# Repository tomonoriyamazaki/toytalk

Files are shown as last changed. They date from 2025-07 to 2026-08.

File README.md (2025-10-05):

# toytalk
SS Bootcamp 3rd #2025

## プロジェクト
- 声をかけると返答してくれるAIおもちゃの作成
- 目的は親の時間確保
- 子供がおもちゃに夢中になると同時に、言葉のキャッチボール力の向上もできたらうれしい
- OpenAIのAPIを利用するため、会話のたびに料金が発生する
- APIキーを発行してセットすれば、課金分のみの利用が可能
- APIキーの設定が面倒であれば、月額課金でも利用できる
- 無料で使用することも可能。会話はできないが、ただおうむ返しをしたり、事前にセットした昔話を話してくれる、という機能もあると親としては助かる（実際はサーバー維持費用かかるので検討中）
- おもちゃイメージ　「まねっこぴょこぴょこアンパンマン」
  - https://www.amazon.co.jp/gp/product/B0B4RQ85ZQ/ref=sw_img_1?smid=AN1VRQENFRJN5&th=1

## 音声会話のしくみ
  1. STT（音声→テキスト）
  2. LLM
  3. TTS（テキスト→音声）

前提として
  - OpenAIのAPIキーが必要。API利用のたびに課金が発生する
  - 音声処理はスマホ側で行うため、スマホアプリが必要。課金状況の確認などもアプリで行う

## PJの流れ
- デモサイト構築：マイク→音声→テキスト→LLM→音声返答してくれるサイトを作る　→6月完了
- ラズパイに落とし込む　→7月完了
- スマホアプリを作って、スマホと連動させる
- おもちゃとしてデザインを決めて形にする
- →一旦ここまで出来たらうれしい

サービス化するなら
- 何よりも応答速度が課題：デモサイト上では1往復で5秒前後かかる。すべての処理が直列なのと、サーバーレス構成のためと思われる　→　一旦解決。初回応答まで安定して2秒程度に短縮できた。しかもサーバーレス
  - STT：ここが足を引っ張っているように感じる。websocket通信で高速化できないか検討中　※ここをブラウザのテキスト化機能にしたら（つまりSSTをなくしたら）、往復で1-4秒と速度アップした
  - LLM：4.1-miniを利用。かなり早いはず
  - TTS：回答内容をまとめてmp3にしている？ためか長文だと時間かかるように感じる。子供向けということで、LLMの回答内容をシンプルにすることで短縮できないか
  - ※最悪難しかったら、待ってる間に「相槌を打つ」機能の追加を検討。「そうだね～」、「なるほどね」、「ふむふむ」とかいろいろなパターンを使って時間を稼げないか検討
  - →OpenAIのRealTime APIを使えば、SST→LLM→TTSをリアルタイム&並列化できるため爆速になる。ただ、これには2つのデメリットがある
    - 利用料が高い
    - ボイスをカスタマイズ（キャラクター化）できない
  - この対策として、以下が考えられる
    - STT、LLM、TTSそれぞれ、Stream対応のAPIを利用して、自前でWebRTC環境を整備する
    - TTS（ボイス化）についてはさらにカスタマイズできるものを選ぶ　※Microsoft EdgeTTSが有力
    - 一方で開発が長引く可能性が高いので、どこまで対応するか線引きが必要になりそう
    - 一旦、動作が安定してる現状のサーバーレス構成で進めて、RealTime API利用など検証しつつ落としどころを探る
  - 20250901：速度問題は一旦解決。サーバーレス構成（Lambda）でも、LLM/TTSをストリーム処理することで、話初めの速度を改善できた。STTは現在スマホ側で処理しているので、スマホによって性能の差がある可能性あり
  - 20251005：STTも解決。Soniox STTで一時キーを発行することで、クライアント⇔Soniox間で直接やり取りする。認証は別途必要だが速度には大きく影響しない想定。これで、STT→LLM→TTSの並列化ができ、応答も2秒程度となった
- 音声の精度を高める（くしゃみとか物音も拾ってしまう）　→　スマホでなら問題なし。くしゃみとかキーボードなら拾わない
- アプリ上で課金管理をできるようにする
- 過去の会話を踏まえて会話する機能。3-5つくらいまで保持しして、あとは要約するとか工夫できないか（会話積み重ねると重くなる）　→　実装済み
- APIキー管理の仕組みを設計・実装
- 会話保持、振り返り機能の実装
- 無料で利用する場合のおうむ返し機能、昔話をしてくれる機能の設計・実装
- ボイスとテンションを子供向けにする　→　いろいろなTTSを試しているが、なかなかない。リアルタイム性 + キャラっぽいのがあまりない。ニジボイスは申請中

## デモサイト　※対応済み
- https://toytalk.zakicorp.com/demo/index.html

### レビューいただいてからの修正点まとめ
- 音声を検知するまで何もしない処理にする
- キャラクター入れる
- アニメーション入れる
- キャラクター選択できる
  - 画像をそれぞれ用意する
- 処理時間を表示させる
- 会話ボタンを押したらずっと会話する　※キャンセルボタンないが、一旦再読み込みでキャンセルとなる
- 今までの会話を保持しながら話す
- iPhoneでも音声出力できるようにする
- デモサイトの構成図


### メモ：セキュリティ観点で本番は以下の設定が必要
| 設定項目 | 開発中 | 本番 |
| --- | --- | --- |
| `Access-Control-Allow-Credentials` | （なし） | `true`（必要なら） |
| CloudFront キャッシュキー | （特になし） | `Origin` を含めて設定 |
| APIキーの保護 | Lambda環境変数 | Secrets Manager利用（チーム開発でなければ必須ではない） |

## マイコン化について
- ラズパイだとおもちゃの価格が跳ね上がる。価格を抑えるためにはマイコン化が必要
- マイコン化すると、ラズパイと比べスペックがかなり落ちて機能も制限される
- そのため、おもちゃはマイク/スピーカーの中継にして、BlueTooth/wifiでスマホと連携して、スマホ側で音声処理をする構成にする
- そうすると、スマホアプリ起動が前提になるので、親としては子供がおもちゃと会話している間はスマホを操作できなくなってしまう可能性がある
- アプリをバックグラウンド起動させて対応できないか検討中　※最悪、親がスマホを触る際は、会話モード以外（オウム返しや一方的な話）で楽しんでもらう
- [ToyTalkマイコン実装はこちら](docs/mcu.md)

## ラズパイ対応 ver1　※対応済み
- デモサイトでやってること（ブラウザ部分）をラズパイに置き換えるだけ


- マイク/スピーカーはUSBタイプのものをそれぞれ用意してラズパイに装着
- VADは簡単なものを実装。咳や物音といった短い音を無視（0.4秒以内の音声は検知しない）
- 音声を流している間は、割り込みのマイク入力はoff　※ありだとスピーカーの音をマイクが拾う、の無限ループになるため。マイコン化を考えると制御の難易度が高そう
- 今後の課題も同じく、返答速度・声がメイン
  - 速度：①base64処理とmp3/wavの処理最適化、②システムプロンプトを会話特化に、③相槌機能追加（Lambdaの2重化）で、改善&カバーを検討
  - 声：今のOpenAI APIでチューニングしつつ、別のTTS用APIを検討

## ラズパイ対応 ver2　※対応済み
- スマホアプリ（一旦iOS）を作り、アプリ側で音声処理を行う。ラズパイはマイク/スピーカーの中継だけ（マイコン化に向けた対応）


- このあたりで速度改善、VAD、声のチューニングの本格対応を始める？マイコン化を優先？
- 一旦速度改善できた。Lambdaのストリーミング処理でLLM/TTSをそれぞれ並列化。STT（VADも）は一旦スマホ側で処理。今後SSTもサーバー側へ移行する
- iOSアプリのインストール（TestFlifhtというアプリも必要）：https://testflight.apple.com/join/Aq5D8b62
- [ToyTalkアプリ実装はこちら](app/README.md)
- 調査進めたところ、アプリ経由でなくても、おもちゃ（ESP32 s3という安価なマイコン）⇔中継サーバーで直接やりとりできそう。ver2の構成はとりやめて、ver3の構成にする

## ラズパイ対応 ver3　※対応済み
- SST（音声のテキスト化）をサーバー側に移行する　→　実装済み
- アプリによるラズパイへのwifi設定は実装していないが、マイコン化が実現できそうなのでそちらを優先で対応する


## マイコン対応　※対応中
- スマホアプリを経由せず、マイコン⇔API基盤（STT + LLM + STT）で音声会話できるか検証
- wifi設定もアプリからできるようにする


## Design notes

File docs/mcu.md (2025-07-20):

# マイコン
このページは、ToyTalkのマイコン版（ESP32などを用いた構成）のパーツリストや接続、実装メモをまとめたものです。

## パーツ一覧
### マイコン部品
- メイン基盤：ESP32‑S3 DevKitC USB‑C 開発ボード：USB‑C給電、BLE・WIFI・I²S完備。
Espressif純正で信頼性高く、260MHzデュアルCPU、8 MB Flash & 2 MB RAM 
- マイク：INMP441 I²S MEMSマイクモジュール：高性能24bit/48 kHz I²S出力対応マイク。：ノイズに強い
- アンプ：MAX98357A I²S アンプモジュール：I²S信号→アナログ変換＋D級アンプ内蔵。
小型でも3 W駆動可能でスピーカ接続に最適。
- スピーカー：40 mm 8 Ω スピーカー　：ほどよい音量と品質。
- ブレッドボード（400～830穴）	：部品仮組用
- ジャンパーワイヤ（オス‑メス／40本）：各部品を安定接続。色分けで配線ミスも防げる。
- バッテリー：薄型LiPo（654060）	3.7V / 2000mAh / 厚さ6.5mm
- バッテリー補助①：TP4056（USB-C・保護付き）
- バッテリー補助②：MT3608：電圧を3.7V→5Vにして、ESP32に電力供給できるようにする
- ミニスライドスイッチ：3 pin 2mm
- JSTケーブル：バッテリー用。JST PH 2.0mmピッチ 2ピン 10CM
- レジスター：LED用。一式のセット
- LED：RGB 5mm。1つのランプで複数色を実現　※ちょい複雑になりそう
- プッシュボタン：色々セットで試す
- スピーカー用ワイヤ：22AWG silicone wire red black
- 絶縁チューブ：色々セットで試す

### 工具
- はんだごて
- テスター
- ノギス
- ニッパー
- 3M：絶縁テープ、両面テープ、マスキングテープ

### 今後必要なもの（本番向け）
- ユニバーサル基板：72x47mmくらい？
- ぬいぐるみ化に必要な素材
- 裁縫セット・マジックテープ
- 声の出口用 メッシュ布 or プラスチックメッシュ
- ユニバーサル基板（両面タイプ）
- ピンヘッダ／ピンソケット：モジュールの取り外しや交換できるように
- タクトスイッチの台座 or 小基板：押しやすく＆がたつき防止
- スペーサー・ネジセット（M2/M2.5）：スピーカーや基板の仮固定に便利
- DCジャック変換プラグ：USB-Cでの電源供給からモバイルバッテリーにも流用可
- ホットボンド or 小型グルーガン：固定用や絶縁補強に使える。低温型が安心

## 設計
これから

## 構成図
これから

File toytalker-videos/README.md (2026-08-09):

# toytalker-videos

ToyTalker TIB FAB 展示用の説明動画シリーズ(Remotion / React + TypeScript)。
制作指示書は `reference/README_toytalker_videos.md`、応答速度本編のタイミングの正は `reference/render.py`(PILプロトタイプ)。

トーンは親子向けの明るいクリーム背景(2026-08-03改訂)。全体構成:

| # | セクション | 尺 | 担当 |
|---|---|----|---|
| 1 | 会話 | 30 | 実写撮影 |
| 2 | コンセプト | 22 | 本プロジェクト(ペンダント装着→子供の会話→親の振り返り、B/C/締めホールドあり) |
| 3 | 応答速度 | 44.5 | 本プロジェクト(3ステップ説明13.5秒 + パイプライン本編3.6倍スロー) |
| 4 | 声変え | 26 | 本プロジェクト(アプリでキャラ作成→おもちゃに反映、クローンボイス、まとめ以外2倍スロー) |
| 5 | 製作 | 30 | スライド+3Dプリンタ動画 |
| 6 | 操作 | 25 | 操作画面撮影 |

## 使い方

```bash
npm install

# プレビュー(ブラウザでStudioが開く)
npm run studio

# mp4出力(1920x1080 / 30fps / H.264 crf18 / faststart)
npm run render:concept          # → out/toytalker_concept.mp4
npm run render:response-speed   # → out/toytalker_response_speed.mp4
npm run render:voice-change     # → out/toytalker_voice_change.mp4
npm run render:all              # 3本まとめて
```

## 構成

| パス | 内容 |
|---|---|
| `src/theme.ts` | カラー・サイズ・字幕スタイルのトークン。ブランドカラー確定時はここだけ差し替える |
| `src/fonts.ts` | Noto Sans JP(Google Fonts)のロード |
| `src/components/Subtitle.tsx` | 共通字幕。切り替え時0.3秒クロスフェード。サイズは `CAPTION.fontSize`(48、最大56まで想定) |
| `src/components/StageCard.tsx` | パイプライン段カード(STT/LLM/TTS/デバイス) |
| `src/components/Pill.tsx` | チャンクピル(テキスト/音声/再生中の3状態、再生中は波形バー内蔵) |
| `src/components/Waveform.tsx` | 波形バーアニメ(サイズ可変) |
| `src/components/Pendant.tsx` | ペンダント型デバイス(4cm)のイラスト表現 |
| `src/components/PhoneFrame.tsx` | アプリ画面のスマホフレーム |
| `src/videos/Concept.tsx` | 動画2「コンセプト」(22秒、装着→会話→振り返り→締め) |
| `src/videos/ResponseSpeed.tsx` | 動画3「応答速度」(44.5秒、3ステップ説明+パイプライン本編3.6倍スロー) |
| `src/videos/VoiceChange.tsx` | 動画4「声変え」(26秒、アプリ設定→反映、キャラ音声→クローン) |
| `src/Root.tsx` | 合成定義。尺・fps・解像度はここで一元管理 |

## デバイス実機写真のはめ込み

1. 写真を `public/` に置く(例: `public/toytalker_mini.png`)
2. `src/theme.ts` の `DEVICE_PHOTO` にファイル名を設定:
   ```ts
   export const DEVICE_PHOTO: string | null = 'toytalker_mini.png';
   ```
3. 応答速度のデバイスカード右側と、コンセプトの中央ビジュアル(🧸プレースホルダーと差し替え)に自動反映される

## 今後

- 実機写真の支給待ち(`DEVICE_PHOTO` 設定のみで反映)
- 実写パート(1, 5, 6)は DaVinci Resolve 編集。字幕スタイルは `theme.ts` のトークンを参照して合わせる

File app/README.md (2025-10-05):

# ToyTalk App

- ToyTalk アプリの React Native / Expo プロジェクトです。
- iOS / Android アプリのソースコードをこのディレクトリで管理しています。
- 現在はiOSのみ稼働

---
## ツール
- React Native	：JavaScript。node.jsを使う
- Expo          ：RNのツール群。アカウント登録が必要
- EAS			      ：Expoのクラウドサービス。ビルドを手軽にしてくれる
- .ipa			    ：ビルド後にできるiOSアプリのバイナリコード
- xcode			    ：ビルド&検証ツール。今回はEASに任せるので使わない

## 環境
- 開発端末       ：Windows PC 1台でok。これで開発～検証までできる。VSCodeにgit bashを入れておく
- 入れるもの     ：nodejsをサイトからとってきて入れる　→　npm(nodejsのインストーラ)コマンドでexpo,eas群のツールを入れる

### iOSアプリの検証方法
- 流れ          ：コード書く　→　簡易検証　→　実機検証　→　TestFlight（iOSアプリに登録する前の段階のもの）にアップ
- 簡易検証       ：アプリのUIとか操作感とかをさくっと確認できる。npx expo start -cコマンドしたら、QRでるので、アプリ側にexpo go入れた状態でカメラ読み取りでok。ただマイクとか機器自体の機能があるとNGになるので、途中からは使えなくなる
- 実機検証初期設定：iPhoneのデバイス登録をしたり必要なツールを導入する
  - npm i -g eas-cli             ：EASを入れる
  - npm i -D expo-dev-client     ：Expoの検証用ツールを入れる
  - eas device:create            ：証明書設定してデバイスを登録する。前提としてapple developper（1.5万円/年かかる）に登録。スマホを新しくしたら、コマンドではデバイス追加がうまくいかなかったので、developerサイト上で手動でデバイス追加→プロファイル上でデバイス登録→eas credentialsでプロフィル削除→buildで認識された
  - eas.jsonの修正               ：ビルドのprofileを設定する。development = 実機検証1、preview = 実機検証2、testflight = TestFlight用で今回は設定。3つ作ったが、正直、preview = testflight用でよかった
- 実機検証1      ：これがメイン。マイクなどのiPhoneの機能を使うために必要。PC側でのサービス起動が必要だが、毎回buildしないで済むので素早く検証できる
  - eas build --platform ios --profile development    ：ビルド。10分以上かかる。ネイティブ系やapp.jsonの変更がある場合は都度buildする。jsコードなどの場合は不要。QRコードが発行されるのでそこからダウンロードする。
  - npx expo start --dev-client --host tunnel  ：このコマンドでサービスが立ち上がる。起動中の間だけアプリを利用できる。QRを読み込んでアプリを利用する
- 実機検証2       ：実質不要。PC側でサービス起動（expo start）しなくてもアプリ検証できる。でもjsコードを修正したら毎回buildしないといけないのでほぼ使わない。ここで検証せずにtestflightへ登録でok
  - eas build --platform ios --profile preview    ：ビルド。10分以上かかる。QRコードが発行されるので、ダウンロードすれば利用可能
- TestFlight    ：iOSアプリとして登録する前段階の検証サイト。ここにアップしたら、URLが発行できるようになる。これも初回手続きが面倒
  - eas.jsonの修正               ：ビルドのprofileを設定する。今回はtestflightを追加。distorbutionにstoreを指定する
  - eas build --platform ios --profile testflight   ：ビルド。ここに10分以上かかる
  - eas submit --platform ios --latest  ：TestFlightに提出するコマンド
  - apple connectサイトでのTestFlightテスター設定      ：テスターには内部と外部がいるが、内部だとApple ID登録するとか面倒。外部だと審査下りればみんな使える→外部を設定する→URLが発行される。審査は1-2日?で基本通る
  - →URLが発行されたら、それを共有する→testflightアプリ経由で、対象アプリのインストールができるようになる

### Android

（未設定）

---

## ✅ 完了
* スプラッシュなし
* アイコン追加
* TestFlight のアップロードと外部公開
* 権限まわり（マイク、通知）の実装
* 会話機能実装　※STTはスマホ依存

## 機能追加
* おもちゃのwifiを設定できるようにする
* ログ機能追加

## 改善
* 話している内容を保持する　→　OK
* 時間計測できるようにした（DEGUB_TIMEでon/off）　→　OK
* マイク開始中は音声会話ずっとできるように　→　OK
* マイク開始中、スマホから出る音声が入力されてしまう防ぐ or 出力中は入力止める　→　OK。出力中は止める
* 文字入力画面になると入力中の文字が見えなくなる
* 下に自動スクロールさせたい
* 文字区切りがおかしい
* ボイスのテンションが安定しない。↑が原因なのもある。4o-ttsに雰囲気の指定ができるので試す　→　いろいろなTTSをお試し中。ニジボイス申請中

```

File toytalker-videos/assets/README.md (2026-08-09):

# assets

実機写真・ロゴ等の元素材置き場。

動画に使う画像は Remotion の仕様上 `public/` に置く必要がある。
ここには元データ(高解像度写真など)を保管し、加工済みを `public/` にコピーして使う。

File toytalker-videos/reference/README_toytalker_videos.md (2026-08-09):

# ToyTalker TIB FAB 展示動画シリーズ — 制作指示書

## このドキュメントについて

claude.ai 上で作成した「応答速度」説明動画のプロトタイプ(`toytalker_response_speed.mp4` + `render.py`)を出発点に、TIB FAB 展示用の動画6本シリーズを制作するためのプロジェクト指示書。Claude Code に渡して、Remotion ベースの共通テンプレートプロジェクトとして立ち上げることを想定している。

## 背景と展示条件

- ToyTalker(AI会話デバイス)の TIB FAB 展示ブースで流す説明動画シリーズ
- **音声なし(サイレント再生)+ 字幕前提**。字幕の視認性が最重要
- 各動画は**単体ループ再生**を想定。終端→先頭が自然につながるようフェードで処理する
- 通しで流す場合の全体構成は以下(数字は秒数):

| # | セクション | 尺 | 形式 | 状態 |
|---|---|----|---|---|
| 1 | 会話 | 30 | 実写動画 | 別途撮影 |
| 2 | コンセプト | 15 | アニメ | 本プロジェクトで制作 |
| 3 | 応答速度 | 15 | アニメ | **プロトタイプ済み(本書のベース)** |
| 4 | 声変え | 15 | アニメ | 本プロジェクトで制作 |
| 5 | 製作 | 30 | 実写動画 or アニメ | 検討中 |
| 6 | 操作 | 25 | 実写動画 or アニメ | 検討中 |

※ 実写パートは DaVinci Resolve で編集。本プロジェクトの担当はアニメパート(2, 3, 4 を優先)。実写パートにも字幕・テロップの共通スタイルを流用したいので、字幕デザインはトークンとして独立させておくこと。

## 技術構成の指定

- **Remotion**(React + TypeScript)で制作し、mp4 を出力する
- プロトタイプは Python PIL + ffmpeg 製(`render.py` 同梱)。これは仕様書として参照し、Remotion に移植する
- 共通仕様:
  - 解像度 **1920×1080**、**30fps**
  - 各動画の尺は上表に従う(フレーム数 = 秒 × 30)
  - 末尾 0.8 秒でフェードアウトし、ループ時に先頭へ自然に戻す
  - コーデック: H.264、`-crf 18` 相当の高品質、`faststart`
- プロジェクト構造の提案:

```
toytalker-videos/
├── src/
│   ├── theme.ts              # カラー・フォント・字幕スタイルのトークン
│   ├── components/
│   │   ├── Subtitle.tsx      # 共通字幕(番号付きキャプション)
│   │   ├── StageCard.tsx     # パイプライン段カード(STT/LLM/TTS/デバイス)
│   │   ├── Pill.tsx          # チャンクピル(テキスト/音声/再生中の3状態)
│   │   └── Waveform.tsx      # 再生中の波形バーアニメ
│   ├── videos/
│   │   ├── ResponseSpeed.tsx # 3. 応答速度(最初に移植)
│   │   ├── Concept.tsx       # 2. コンセプト
│   │   └── VoiceChange.tsx   # 4. 声変え
│   └── Root.tsx
├── assets/                   # 実機写真・ロゴ等
└── reference/
    ├── render.py             # PILプロトタイプ(タイミングの正)
    └── toytalker_response_speed.mp4
```

## デザインシステム(プロトタイプ準拠)

`theme.ts` に以下をトークン化する。

### カラー

| 用途 | Hex |
|---|-----|
| 背景 | `#0F1220` |
| カード(非アクティブ) | `#1A1E30` |
| カード(アクティブ) | `#232048` |
| ボーダー(通常) | `#2A2F48` |
| アクセント紫(アクティブ枠・カーソル) | `#7F77DD` |
| テキスト(主) | `#ECEDF5` |
| テキスト(副) | `#9AA0B8` |
| ピル・テキストチャンク(塗り/文字/枠) | `#3C3489` / `#CECBF6` / `#534AB7` |
| ピル・音声チャンク(塗り/文字/枠) | `#085041` / `#9FE1CB` / `#1D9E75` |
| ピル・再生中(塗り/文字) | `#1D9E75` / `#E1F5EE` |
| 強調ティール(まとめ画面の大見出し) | `#9FE1CB` |

※ 将来 ToyTalker ブランドカラーが確定したら theme.ts の差し替えだけで全動画に反映できるようにする。

### タイポグラフィ

- フォント: **Noto Sans CJK JP**(Regular / Bold)
- サイズ(1080p 基準):
  - タイトル 46px Bold / ステージ名 40px Bold / 本文 38px / ピル 34px / レーンラベル 30px / 補足 28px
  - **字幕キャプション 48px Bold**(下部中央、角丸背景 `#1A1E30` 90% 不透明、左右パディング 40px)
  - まとめ画面: 大見出し 72px Bold、前後行 40px
- 展示では 2〜3m 離れて見る想定。字幕は 48px を下限とし、必要なら 56px まで上げられるよう変数化する

### モーション

- 要素の出現: opacity 0→1 + 上方向 18px スライド、cubic ease-out 0.35 秒。Remotion では `spring()` に置き換えて自然にしてよい
- タイピング(文字送り): 等速で 1 文字ずつ
- ストリーミングカーソル: `▍` を 1Hz 点滅
- 再生中波形: 4 本バー、`sin(t*7 + i*1.1)` の高さ揺れ(Waveform.tsx として共通化)

## 動画3「応答速度」タイムライン(15.0 秒 / 450 フレーム)

プロトタイプ mp4 と完全一致させること。`render.py` が正。

### 画面レイアウト

- 上部: タイトル「応答速度のしくみ — すべてを並行に、待たない設計」
- その下: 4 ステージカード横並び(STT 音声認識 / LLM 返答生成 / TTS 音声合成 / デバイス 再生)、間を「→」で接続。カードは 400×150px、ステータス行つき
- 中段: 4 レーン(ユーザー発話 / LLM ストリーム / TTS キュー / デバイス再生)、ラベル左、区切り線あり
- 下部: 字幕キャプション

### イベント表(秒)

| 時刻 | イベント |
|---|---|
| 0.2 | ユーザー発話ピル「●「こんにちは」」出現、STT アクティブ化(ステータス「認識中…」)、字幕①「発話をSTTがリアルタイムに文字起こし」 |
| 0.8–1.7 | 「文字起こし: こんにちは」を 1 文字ずつ表示 |
| 1.75 | STT ステータス「確定 → 即LLMへ」 |
| 1.8 | LLM アクティブ化(「ストリーミング生成中…」)、字幕②「確定した瞬間、即LLMへ。返答はストリーミング生成」 |
| 1.9–5.6 | LLM レーンに「こんにちは!今日はいい天気だね。何をお話ししようか?」を等速タイピング、カーソル点滅 |
| 2.9 | TTS キューにピル「こんにちは!」出現、TTS アクティブ化(「文の区切りごとに合成」)、字幕③「文の区切りごとに、生成完了を待たずTTSへ」 |
| 3.6 | デバイス再生に「♪ こんにちは!」出現・**即再生中状態**(緑・波形バー)、デバイスアクティブ化(「再生中」)、「バッファ: 0」表示、字幕④「最初の音声が届き次第、すぐ再生開始」 |
| 4.35 | TTS キューにピル「今日はいい天気だね。」 |
| 5.05 | デバイス再生に「♪ 今日はいい天気だね。」(待機=濃緑)、「バッファ: 1」、字幕⑤「再生の裏で、後続の音声をため込む」 |
| 5.7 | LLM タイピング完了、ステータス「生成完了」、カーソル消灯 |
| 5.75 | TTS キューにピル「何をお話ししようか?」 |
| 6.45 | デバイス再生に「♪ 何をお話ししようか?」、「バッファ: 2」 |
| 7.0 | 再生が 2 個目に移る(1 個目は待機色へ、2 個目が再生中色+波形)、「バッファ: 1」、字幕⑥「生成を待たずに連続再生」 |
| 8.8 | 再生が 3 個目に移る、「バッファ: 0」 |
| 10.6 | 再生完了(デバイスステータス「再生完了」) |
| 11.0 | 画面を 85% 暗転オーバーレイ → まとめ画面フェードイン:「発話の終わりから、返事が聞こえるまで」(40px 副色)/「体感レイテンシ 1秒以下」(72px ティール)/「認識・生成・合成・再生 — すべてが同時に走っている」(40px 主色) |
| 14.2–15.0 | 全体フェードアウト(ループ用) |

## Remotion 移植時の改善要望

1. 出現アニメを `spring()` ベースにしてヌルヌルさせる(タイミングの開始時刻は表の通り厳守)
2. デバイスカード内に **ToyTalker Mini の実機写真**をはめ込めるようにする(assets/ に写真を置いたら差し替わる作り。写真は後日支給)
3. 波形バーをピル内に統合し、再生中ピルの見た目をリッチに
4. 字幕コンポーネントは切り替え時にクロスフェード(0.3 秒)
5. 尺・fps・字幕サイズは Root.tsx の合成定義で一元管理

## 動画2「コンセプト」/ 動画4「声変え」の方向性メモ(詳細は別途相談)

- **コンセプト(15秒)**: 「ぬいぐるみが、話し相手になる。」を軸に、デバイス写真+短いコピーが順に出るシンプルなモーションタイポグラフィ。パイプライン図は出さない
- **声変え(15秒)**: 同じセリフの吹き出しが、VOICEVOX キャラ声 → クローン音声(家族の声)と切り替わる様子を波形の色変化で表現。「声もえらべる。つくれる。」で締め
- いずれも共通コンポーネント(Subtitle / Pill / Waveform)を流用する

## 進め方

1. `reference/render.py` と mp4 を確認し、Remotion プロジェクトを scaffold
2. ResponseSpeed.tsx をタイムライン表どおりに移植 → mp4 出力してプロトタイプと見比べ
3. 改善要望 1〜5 を適用
4. Concept / VoiceChange の絵コンテを提案 → 合意後に実装

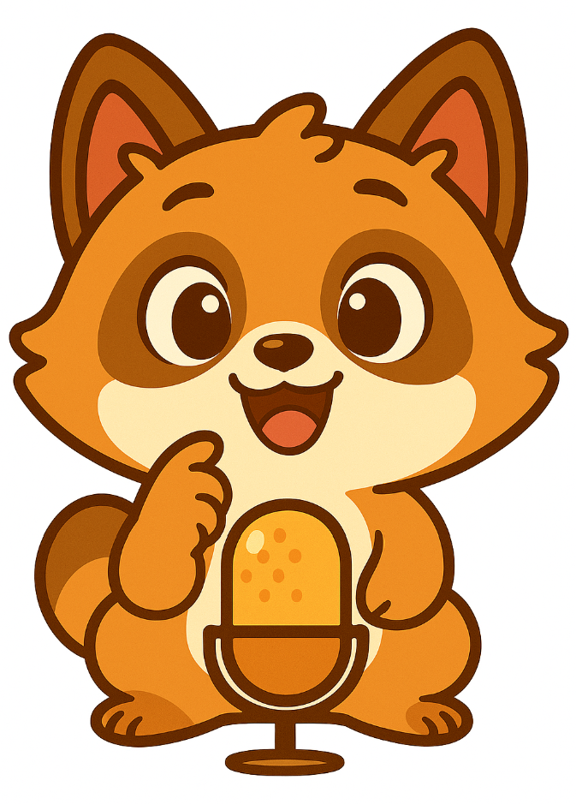
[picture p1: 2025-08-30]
app/assets/images/mascot.png

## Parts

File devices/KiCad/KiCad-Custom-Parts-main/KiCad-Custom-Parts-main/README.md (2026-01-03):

# KiCad-Custom-Parts

Repository to hold custom symbols, footprints, etc created for use in KiCad.

## Parts added (Symbols)

- TP4056 USB Module  
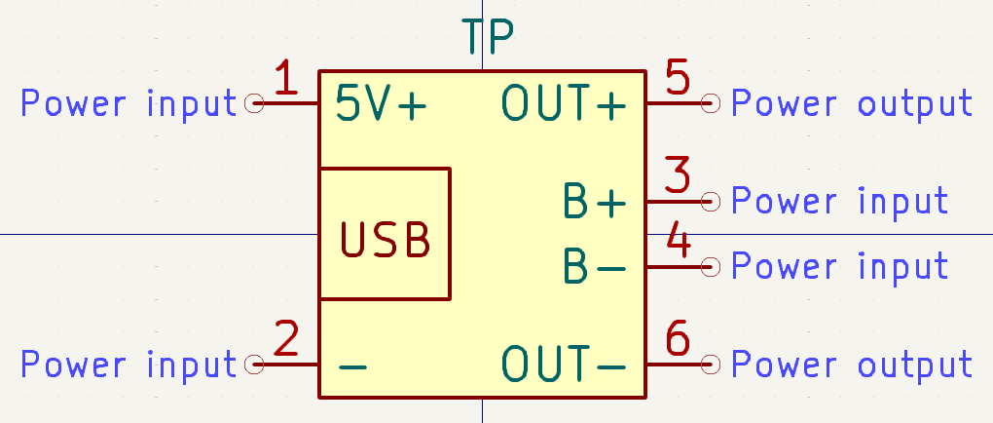
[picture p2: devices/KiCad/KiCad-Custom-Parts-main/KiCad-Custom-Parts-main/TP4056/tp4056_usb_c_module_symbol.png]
TP4056
  

- MPU6050 Gyroscope Module  
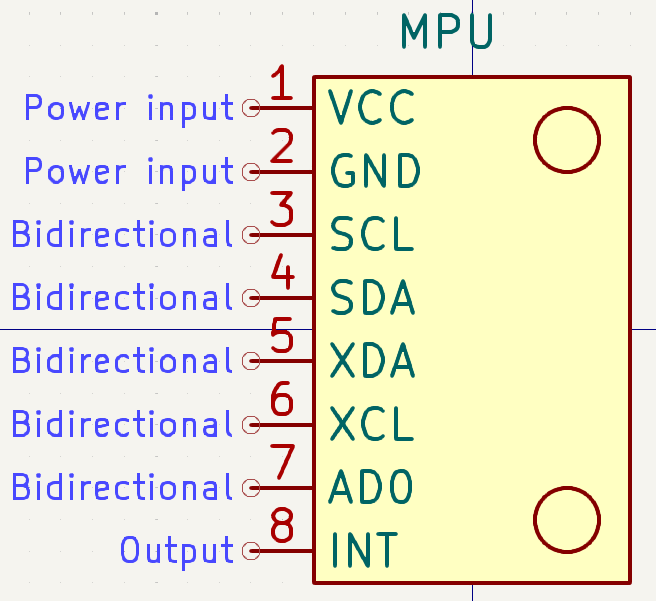
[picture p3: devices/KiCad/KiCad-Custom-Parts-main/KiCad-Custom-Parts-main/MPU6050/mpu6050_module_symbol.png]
MPU6050 Gyroscope Module
  

- Waveshare ESP32-S3 Mini/Zero Development Board  
  https://www.waveshare.com/product/esp32-s3-zero.htm  
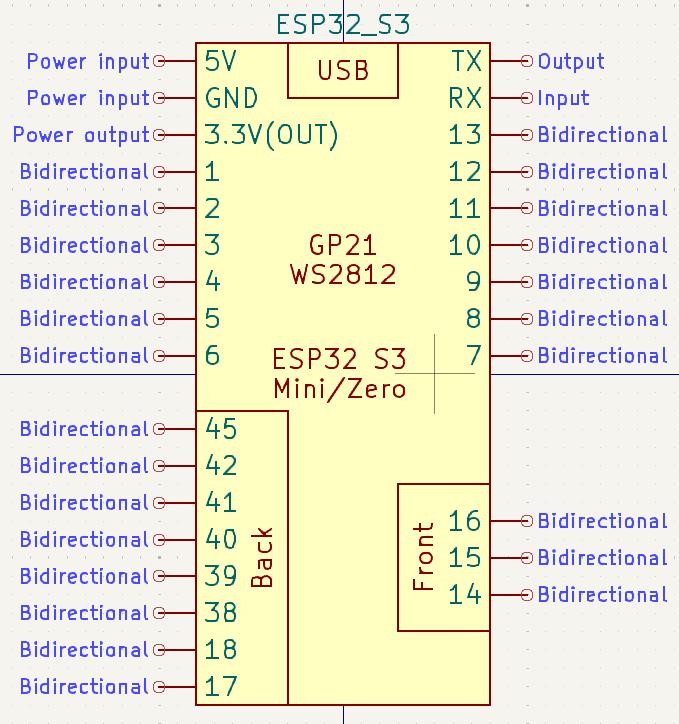
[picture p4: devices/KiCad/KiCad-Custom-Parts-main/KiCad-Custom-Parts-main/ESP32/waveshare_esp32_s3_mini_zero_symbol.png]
Waveshare ESP32-S3 Mini/Zero Development Board
  

- ESP32-DEVKIT-V1-30Pin  
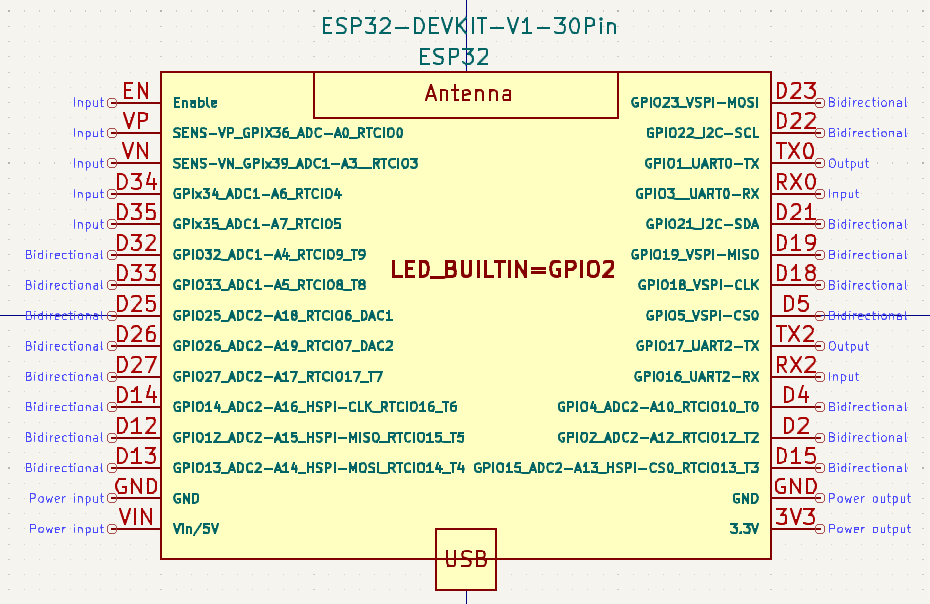
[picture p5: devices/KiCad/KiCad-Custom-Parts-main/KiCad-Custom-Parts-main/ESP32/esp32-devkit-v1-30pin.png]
ESP32-DEVKIT-V1-30Pin
  

- DS3231 RTC For RaspberryPi  
  https://vishaworld.com/products/ds3231-high-precision-rtc-clock-module-for-raspberry-pi-with-battery  
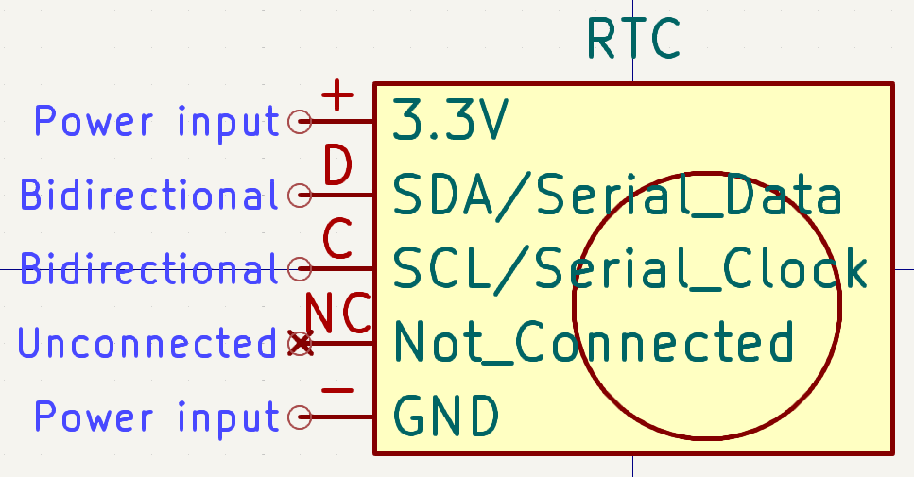
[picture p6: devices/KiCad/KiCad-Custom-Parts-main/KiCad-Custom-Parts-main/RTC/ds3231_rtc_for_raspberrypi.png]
DS3231 RTC For RaspberryPi
  

- INMP441 Microphone I2S  
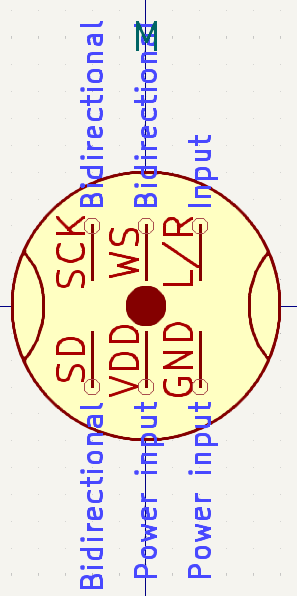
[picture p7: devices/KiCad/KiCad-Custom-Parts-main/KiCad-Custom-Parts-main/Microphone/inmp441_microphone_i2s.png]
INMP441 Microphone I2S
  

- WS2812B LED Strip  
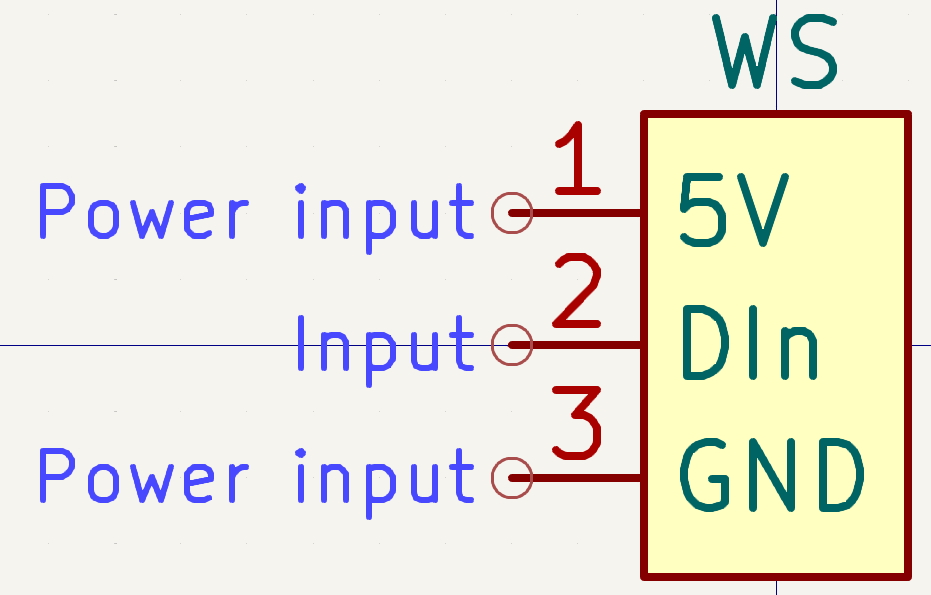
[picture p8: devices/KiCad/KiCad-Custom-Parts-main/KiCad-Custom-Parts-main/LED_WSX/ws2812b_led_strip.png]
WS2812B LED Strip
  

- WS2812B Concentric Ring  
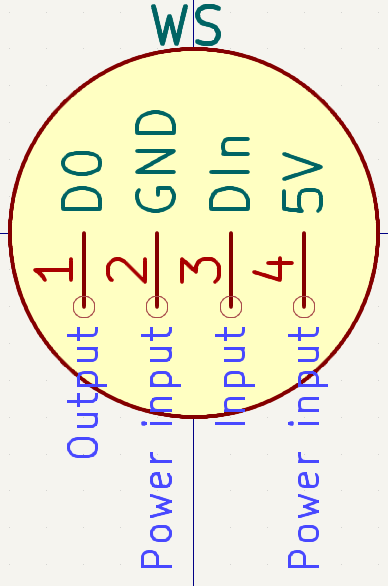
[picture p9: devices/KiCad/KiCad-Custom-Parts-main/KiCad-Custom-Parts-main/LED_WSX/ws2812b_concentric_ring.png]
WS2812B Concentric Ring


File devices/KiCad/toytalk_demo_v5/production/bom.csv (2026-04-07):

Designator | Footprint | Quantity | Value | LCSC Part #
C1, C12, C8 | 0603 | 3 | 10uF
C10 | 0603 | 1 | 1uF
C11, C4, C5 | 0603 | 3 | 0.1uF
C2, C3, C6, C7, C9 | 0603 | 5 | 22uF
D1 | LED_KT-0805W | 1 | KT-0805W
J1 | HRO_TYPE-C-31-M-12 | 1 | TYPE-C-31-M-12
L1 | IND-SMD_L7.2-W6.6_GPSR0730 | 1 | CYA0630-1.0UH | C5189744
MK1 | MIC_SPH0645LM4H-B | 1 | SPH0645LM4H-1-8
R1, R2 | 0603 | 2 | 5.1k
R10 | 0603 | 1 | 1.1k
R3 | 0603 | 1 | 47
R4 | 0603 | 1 | 732k
R5 | 0603 | 1 | 100k
R6, R8, R9 | 0603 | 3 | 10k
R7 | 0603 | 1 | 2.4k
S1 | SW_SSAJ110100 | 1 | SSAJ110100
S2, S3 | SW_SKRPABE010 | 2 | SKRPABE010
U1 | XCVR_ESP32S3WROOM1N8R8 | 1 | ESP32-S3-WROOM-1-N8R8
U2 | BGA9N40P3X3_134X143X69N | 1 | MAX98357AEWL_T
U3 | QFN50P300X300X100-17N | 1 | BQ24074RGTR
U4 | SOT95P285X140-5N | 1 | AP2112K-3.3TRG1
U5 | CONV_TPS61022RWUR | 1 | TPS61022RWUR

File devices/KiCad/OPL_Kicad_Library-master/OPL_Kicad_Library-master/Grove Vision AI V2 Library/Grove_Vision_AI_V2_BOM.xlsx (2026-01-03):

Layer Jump | Number | Name | Specification | Operating Temperature | MPN Code | Quantity | Base | Plug Position | Process
N | 301010000 | SMD RES 0R-5%-1/16W;0402 |  | -55°C to 155°C | RC0402JR-070RL | 3 | 1 | R29,R30,R39 | SMT1
N | 301010004 | SMD RES 10K-5%-1/16W;0402 |  | -55°C to 155°C | RC0402JR-0710KL | 7 | 1 | R5,R7,R8,R23,R24,R31,R38 | SMT1
N | 301010008 | SMD RES 510K-5%-1/16W;0402 |  | -55°C to 155°C | RC0402JR-07510KL | 1 | 1 | R35 | SMT1
N | 301010456 | SMD RES 100K-1%-1/16W;0402 |  | -55°C to 155°C | RC0402FR-07100KL | 7 | 1 | R6,R10,R11,R16,R32,R33,R37 | SMT1
N | 301010495 | SMD RES;5.1K-1%-1/16W;0402 |  | -55°C to 155°C | RC0402FR-075K1L | 3 | 1 | R2,R3,R36 | SMT1
N | 301010746 | SMD RES 2.2K-1%-1/16W;0402 |  | -55°C to 155°C | RC0402FR-072K2L | 10 | 1 | R1,R4,R13,R14,R15,R19,R20,R21,R22,R40 | SMT1
N | 301011331 | SMD RES 22.1K-1%-1/16W;0402 |  | -55°C to 155°C | RC0402FR-0722K1L | 2 | 1 | R26,R34 | SMT1
N | 302010004 | SMD CAP Ceramic 100nF-16V-10%-X7R;0402 |  | -55°C to 125°C | CC0402KRX7R7BB104 | 18 | 1 | C5,C8,C13,C20,C21,C22,C23,C24,C25,C26,C27,C29,C30,C31,C32,C35,C36,C39 | SMT1
N | 302010006 | SMD CAP Ceramic 10nF-50V-10%-X7R;0402 |  | -55°C to 125°C | CC0402KRX7R9BB103 | 1 | 1 | C3 | SMT1
N | 302010049 | SMD CAP Ceramic 12pF-50V-5%-NPO;0402 |  | -55°C to 125°C | CC0402JRNPO9BN120 | 2 | 1 | C14,C15 | SMT1
N | 302010051 | SMD CAP Ceramic 220nF-16V-10%-X7R;0402 |  | -55°C to 125°C | CC0402KRX7R7BB224 | 1 | 1 | C16 | SMT1
N | 302010407 | SMD CAP Ceramic 4.7uF-10V-10%-X5R;0402 |  | -55°C to 85°C | CC0402KRX5R6BB475 | 7 | 1 | C4,C6,C7,C9,C10,C28,C34 | SMT1
N | 302010519 | SMD CAP Ceramic 10uF-10V-20%-X5R;0402 |  | -55°C to 85°C | CC0402MRX5R6BB106 | 2 | 1 | C11,C37 | SMT1
N | 302013249 | SMD CAP Ceramic 1uF-10V-10%-X5R;0402 |  | -55°C to 85°C | CL05A105KP5NNNC | 5 | 1 | C1,C2,C17,C18,C19 | SMT1
N | 303010544 | SMD Inductor 4.7uH-20%-1.1A;0806 |  | -40°C to 105°C | VLS201610HBX-4R7M-1 | 1 | 1 | L1 | SMT1
N | 303011858 | SMD Inductor 470nH-20%-2.6A;0603 |  | -40°C to 125°C | TFM160808ALC-R47MTAA | 2 | 1 | L2,L3 | SMT1
N | 304011053 | SMD Diode Schottky 40V-1A;SOD-323 |  |  | B5819WS SL | 4 | 1 | D1,D2,D3,D4 | SMT1
N | 304090121 | SMD LED Clear-Green;0402 | As posted |  | BL-HGE37A-AV-TRB | 1 | 1 | LED2 | SMT1
N | 304090746 | SMD LED Clear-Yellow;0402 | As posted |  | 16-213/Y2C-AN2Q1B/3T | 1 | 1 | LED1 | SMT1
N | 305030071 | SMD MOSFET N-CH 20V-500mA;SOT-523 |  |  | CJ1012 | 5 | 1 | Q1,Q2,Q3,Q4,Q5 | SMT1
N | 306011444 | SMD Crystal;24MHz-12pF-10ppm-4P-2.0*1.6*0.5mm |  | -40°C to 85°C | Y2400FE001 | 1 | 1 | X1 | SMT1
N | 310011697 | SMD IC MCU;Dual Cortex-M55 Core(Max 400MHz)-With a 400MHz NPU;WLCSP-65 | L5.58*W2.27mm | -40°C to 85°C | HX6538-A01TWA | 1 | 1 | U1 | SMT1
N | 310032794 | SMD IC PMIC;DCDC Buck-ADJ-2.2MHz-4A;DFN1.5×1.5-6 |  | -40°C to 85°C | SY80004DQD | 2 | 1 | U4,U6 | SMT1
N | 310032813 | SMD IC PMIC;LDO-1.8V-300mA;XTDFN-1*1-4L |  | -40°C to 125°C | SGM2036S-1.8XXDH4G/TR | 1 | 1 | U3 | SMT1
N | 310071431 | SMD IC Interface USB to High Speed TTL;QFN16 | USB to High-Speed Serial Port | -40°C to 85°C | CH343P | 1 | 1 | U2 | SMT1
N | 310091468 | SMD IC Memory;128Mbit-1.8V;SOIC-8 |  | -40°C to 85°C | W25Q128JWSIQ | 1 | 1 | U5 | SMT1
N | 311020009 | SMD Top Button 4N;4P-L4.6*W3.2*H2.5mm |  | -20°C to 70°C | SKRPADE010 | 1 | 1 | RST1 | SMT1
N | 311020518 | SMD Top Button 1.57N;4P-L4.6*W3.2*H2.5mm |  | -30°C to 85°C | SKRPABE010 | 1 | 1 | BOOT1 | SMT1
N | 312030502 | SMD DIGITAL MIC OMNI -26dBFS;OCLGA-4:3.5*2.65*0.94mm |  | -40˚C to 100˚C | MSM261D3526H1CPM | 1 | 1 | MIC1 | SMT1
N | 319015667 | PCB;Grove - Vision AI Module V2 -蓝油白字-4层 | 20*40*1.6mm-ENIG-FR4;Steel mesh code；404012305 |  |  | 1 | 1 |  | SMT1
N | 320011358 | SMD USB TYPE C-W/P;12+4P-8.94*7.35*3.26mm |  | -30°C to 85°C | USB-31C-F-16P-L7.35 | 1 | 1 | J1 | SMT1
N | 320031231 | DIP Black Female Header VERT;1*7P-2.54-5.0mm |  | -40℃ to 105℃ |  | 2 | 1 | P8,P9 | Unit
N | 320060904 | SMD FPC CONN Bottom Contact;15P-1.0mm;L19.9*W6.76*H2.0mm |  | -30°C to 85°C | ST-FPC-W102015-D | 1 | 1 | J2 | SMT1
N | 320090535 | SMD uSD Card Holder;9+4P-L11.25*W6.96*H1.42mm |  | -25°C to 70°C | ST-TF-MR267 | 1 | 1 | J5 | SMT1
N | 320110032 | SMD Grove Female Header-Beige;4P-2.0-90D | 2.0-4PHorizontal Mount with Locking Socket |  | PHS-4A horizontal mount | 1 | 1 | J3 | SMT1

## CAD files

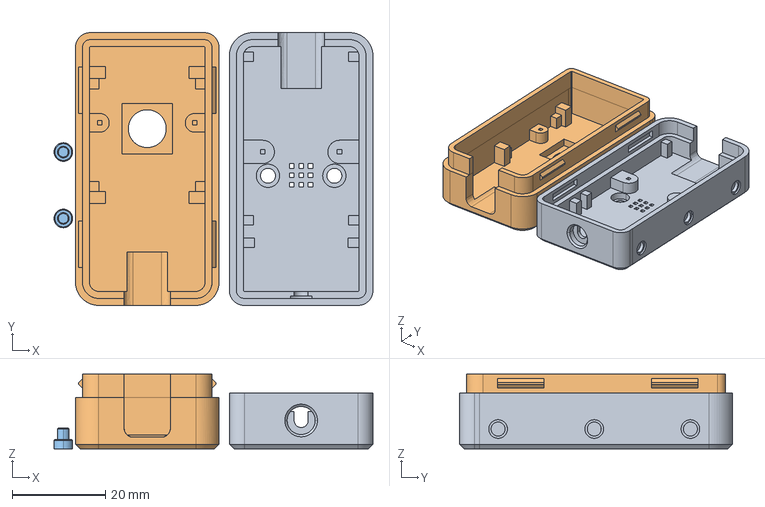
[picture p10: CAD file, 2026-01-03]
devices/KiCad/OPL_Kicad_Library-master/OPL_Kicad_Library-master/Grove Vision AI V2 Library/himax.stp
68.4 x 58.5 x 16.1 mm

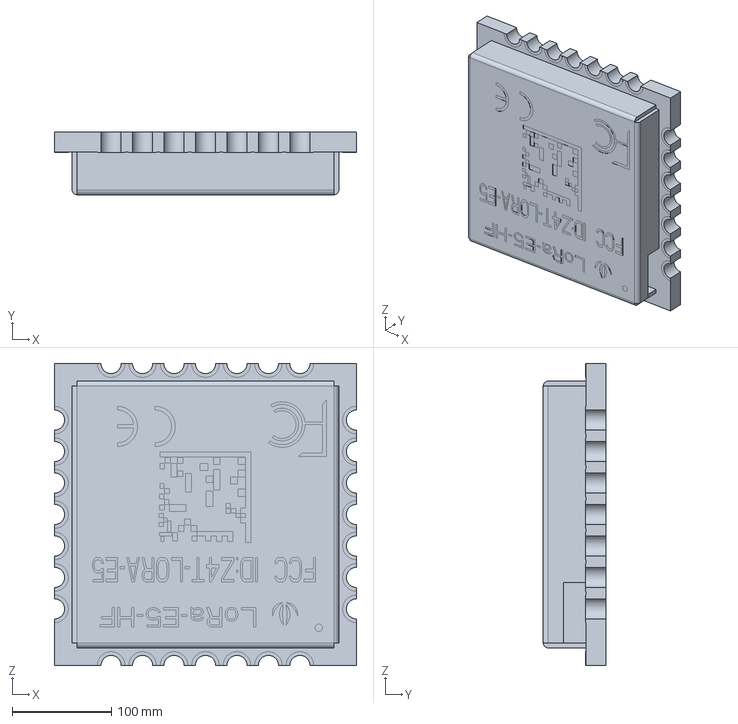
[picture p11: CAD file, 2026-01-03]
devices/KiCad/OPL_Kicad_Library-master/OPL_Kicad_Library-master/Seeed Studio Wio Series/Wio-E5-LE/LoRa-E5-LE-HF_3D_File.stp
304.8 x 63.8 x 304.8 mm

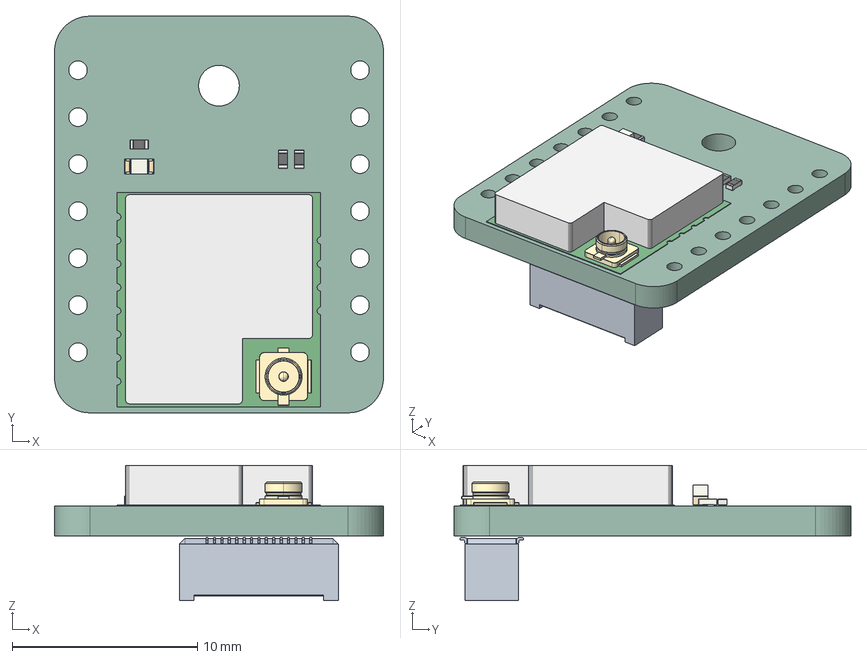
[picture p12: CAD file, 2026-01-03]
devices/KiCad/OPL_Kicad_Library-master/OPL_Kicad_Library-master/Seeed Studio Wio Series/Wio-SX1262/Wio-SX1262_for_XIAO_3D_file.step
17.8 x 21.4 x 7.30 mm
R_0402_1005Metric x 3
LED_0603_1608Metric
PCB
BF04-30pin-35H
Wio-SX1262 for XIAO V1.0_PCB

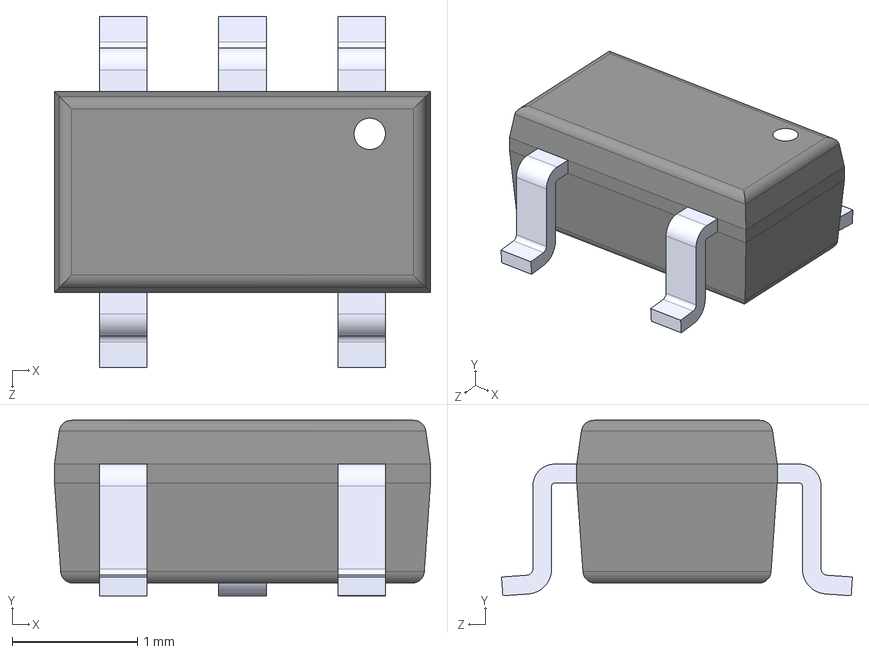
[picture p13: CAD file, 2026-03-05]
devices/KiCad/toytalk_demo_v5/resources/AP2112K-3.3TRG1/AP2112K-3.3TRG1.step
3.00 x 1.40 x 2.80 mm

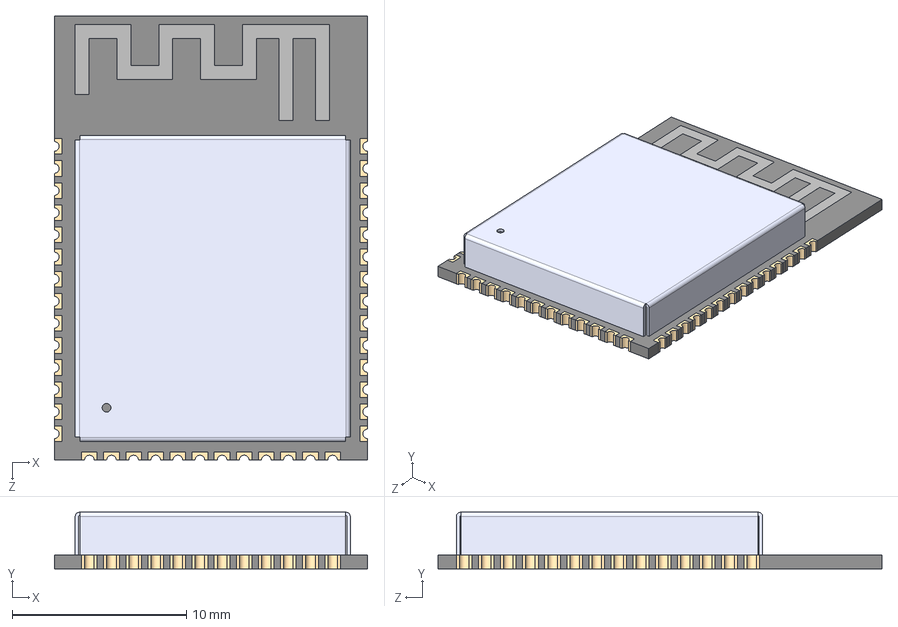
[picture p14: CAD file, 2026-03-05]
devices/KiCad/toytalk_demo_v5/resources/ESP32-S3-WROOM-1-N8R8/ESP32-S3-WROOM-1-N8R8.step
18.0 x 3.25 x 25.5 mm

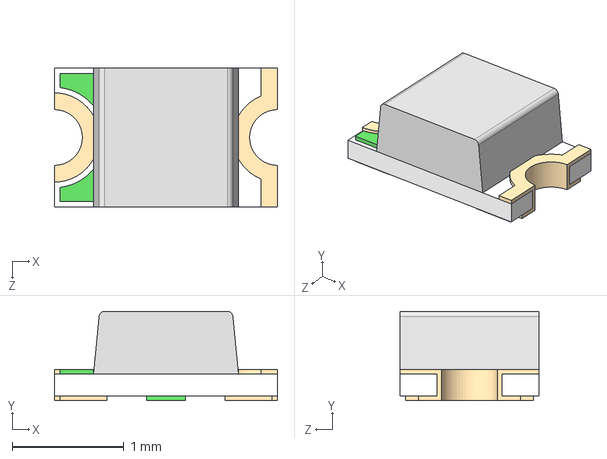
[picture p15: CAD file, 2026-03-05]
devices/KiCad/toytalk_demo_v5/resources/KT-0805W/KT-0805W.step
2.00 x 0.8 x 1.25 mm

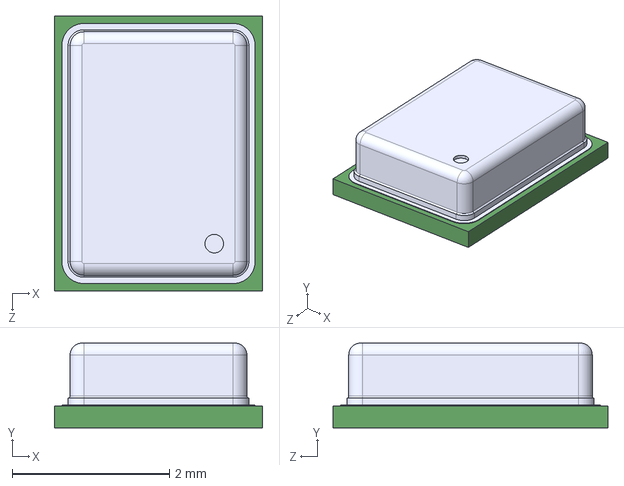
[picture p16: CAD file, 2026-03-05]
devices/KiCad/toytalk_demo_v5/resources/SPH0645LM4H-B/SPH0645LM4H-B.step
2.65 x 1.08 x 3.50 mm

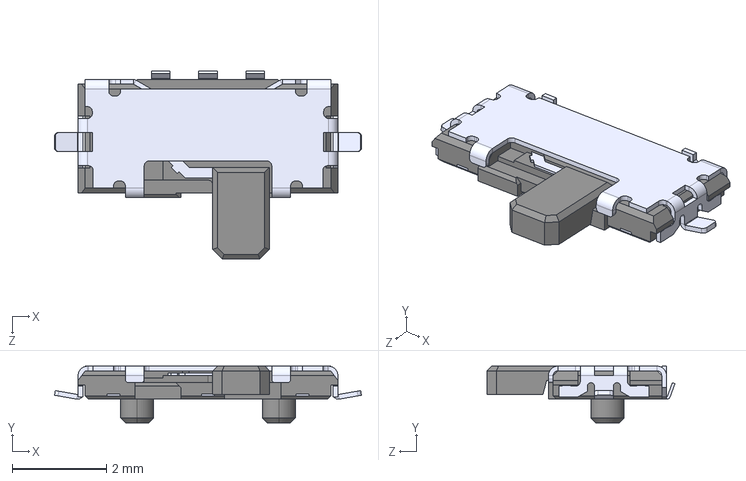
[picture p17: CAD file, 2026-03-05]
devices/KiCad/toytalk_demo_v5/resources/SSAJ110100/SSAJ110100.step
6.50 x 1.20 x 3.98 mm

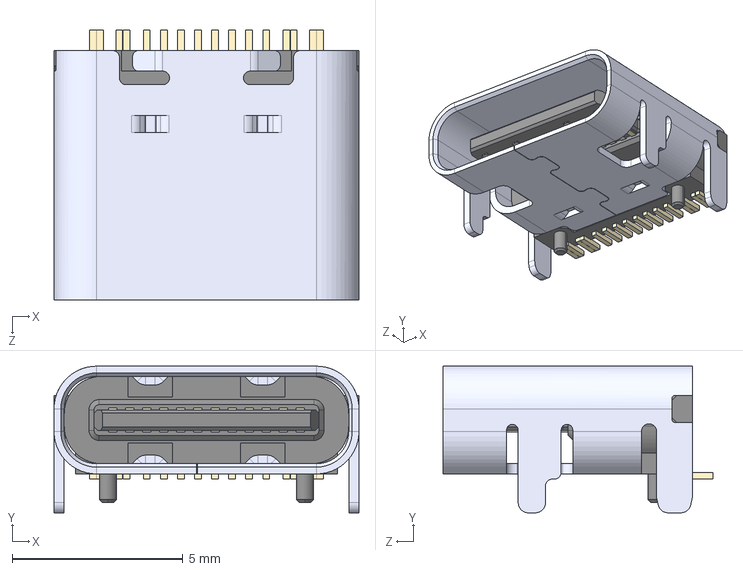
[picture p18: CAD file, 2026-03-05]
devices/KiCad/toytalk_demo_v5/resources/TYPE-C-31-M-12/TYPE-C-31-M-12.step
8.94 x 4.30 x 7.90 mm

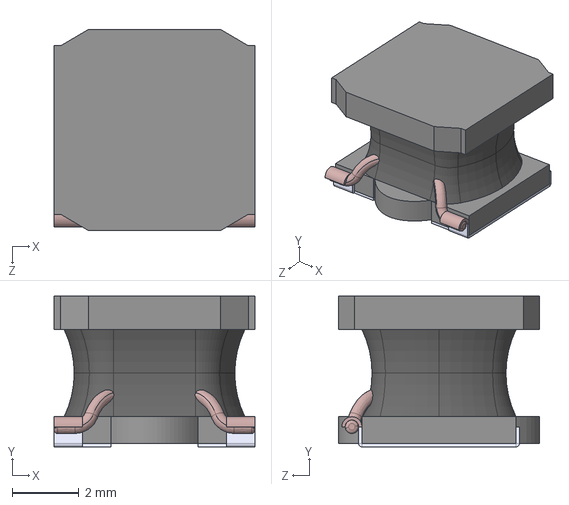
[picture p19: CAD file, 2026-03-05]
devices/KiCad/toytalk_demo_v5/resources/VLS6045EX-1R0N/VLS6045EX-1R0N.step
6.00 x 4.50 x 6.00 mm

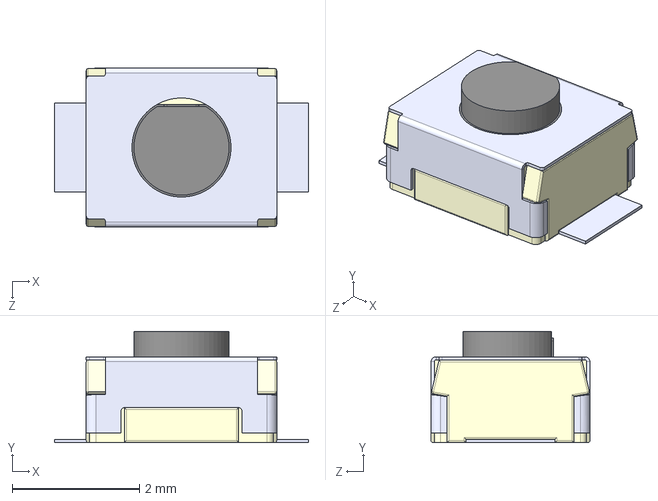
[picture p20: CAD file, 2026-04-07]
devices/KiCad/toytalker_mini_v0.2/resources/B3U-1000P/B3U-1000P.step
4.00 x 1.75 x 2.50 mm

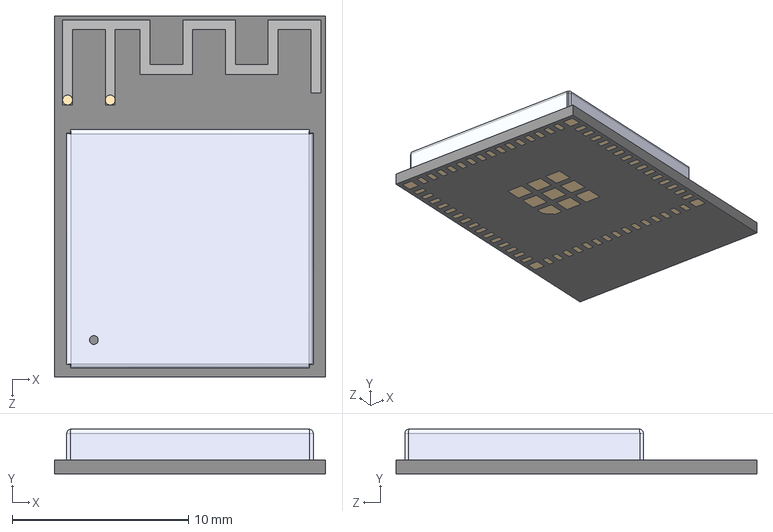
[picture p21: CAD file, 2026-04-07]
devices/KiCad/toytalker_mini_v0.2/resources/ESP32-S3-MINI-1-N4R2/ESP32-S3-MINI-1-N4R2.step
15.4 x 2.55 x 20.5 mm

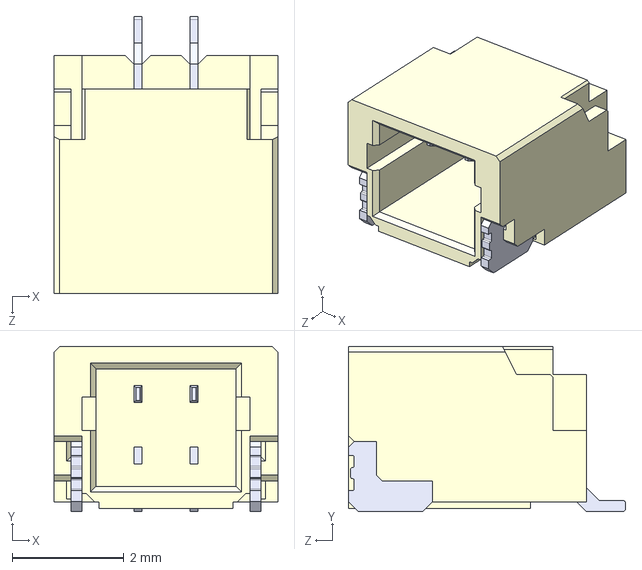
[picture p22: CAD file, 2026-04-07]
devices/KiCad/toytalker_mini_v0.2/resources/SM02B-SRSS-TB_LF__SN_/SM02B-SRSS-TB_LF__SN_.step
4.00 x 2.95 x 4.95 mm

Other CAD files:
devices/KiCad/OPL_Kicad_Library-master/OPL_Kicad_Library-master/Grove Vision AI V2 Library/himax.3mf
devices/KiCad/toytalk_demo_v5/resources/BQ24074RGTR/BQ24074RGTR.step
devices/KiCad/toytalk_demo_v5/resources/MAX98357AEWL_T/MAX98357AEWL_T.step
devices/KiCad/toytalk_demo_v5/resources/TPS61022RWUR/TPS61022RWUR.step
devices/KiCad/toytalker_mini_v0.1/resources/BQ24074RGTR/BQ24074RGTR.step
devices/KiCad/toytalker_mini_v0.1/resources/BQ25185DLHR/BQ25185DLHR.step
devices/KiCad/toytalker_mini_v0.1/resources/MAX98357AEWL_T/MAX98357AEWL_T.step
devices/KiCad/toytalker_mini_v0.1/resources/TPS61022RWUR/TPS61022RWUR.step
devices/KiCad/toytalker_mini_v0.2/resources/BQ24074RGTR/BQ24074RGTR.step
devices/KiCad/toytalker_mini_v0.2/resources/BQ25185DLHR/BQ25185DLHR.step
devices/KiCad/toytalker_mini_v0.2/resources/MAX98357AEWL_T/MAX98357AEWL_T.step
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

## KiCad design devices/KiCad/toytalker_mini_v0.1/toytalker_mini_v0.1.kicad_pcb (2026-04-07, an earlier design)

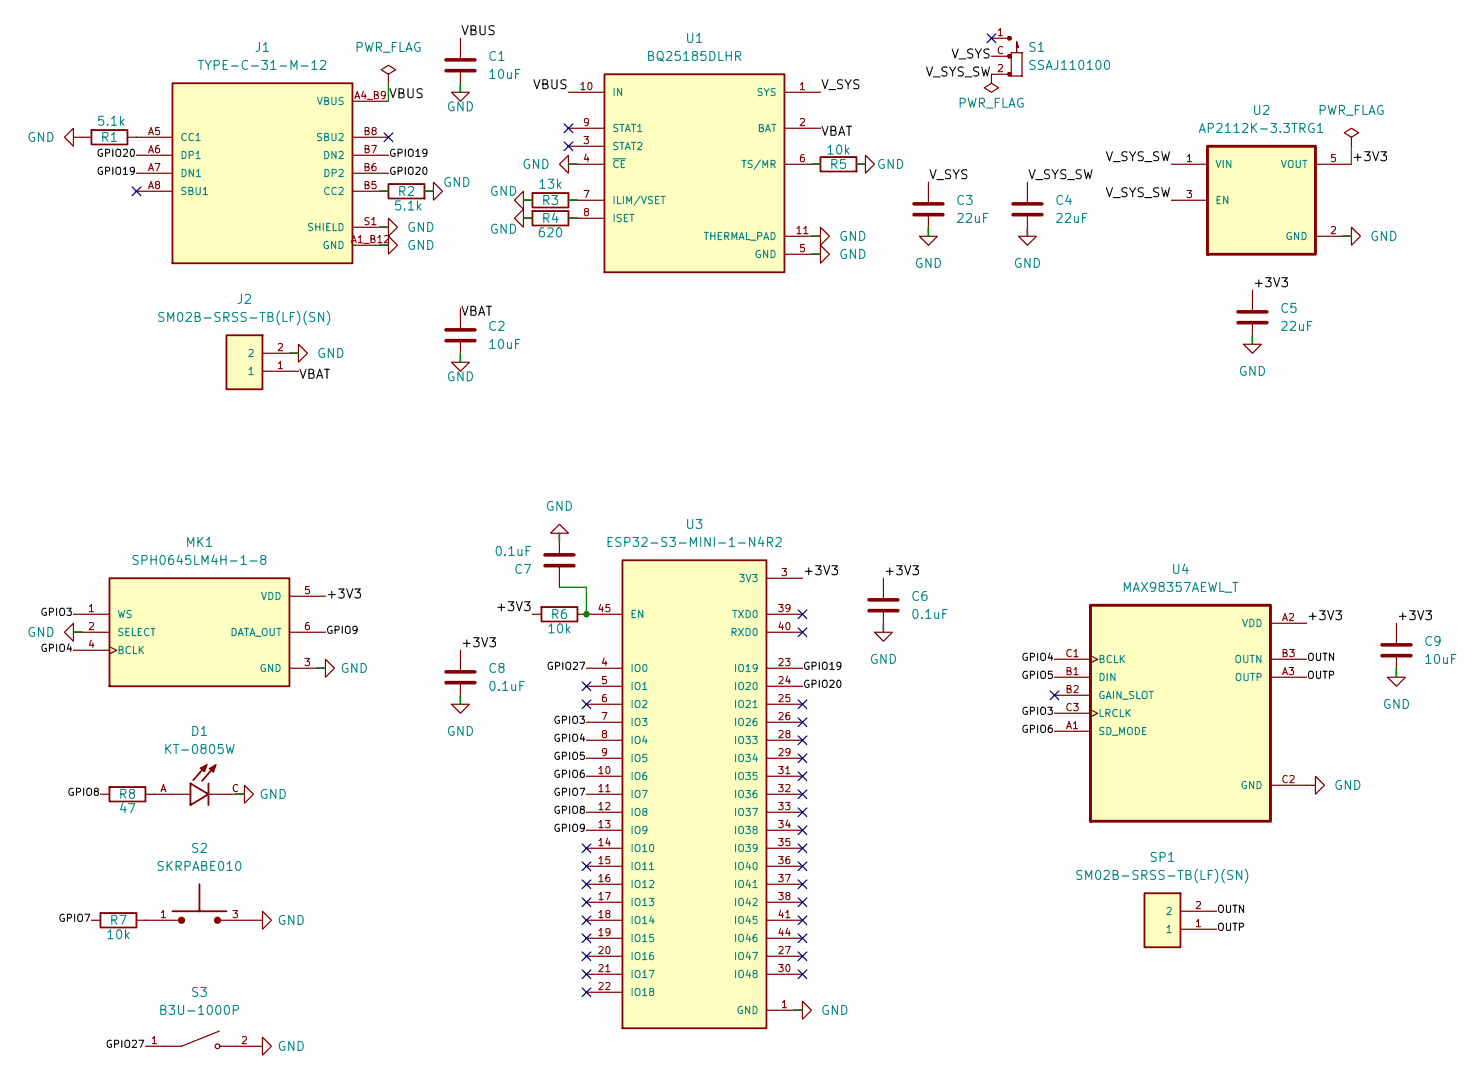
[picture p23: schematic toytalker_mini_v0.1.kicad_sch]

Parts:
C1, C2, C9: 10uF; C_0603_1608Metric
C3, C4, C5: 22uF; C_0603_1608Metric
C6, C7, C8: 0.1uF; C_0402_1005Metric
D1: KT-0805W; LED_KT-0805W; PARTREV 2017.05.16
J1: TYPE-C-31-M-12; HRO_TYPE-C-31-M-12; PARTREV 2020.12.08
J2: SM02B-SRSS-TB(LF)(SN); SM02B-SRSS-TB_LF__SN_
MK1: SPH0645LM4H-1-8; MIC_SPH0645LM4H-B
R1, R2: 5.1k; R_0402_1005Metric
R3: 13k; R_0402_1005Metric
R4: 620; R_0402_1005Metric
R5, R6, R7: 10k; R_0402_1005Metric
R8: 47; R_0402_1005Metric
S1: SSAJ110100; SW_SSAJ110100; PARTREV N/A
S2: SKRPABE010; SW_SKRPABE010
S3: B3U-1000P; SW_SPST_B3U-1000P
SP1: SM02B-SRSS-TB(LF)(SN); SM02B-SRSS-TB_LF__SN_
U1: BQ25185DLHR; IC_BQ25185DLHR; PARTREV OCTOBER 2023
U2: AP2112K-3.3TRG1; SOT95P285X140-5N; PARTREV 2-2
U3: ESP32-S3-MINI-1-N4R2; XCVR_ESP32-S3-MINI-1-N4R2; PARTREV v0.6
U4: MAX98357AEWL_T; BGA9N40P3X3_134X143X69N

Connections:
/+3V3: C5.1, C6.1, C8.1, C9.1, MK1.5 (VDD), R6.2, U2.5 (VOUT), U3.3 (3V3), U4.A2 (VDD)
/GPIO3: MK1.1 (WS), U3.7 (IO3), U4.C3 (LRCLK)
/GPIO4: MK1.4 (BCLK), U3.8 (IO4), U4.C1 (BCLK)
/GPIO5: U3.9 (IO5), U4.B1 (DIN)
/GPIO6: U3.10 (IO6), U4.A1 (SD_MODE)
/GPIO7: R7.2, U3.11 (IO7)
/GPIO8: R8.2, U3.12 (IO8)
/GPIO9: MK1.6 (DATA_OUT), U3.13 (IO9)
/GPIO19: J1.A7 (DN1), J1.B7 (DN2), U3.23 (IO19)
/GPIO20: J1.A6 (DP1), J1.B6 (DP2), U3.24 (IO20)
/GPIO27: S3.1, U3.4 (IO0)
/OUTN: SP1.2, U4.B3 (OUTN)
/OUTP: SP1.1, U4.A3 (OUTP)
/VBAT: C2.1, J2.1, U1.2 (BAT)
/V_SYS: C3.1, S1.C, U1.1 (SYS)
/V_SYS_SW: C4.1, S1.2, U2.1 (VIN), U2.3 (EN)
GND: C1.2, C2.2, C3.2, C4.2, C5.2, C6.2, C7.2, C8.2, C9.2, D1.C, J1.A1_B12 (GND), J1.B1_A12 (GND), J1.S1 (SHIELD), J1.S2 (SHIELD), J1.S3 (SHIELD), J1.S4 (SHIELD), J2.2, MK1.2 (SELECT), MK1.3 (GND), R1.2, R2.2, R3.2, R4.2, R5.2, S2.3, S2.4, S3.2, U1.4 (~CE), U1.5 (GND), U1.11 (THERMAL_PAD), U2.2 (GND), U3.1 (GND), U3.2 (GND), U3.42 (GND), U3.43 (GND), U3.46 (GND), U3.47 (GND), U3.48 (GND), U3.49 (GND), U3.50 (GND), U3.51 (GND), U3.52 (GND), U3.53 (GND), U3.54 (GND), U3.55 (GND), U3.56 (GND), U3.57 (GND), U3.58 (GND), U3.59 (GND), U3.60 (GND), U3.61 (GND), U3.61_1 (GND), U3.61_2 (GND), U3.61_3 (GND), U3.61_4 (GND), U3.61_5 (GND), U3.61_6 (GND), U3.61_7 (GND), U3.61_8 (GND), U3.62 (GND), U3.63 (GND), U3.64 (GND), U3.65 (GND), U4.C2 (GND)
unnamed: D1.A, R8.1
unnamed: J1.A5 (CC1), R1.1
unnamed: J1.B5 (CC2), R2.1
unnamed: R7.1, S2.1, S2.2
unnamed: R3.1, U1.7 (ILIM/VSET)
unnamed: R4.1, U1.8 (ISET)
unnamed: R5.1, U1.6 (TS/MR)
unnamed: C7.1, R6.1, U3.45 (EN)
VBUS: C1.1, J1.A4_B9 (VBUS), J1.B4_A9 (VBUS), U1.10 (IN)

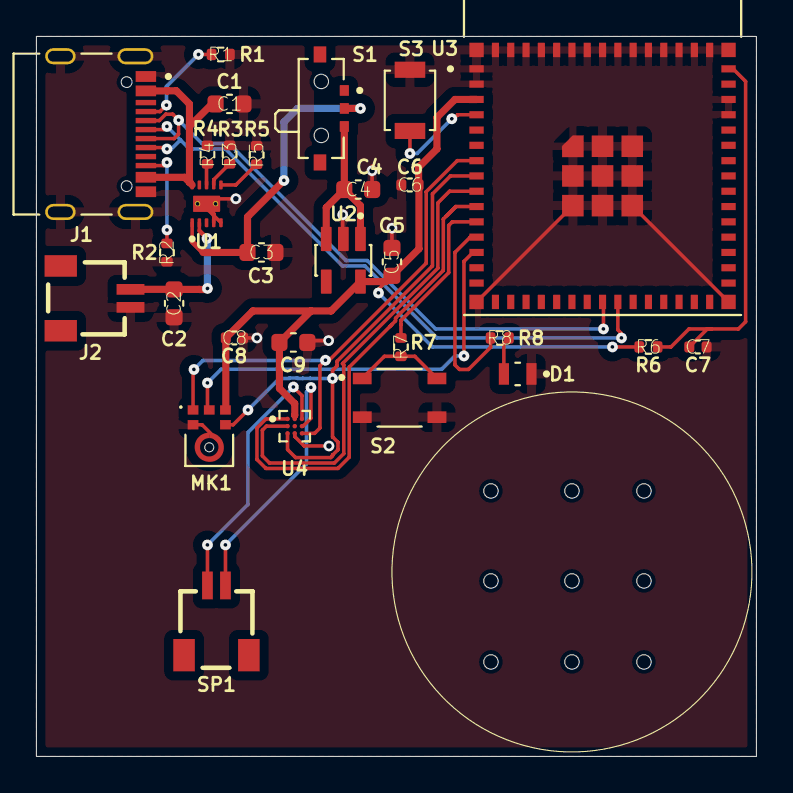
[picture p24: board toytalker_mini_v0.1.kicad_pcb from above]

Board: 2 copper layers, 40.0 x 40.0 mm, 29 parts (0 on the bottom side), 26 nets.

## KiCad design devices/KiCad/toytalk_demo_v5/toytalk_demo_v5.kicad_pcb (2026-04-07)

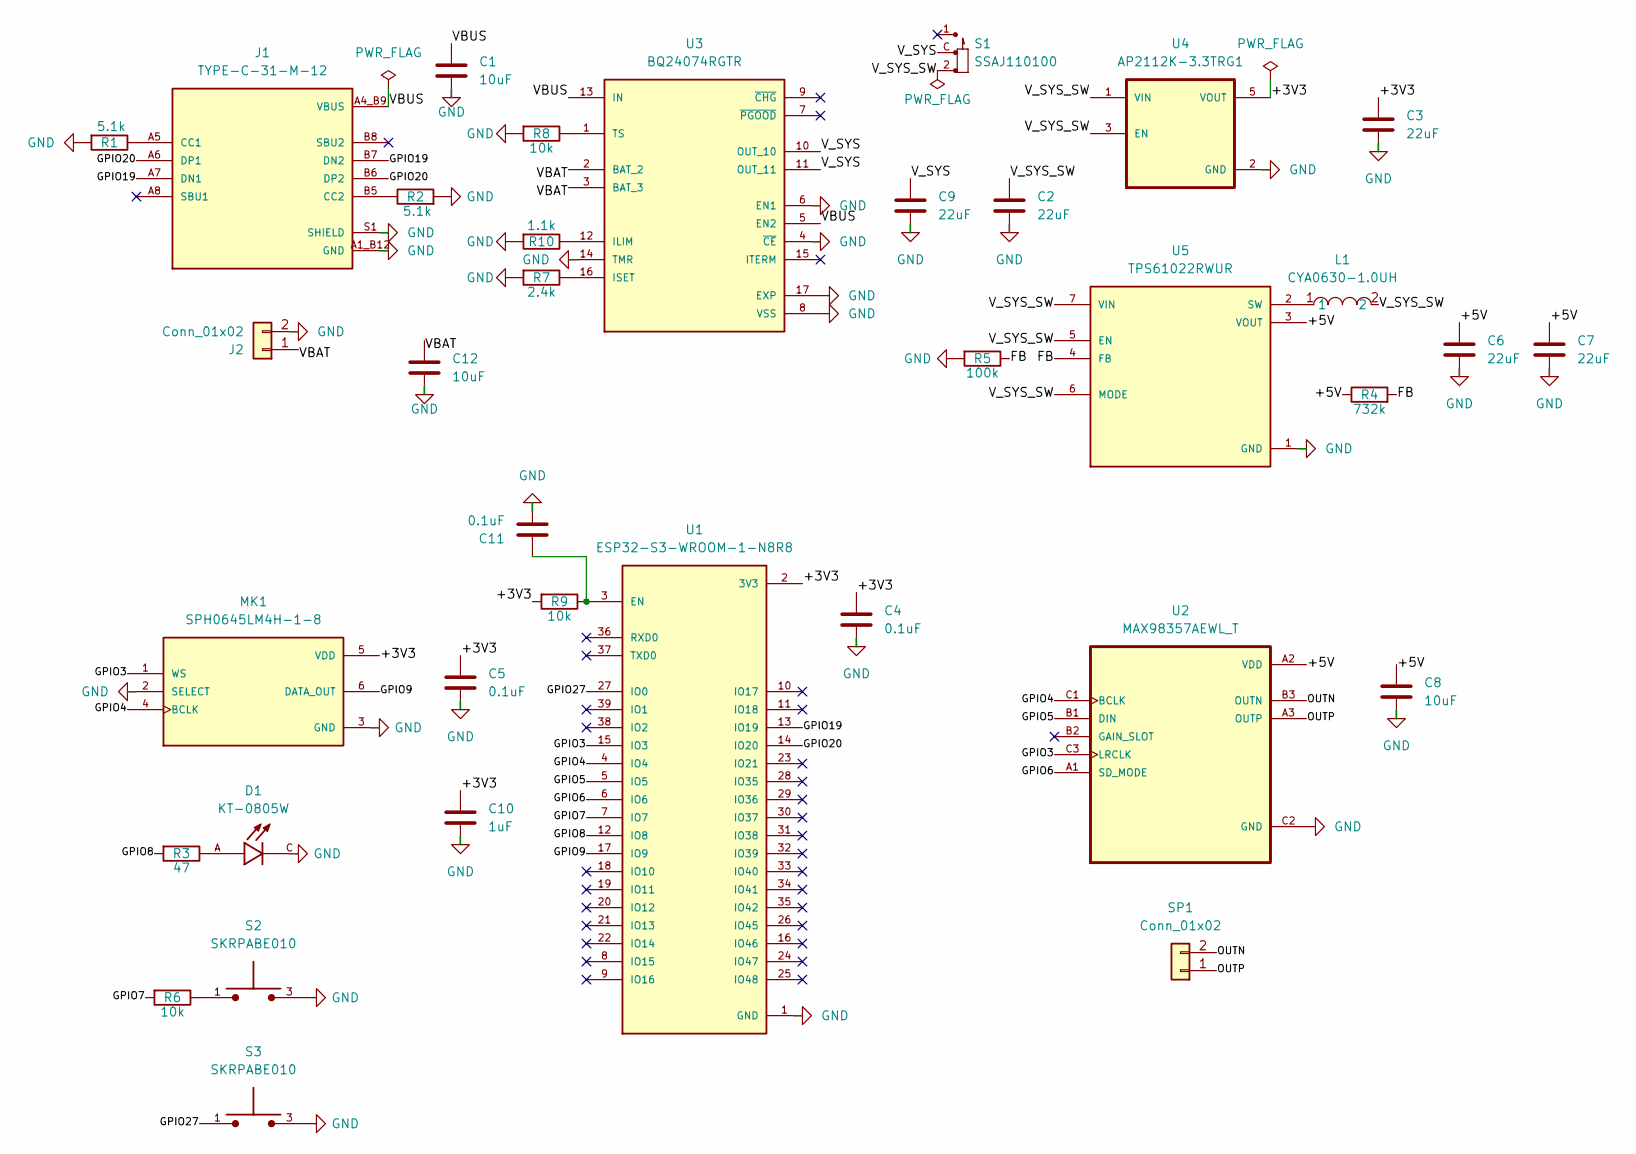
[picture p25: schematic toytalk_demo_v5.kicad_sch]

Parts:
C1, C8, C12: 10uF; C_0603_1608Metric
C2, C3, C6, C7, C9: 22uF; C_0603_1608Metric
C4, C5, C11: 0.1uF; C_0603_1608Metric
C10: 1uF; C_0603_1608Metric
D1: KT-0805W; LED_KT-0805W; PARTREV 2017.05.16
J1: TYPE-C-31-M-12; HRO_TYPE-C-31-M-12; PARTREV 2020.12.08
J2: Conn_01x02; PinHeader_1x02_P2.54mm_Vertical
L1: CYA0630-1.0UH; IND-SMD_L7.2-W6.6_GPSR0730; LCSC Part C5189744
MK1: SPH0645LM4H-1-8; MIC_SPH0645LM4H-B
R1, R2: 5.1k; R_0603_1608Metric
R3: 47; R_0603_1608Metric
R4: 732k; R_0603_1608Metric
R5: 100k; R_0603_1608Metric
R6, R8, R9: 10k; R_0603_1608Metric
R7: 2.4k; R_0603_1608Metric
R10: 1.1k; R_0603_1608Metric
S1: SSAJ110100; SW_SSAJ110100; PARTREV N/A
S2, S3: SKRPABE010; SW_SKRPABE010
SP1: Conn_01x02; PinHeader_1x02_P2.54mm_Vertical
U1: ESP32-S3-WROOM-1-N8R8; XCVR_ESP32S3WROOM1N8R8
U2: MAX98357AEWL_T; BGA9N40P3X3_134X143X69N
U3: BQ24074RGTR; QFN50P300X300X100-17N; PARTREV M
U4: AP2112K-3.3TRG1; SOT95P285X140-5N; PARTREV 2-2
U5: TPS61022RWUR; CONV_TPS61022RWUR; PARTREV 4223724/C 02/2018

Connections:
/+3V3: C3.1, C4.1, C5.1, C10.1, MK1.5 (VDD), R9.2, U1.2 (3V3), U4.5 (VOUT)
/+5V: C6.1, C7.1, C8.1, R4.1, U2.A2 (VDD), U5.3 (VOUT)
/FB: R4.2, R5.1, U5.4 (FB)
/GPIO3: MK1.1 (WS), U1.15 (IO3), U2.C3 (LRCLK)
/GPIO4: MK1.4 (BCLK), U1.4 (IO4), U2.C1 (BCLK)
/GPIO5: U1.5 (IO5), U2.B1 (DIN)
/GPIO6: U1.6 (IO6), U2.A1 (SD_MODE)
/GPIO7: R6.2, U1.7 (IO7)
/GPIO8: R3.2, U1.12 (IO8)
/GPIO9: MK1.6 (DATA_OUT), U1.17 (IO9)
/GPIO19: J1.A7 (DN1), J1.B7 (DN2), U1.13 (IO19)
/GPIO20: J1.A6 (DP1), J1.B6 (DP2), U1.14 (IO20)
/GPIO27: S3.1, S3.2, U1.27 (IO0)
/OUTN: SP1.2, U2.B3 (OUTN)
/OUTP: SP1.1, U2.A3 (OUTP)
/VBAT: C12.1, J2.1, U3.2 (BAT_2), U3.3 (BAT_3)
/V_SYS: C9.1, S1.C, U3.10 (OUT_10), U3.11 (OUT_11)
/V_SYS_SW: C2.1, L1.2, S1.2, U4.1 (VIN), U4.3 (EN), U5.5 (EN), U5.6 (MODE), U5.7 (VIN)
GND: C1.2, C2.2, C3.2, C4.2, C5.2, C6.2, C7.2, C8.2, C9.2, C10.2, C11.2, C12.2, D1.C, J1.A1_B12 (GND), J1.B1_A12 (GND), J1.S1 (SHIELD), J1.S2 (SHIELD), J1.S3 (SHIELD), J1.S4 (SHIELD), J2.2, MK1.2 (SELECT), MK1.3 (GND), R1.2, R2.2, R5.2, R7.2, R8.2, R10.2, S2.3, S2.4, S3.3, S3.4, U1.1 (GND), U1.40 (GND), U1.41_1 (GND), U1.41_2 (GND), U1.41_3 (GND), U1.41_4 (GND), U1.41_5 (GND), U1.41_6 (GND), U1.41_7 (GND), U1.41_8 (GND), U1.41_9 (GND), U2.C2 (GND), U3.4 (~CE), U3.6 (EN1), U3.8 (VSS), U3.14 (TMR), U3.17 (EXP), U4.2 (GND), U5.1 (GND)
unnamed: D1.A, R3.1
unnamed: J1.A5 (CC1), R1.1
unnamed: J1.B5 (CC2), R2.1
unnamed: R6.1, S2.1, S2.2
unnamed: C11.1, R9.1, U1.3 (EN)
unnamed: R10.1, U3.12 (ILIM)
unnamed: R7.1, U3.16 (ISET)
unnamed: R8.1, U3.1 (TS)
unnamed: L1.1, U5.2 (SW)
VBUS: C1.1, J1.A4_B9 (VBUS), J1.B4_A9 (VBUS), U3.5 (EN2), U3.13 (IN)

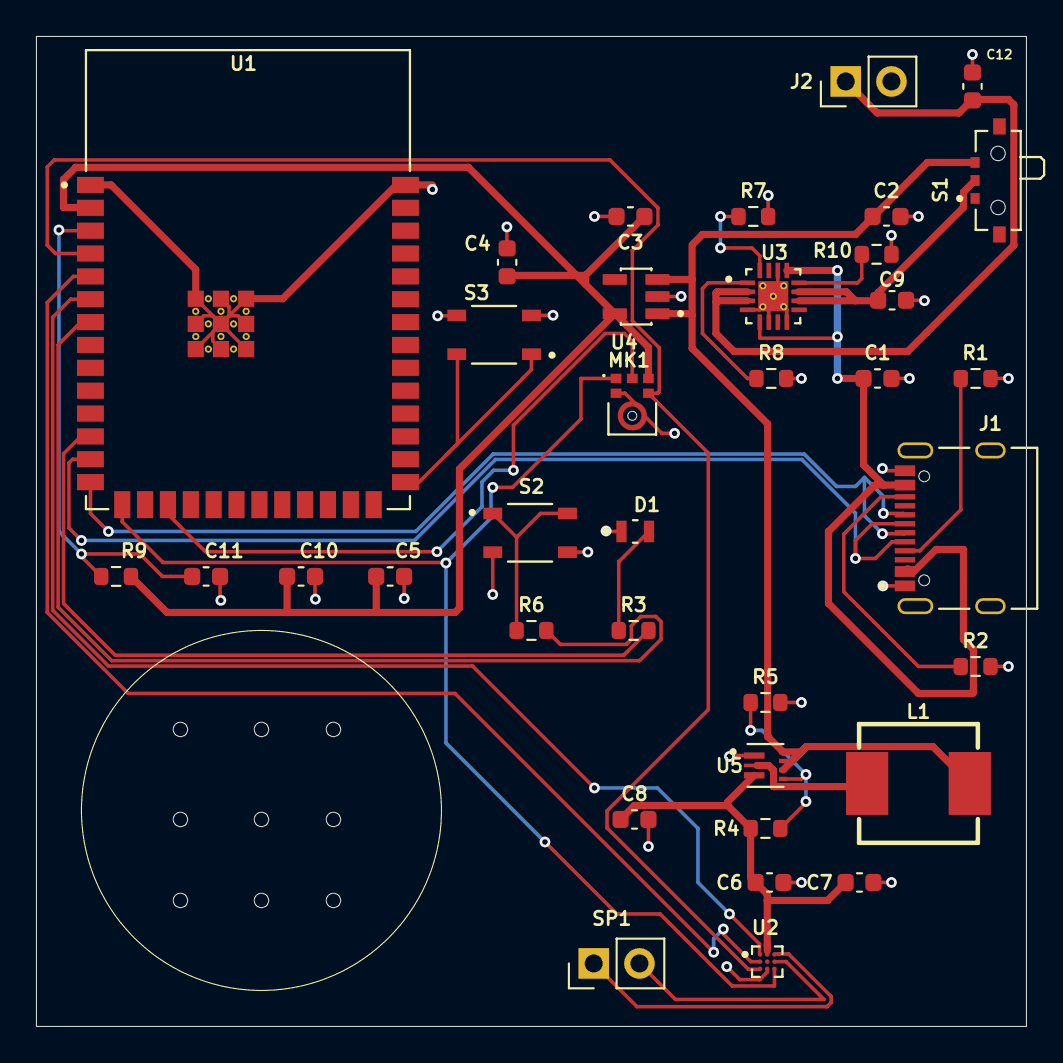
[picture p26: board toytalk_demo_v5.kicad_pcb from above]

Board: 2 copper layers, 55.0 x 55.0 mm, 36 parts (0 on the bottom side), 29 nets.

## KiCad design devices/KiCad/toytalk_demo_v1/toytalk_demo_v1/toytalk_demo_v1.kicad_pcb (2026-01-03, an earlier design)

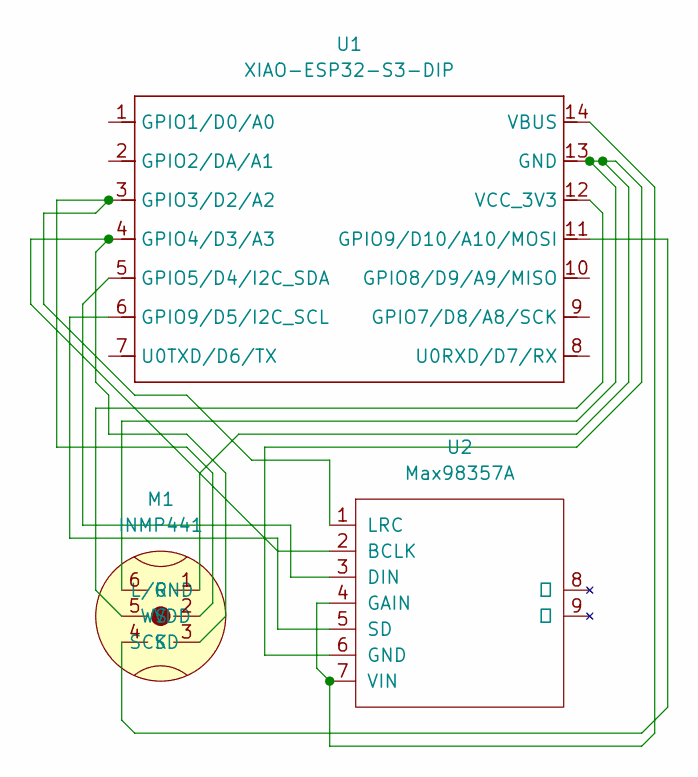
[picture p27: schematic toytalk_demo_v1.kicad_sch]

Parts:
M1: INMP441; INMP441_OMNIDIRECTIONAL_MICROPHONE_MODULE
U1: XIAO-ESP32-S3-DIP; XIAO-ESP32S3-DIP
U2: Max98357A; MAX98357-MODULE SMD FOOTPRINT

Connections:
unnamed: M1.1 (L/R), M1.6 (GND), U1.13 (GND), U2.6 (GND)
unnamed: M1.3 (SCK), U1.4 (GPIO4/D3/A3), U2.2 (BCLK)
unnamed: M1.4 (SD), U1.11 (GPIO9/D10/A10/MOSI)
unnamed: M1.5 (VDD), U1.12 (VCC_3V3)
unnamed: M1.2 (WS), U1.3 (GPIO3/D2/A2), U2.1 (LRC)
unnamed: U1.5 (GPIO5/D4/I2C_SDA), U2.3 (DIN)
unnamed: U1.6 (GPIO9/D5/I2C_SCL), U2.5 (SD)
unnamed: U1.14 (VBUS), U2.4 (GAIN), U2.7 (VIN)

Board: 2 copper layers, 3 parts (0 on the bottom side), 8 nets, no tracks yet.

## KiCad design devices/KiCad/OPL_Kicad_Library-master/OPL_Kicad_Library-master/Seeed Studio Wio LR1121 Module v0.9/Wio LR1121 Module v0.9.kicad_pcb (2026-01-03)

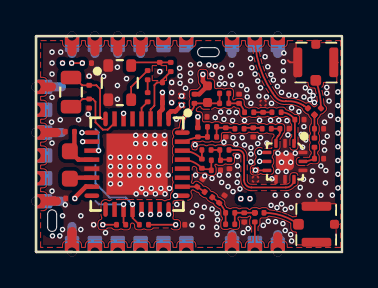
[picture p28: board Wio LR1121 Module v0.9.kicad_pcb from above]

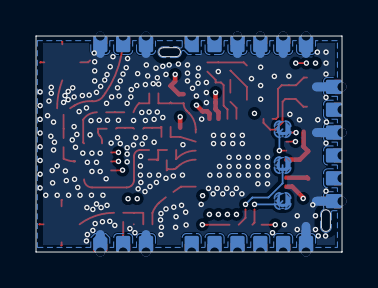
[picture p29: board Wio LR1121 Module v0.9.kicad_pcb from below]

Board: 4 copper layers, 17.0 x 12.0 mm, 69 parts (3 on the bottom side), 47 nets.

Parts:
C1, C2, C3, C4, C5, C6, C7, C8, C9, C11, C12, C13, C14, C15, C18, C19, C20, C22, C24, C25, C26, C27, C28, C29, C30, C31, C32, C33, C34, C35, C36, C37, C38, C39, C40, C41, C42, C43: C0201
FB1: L0201
J1, J2: U-FL4P-SMD-1_7X1_7X1_0MM
L1: L0402
L2, L3, L5, L6, L7, L8, L9, L10, L11, L13: L0201
L12: L0603
OSC1: X4_SMD_2_5X2_0MM
R1, R2, R3, R4, R5, R7, R8, R9: R0201
TP23, TP24, TP25: TP35S_SMD
U1: QFN12_0D5_2X2X0_55MM
U2: QFN32_0D5_5X5MM_EP3P3MM
U3: MODULE24_1D27_17X12MM
X1: X2_SMD_2X1_2MM

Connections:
2.4G_RF: C43.2, U3.2
GND_POWER: C3.2, C4.2, C5.2, C6.2, C7.2, C8.2, C11.2, C12.2, C13.2, C14.2, C15.2, C18.2, C19.2, C22.2, C25.2, C26.2, C28.2, C29.2, C30.2, C31.2, C32.2, C33.2, C35.2, C36.2, C37.2, C38.2, C40.2, C42.2, J1.2, J1.3, J1.4, J2.2, J2.3, J2.4, OSC1.1, OSC1.2, U1.2, U1.7, U1.8, U1.10, U1.12, U1.13, U2.13, U2.33, U3.1, U3.3, U3.9, U3.10, U3.13, U3.15, U3.16, U3.17, U3.18, U3.19, U3.22, U3.24
HP_LF: C1.1, L1.2, L2.1, R1.2, U2.32
LP_LF: C9.1, L6.1, L13.2, U2.31
LR1121_BUSY: U2.25, U3.8
LR1121_DIO8: U2.10, U3.11
LR1121_DIO9_INT: U2.9, U3.12
LR1121_RSTN: C42.1, R7.2, U2.6, U3.14
LR1121_SPI_MISO: U2.21, U3.7
LR1121_SPI_MOSI: U2.22, U3.6
LR1121_SPI_NSS: U2.24, U3.4
LR1121_SPI_SCK: U2.23, U3.5
MCU_DIO5: R3.1, TP23.1, U2.20
MCU_DIO6: R2.1, TP24.1, U2.19
MCU_DIO7: R5.1, TP25.1, U2.11
N18704063: C25.1, U2.7, X1.1
N18704080: C26.1, U2.8, X1.2
N18704168: L12.2, U2.14
N18704177: C31.1, L12.1, U2.12
N18704981: C9.2, C37.1, L6.2, L7.1
N18704990: C1.2, C3.1, L2.2, L3.1
N18705097: C2.1, C4.1, L3.2
N18705182: C38.1, C39.1, L7.2
N18705449: C18.1, C39.2, U1.3
N18705460: C2.2, C5.1, U1.1
N18706098: C20.2, C40.1, C41.1, L9.2
N18706198: C41.2, U1.9
N18706539: C24.1, C29.1, L10.2, L11.1
N18706650: C24.2, C27.1, C30.1, C43.1, L11.2
N18706671: C27.2, J2.1
N18712116: C14.1, L5.1, U1.11
N18712319: C36.1, FB1.2, OSC1.4
N18712325: C34.1, OSC1.3
N18712327: C34.2, R4.1
N18713044: C15.1, L5.2, R8.1, R9.1
N18751757: J1.1, R8.2
RFIO_HF: C28.1, L10.1, U2.26
RFI_N: C22.1, L8.2, L9.1, U2.29
RFI_P: C20.1, L8.1, U2.30
RFSW0_V1: C33.1, R3.2, U1.4
RFSW1_V2: C32.1, R2.2, U1.5
RFSW_VDD: C19.1, R5.2, U1.6
SUBG_RF: R9.2, U3.23
VDD_RF: C11.1, C12.1, C13.1, R7.1, U2.2, U2.15, U3.20, U3.21
VR_PA: C6.1, C7.1, C8.1, L1.1, L13.1, R1.1, U2.1
VTCXO: C35.1, FB1.1, U2.3
XTA: R4.2, U2.4

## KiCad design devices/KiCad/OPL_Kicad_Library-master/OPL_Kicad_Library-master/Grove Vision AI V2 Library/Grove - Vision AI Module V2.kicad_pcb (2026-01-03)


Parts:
BOOT1: SW_Push; SW_Push_1P1T_NO_Vertical_Wuerth_434133025816
C1, C2, C17, C18, C19: 1uF; C0402
C3: 10nF; C0402
C4, C6, C7, C9, C10, C28, C34: 4.7uF; C0402
C5, C8, C13, C20, C21, C22, C23, C24, C25, C26, C27, C29, C30, C31, C32, C35, C36, C39: 100nF; C0402
C11, C37: 10uF; C0402
C14, C15: 12pF; C0402
C16: 220nF; C0402
D1, D2, D3, D4: B5819WS; D0805_SOD323
D5, D6, D7, D8: DNP; R0402; MPN DF2S6.8FS
J1: USB_C_Receptacle_USB2.0; USB2.0-TYPE-C
J2: Conn_01x15_MountingPin; FPC_DNC_15P_1.0mm
J3: Conn_01x04_MountingPin; 4P-SMD-2.0mm-RIGHT
J5: ST-TF-MR267; SD-TF-MR267; MPN SD-TF-MR267
L1: VLS201610HBX-4R7M-1; L0806
L2, L3: 470nH; L0603
LED1: Yellow; LED0402
LED2: Green; LED0402
M1: XIAO Connector/DNP; XIAO_Socket
MIC1: MSM261D3526H1CPM; MIC6P-3.5X2.65X0.94MM
Q1, Q2, Q3, Q4, Q5: CJ1012; SOT523
R1, R4, R13, R14, R15, R19, R20, R21, R22, R40: 2.2k; R0402
R2, R3, R36: 5.1k; R0402
R5, R7, R23, R24: 10k; R0402
R6, R16, R32, R33: 100K; R0402; Power Rating 1%; MPN RC0402JR-074K7L
R8, R31, R38: 10K; R0402; Power Rating 5%; MPN RC0402JR-074K7L
R9, R12, R17, R18, R25, R27, R28: DNP; R0402
R10, R11, R37: 100k; R0402
R26, R34: 22K; R0402; Power Rating 1%; MPN RC0402JR-074K7L
R29, R30, R39: 0R; R0402
R35: 510k; R0402
RST1: SW_Push; SW_Push_1P1T_NO_Vertical_Wuerth_434133025816
TP1, TP2, TP3: Test Point; TP-D35MIL; Part Type Test Point
U1: HX6538; WLCSP65_5.6x2.3x0.56mm
U2: CH343P; QFN-16-EP_3x3mm_P0.5mm_EP1x1mm
U3: WR0331-18FF4R; X2SON-4
U4, U6: SY80004DQD; DFN6-0.5-1.5X1.5X0.65MM; MPN SY80004DQD
U5: W25Q128JWSIQ; SOIC-8_5.23x5.23mm_P1.27mm
X1: 24MHz; 4P2016

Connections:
1V8: C13.1, C19.2, C20.1, C21.1, C28.1, C29.2, Q1.1 (G), Q2.1 (G), R5.1, R21.2, R22.2, R25.1, TP2.1 (T), U1.F3 (VDDIO_SIF1), U1.G3 (VDDA_RX), U1.H5 (VDDA_TX), U1.L2 (VDDIO_SIF2), U3.1 (OUT), U5.8 (VCC)
/0V9: C4.1, C7.1, L1.2, U1.L4 (DCDC_OUT)
BOOTOPT0: D3.1 (K), R11.1, U1.F4 (BOOT_OPT)
GND: C1.2, C2.2, C3.2, C4.2, C5.2, C6.2, C7.2, C8.1, C9.2, C10.2, C11.1, C13.2, C14.2, C15.1, C17.2, C18.2, C19.1, C20.2, C21.2, C22.2, C23.2, C24.1, C25.1, C26.2, C27.1, C28.2, C29.1, C30.1, C31.2, C34.2, C35.1, C37.1, C39.1, D5.1, D6.1, D7.1, D8.1, J1.A1_B1_A12_B12 (GND), J1.S1 (SHIELD), J2.1, J2.4, J2.7, J2.10, J2.MP (MountPin), J3.4, J3.MP (MountPin), J5.S1 (SHD1), J5.S2 (SHD2), J5.S3 (SHD3), J5.S4 (SHD4), J5.T6 (VSS), LED2.1 (K), M1.13 (GND), MIC1.4 (GND), MIC1.5 (L/R), MIC1.6 (GND), Q3.2 (S), R2.2, R3.2, R10.2, R11.2, R23.2, R26.1, R34.1, R37.2, RST1.2, TP3.1 (T), U1.C5 (GND1), U1.G4 (GND2), U1.H3 (GND3), U1.L3 (GND4), U1.M2 (GND5), U1.M4 (GND6), U2.2 (GND), U2.17 (EPAD), U3.2 (GND), U3.T (GND), U4.4 (GND), U5.4 (GND), U6.4 (GND), X1.2 (1), X1.4 (3)
GROVE_5V_IN: C18.1, C34.1, C35.2, J3.3, R14.1, R15.1, R31.2, R32.2, U6.6 (IN)
I2CS0_SCL/5V: J3.1, Q4.3 (D), R14.2
I2CS0_SDA/5V: J3.2, Q5.3 (D), R15.2
M_3V3_SCL: J2.13, Q1.3 (D), R19.2
M_3V3_SDA: J2.14, Q2.3 (D), R20.2
unnamed: BOOT1.2, R4.2
unnamed: D1.2 (A), R36.2
unnamed: C9.1, C10.1, C27.2, D2.1 (K), D4.1 (K), R6.2, R8.2, U4.6 (IN)
unnamed: BOOT1.1, D3.2 (A), R36.1
unnamed: J1.A5 (CC1), R2.1
unnamed: J1.B5 (CC2), R3.1
unnamed: LED1.2 (A), R38.1
unnamed: LED1.1 (K), Q3.3 (D)
unnamed: LED2.2 (A), R24.2
unnamed: M1.12 (3V3), R39.2
unnamed: MIC1.2 (CLK), R29.1
unnamed: MIC1.3 (DATA), R30.1
unnamed: Q3.1 (G), R37.1, R40.2
unnamed: R10.1, U1.E4 (TEST_MODE)
unnamed: L1.1, U1.L5 (VX1)
unnamed: C14.1, R35.1, U1.G2 (XTAL_24M_I), X1.3 (4)
unnamed: C15.2, R35.2, U1.F1 (XTAL_24M_O), X1.1 (2)
unnamed: C16.2, U2.13 (RTS)
unnamed: R8.1, U4.1 (EN)
unnamed: C32.1, R16.1, R26.2, U4.3 (FB)
unnamed: L2.1, U4.5 (LX)
unnamed: R6.1, U4.2 (PG)
unnamed: R31.1, U6.1 (EN)
unnamed: C36.1, R33.1, R34.2, U6.3 (FB)
unnamed: L3.1, U6.5 (LX)
unnamed: R32.1, U6.2 (PG)
PA0/3V3: M1.1 (D0/A0), U1.D4 (PA0)
PA1/VMUTE/3V3: J2.11, U1.C4 (PA1)
PA2/I2CS0_SCL/3V3: M1.6 (D5/SCL), Q4.2 (S), R1.1, R17.2, U1.A4 (PA2)
PA3/I2CS0_SDA/3V3: M1.5 (D4/SDA), Q5.2 (S), R13.1, R18.2, U1.B4 (PA3)
PB0/RX0/3V3: U1.A5 (PB0), U2.4 (TXD)
PB1/TX0/3V3: U1.B5 (PB1), U2.5 (RXD)
PB2/SSPIM_DO/3V3: D7.2, J5.T3 (CMD), M1.11 (D10/MOSI), R12.2, U1.N5 (PB2)
PB3/SSPIM_DI/3V3: D5.2, J5.T7 (DAT0), M1.10 (D9/MISO), R9.2, U1.M3 (PB3)
PB4/SSPIM_SCLK/3V3: D6.2, J5.T5 (CLOCK), M1.9 (D8/SCK), R27.2, U1.N4 (PB4)
PB5/SSPIM_~CS/3V3: D8.2, J5.T2 (CD/DAT3), R28.2, U1.N3 (PB5)
PB6/UART1_RX/3V3: M1.7 (D6/TX), U1.N1 (PB6)
PB7/UART1_TX/3V3: M1.8 (D7/RX/SS), U1.M1 (PB7)
PB8/3V3: M1.3 (D2/A2), U1.L1 (PB8)
PB9/PDM_CLK/3V3: R29.2, U1.F5 (PB9)
PB10/PDM_DATA0/3V3: R30.2, U1.G5 (PB10)
PB11/3V3: M1.2 (D1/A1), U1.J3 (PB11)
QSPI_CLK: U1.C2 (QSPI_CLK), U5.6 (CLK)
QSPI_CS: R5.2, U1.B2 (QSPI_CS), U5.1 (~CS)
QSPI_D0: U1.B1 (QSPI_DIO0), U5.5 (DI(IO0))
QSPI_D1: U1.D3 (QSPI_DIO1), U5.2 (DO(IO1))
QSPI_D2: U1.A1 (QSPI_DIO2), U5.3 (IO2)
QSPI_D3: U1.E3 (QSPI_DIO3), U5.7 (IO3)
RST: C3.1, C16.1, M1.4 (D3/A3), R7.1, RST1.1, U1.E5 (RESETN)
RX_CK_N: J2.8, U1.E2 (RX_CKN)
RX_CK_P: J2.9, U1.F2 (RX_CKP)
RX_D0_N: J2.2, U1.D2 (RX_DN0)
RX_D0_P: J2.3, U1.C1 (RX_DP0)
RX_D1_N: J2.5, U1.D1 (RX_DN1)
RX_D1_P: J2.6, U1.E1 (RX_DP1)
SEN_D1/SD~INSERT: J5.G1 (SWITCH), R25.2, U1.G1 (SEN_D1)
SEN_I2CM_SCL: Q1.2 (S), R21.1, U1.A3 (SEN_I2CM_SCL)
SEN_I2CM_SDA: Q2.2 (S), R22.1, U1.B3 (SEN_I2CM_SDA)
UD+: J1.A6 (D+), J1.B6 (D+), U2.7 (D+)
UD-: J1.A7 (D-), J1.B7 (D-), U2.8 (D-)
USER_LED/1V8: R40.1, U1.K2 (SEN_D2)
USR_BTN/1V8: D1.1 (K), R23.1, U1.H1 (SEN_D0)
V33IO: C2.1, C31.1, U2.1 (VIO), U2.6 (V3)
VBUS: C1.1, C30.2, D4.2 (A), J1.A4_B4_A9_B9 (VBUS), U2.3 (VDD5), U2.9 (VBUS)
VCC_3V3: C5.1, C6.1, C8.2, C11.2, C17.1, C22.1, C23.1, C24.2, C25.2, C26.1, C32.2, C36.2, C37.2, C39.2, J2.15, J5.T4 (VDD), L2.2, L3.2, MIC1.1 (VDD), Q4.1 (G), Q5.1 (G), R1.2, R4.1, R7.2, R9.1, R12.1, R13.2, R16.2, R17.1, R18.1, R19.1, R20.1, R24.1, R27.1, R28.1, R33.2, R38.2, R39.1, TP1.1 (T), U1.D5 (VDDIO_AON), U1.M5 (VDDA_DCDC), U1.N2 (VDDIO_PIF), U3.3 (EN), U3.4 (IN)
VMAIN: D2.2 (A), M1.14 (VUSB)

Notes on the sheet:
MIPI CSI
AON 3V3
MIPI DSI
PIF 3V3
SIF only 1V8
Imax=600mA
23/11/14
Grove - Vision AI Module V2
JN.FUONG



Board: 4 copper layers, 40.0 x 20.0 mm, 112 parts (31 on the bottom side), 75 nets.

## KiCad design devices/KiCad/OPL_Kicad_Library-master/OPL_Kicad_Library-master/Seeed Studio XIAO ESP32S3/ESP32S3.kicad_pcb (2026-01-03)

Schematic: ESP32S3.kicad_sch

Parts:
ANT1: U.FL-R-SMT-1; U-FL3P-SMD-2.6X2.6X1.0MM
BAT0: VBAT; TP-80X40MIL
C1, C2, C17, C20: DNP; C0201
C3, C9, C13, C16: 2.2uF; C0201
C4, C5, C6: 4.7uF; C0201
C7, C8, C28: 10pF; C0201
C10, C21, C25, C26: 1uF; C0201
C11, C14, C15, C19, C22, C23, C29, C30: 100nF; C0201
C12: 10nF; C0201
C18: 1pF; C0201
CHG0: RED; LED-0402
D2: LMBR4010BST5G; DFN1006-2L
D3: Yellow; LED-0402
GND0: GND; TP-80X40MIL
J1, J2: DNP; H7-HALF-HOLE-2.54
J3: DF40C-30DP-0.4V(51); BTB30-0.4-7.52X2.97X1.14
K1, K2: SKTAAAE010/311021459; SW4-SMD-2.8-2.6X1.6X0.53MM
L1: 2nH; L0201
L2: 3.3nH; L0201
L3: DNP; L0201
L4: 470nH; L0603
Q1: LP0404N3T5G; PMOS_1.0_0.6_0.35MM
R1, R2: 5.1K; R0201
R3, R4: 22R; R0201
R5: 0R; R0201
R6: 499R; R0201
R7, R8, R11: 10K; R0201
R9: 100K; C0201
R10: 220K; R0201
R13: 249K; R0201
R15: 1.5K; R0201
TP1, TP2, TP3, TP4, TP5, TP6, TP7, TP8: TEST-POINT'4545'; TP-D45MIL
U1: ESP32-S3R8; QFN56G-0.4-7X7MM
U3: SGM6029CYG/TR; BGA6-0.35-0.745X10.95X0.4MM
U4: SGM40567-4.2XG/TR; WLCSP-0.4-0.92X1.16X0.4MM
U5: GD25Q64ENIGR; USON8-0.8-4X3MM
USB0: UBF31-0171; USB2.0-TYPE-C
X1: 40MHz/306011364; X4-SMD-1.6X1.2X0.35MM

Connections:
D0/A0: J2.1, J2.13 (1), U1.6 (GPIO1)
D1/A1: J2.2, J2.14 (2), U1.7 (GPIO2)
D2/A2: J2.3, J2.15 (3), J3.2, U1.8 (GPIO3)
D3/A3: J2.4, J2.16 (4), U1.9 (GPIO4)
D4/I2C_SDA: J2.5, J2.17 (5), U1.10 (GPIO5)
D5/I2C_SCL: J2.6, J2.18 (6), U1.11 (GPIO6)
D6/TX: J2.7, J2.19 (7), R6.2
D7/RX: J1.1, J1.13 (1), U1.50 (U0RXD)
D8/A8/SCK: J1.2, J1.14 (2), J3.3, U1.12 (GPIO7)
D9/A9/MISO: J1.3, J1.15 (3), J3.4, U1.13 (GPIO8)
D10/A10/MOSI: J1.4, J1.16 (4), J3.5, U1.14 (GPIO9)
EN: C21.2, K1.1 (A0), K1.3 (A1), R8.1, TP6.T, U1.4 (CHIP_PU)
ESP_USB_D+: C1.2, R4.2, TP8.T, U1.26 (GPIO20)
ESP_USB_D-: C2.2, R3.2, TP7.T, U1.25 (GPIO19)
GND: ANT1.GND1, ANT1.GND2, C1.1, C2.1, C3.2, C4.2, C5.1, C6.1, C7.2, C8.1, C9.1, C10.2, C11.1, C12.1, C13.1, C14.1, C15.1, C16.1, C17.1, C18.1, C19.1, C20.1, C21.1, C22.1, C23.2, C25.2, C26.2, C28.1, C29.1, C30.1, GND0.1, J1.6, J1.18 (6), J3.1, J3.17, J3.28, J3.29, J3.31, J3.33, J3.34, K1.2 (B0), K1.4 (B1), K2.2 (B0), K2.4 (B1), R1.1, R2.2, R9.1, R10.1, R13.1, TP1.T, U1.57 (GND), U3.A1 (GND), U4.B1 (F), U4.C2 (GND), U5.4 (GND), USB0.A1_B12 (A1/B12/GND), USB0.B1_A12 (B1/A12/GND), USB0.S1, USB0.S2, USB0.S3, USB0.S4, USB0.S5 (S1), USB0.S6 (S2), X1.2 (GND), X1.4 (GND@1)
GND5: L4.1, U3.B2 (SW)
GND6: R13.2, U3.C1 (MODE)
GPIO0: C28.2, K2.1 (A0), K2.3 (A1), R7.1, U1.5 (GPIO0)
IO10/XMCLK: J3.6, U1.15 (GPIO10)
IO11/DVP_Y8: J3.7, U1.16 (GPIO11)
IO12/DVP_Y7: J3.8, U1.17 (GPIO12)
IO13/DVP_PCLK: J3.9, U1.18 (GPIO13)
IO14/DVP_Y6: J3.10, U1.19 (GPIO14)
IO15/DVP_Y2: J3.11, U1.21 (XTAL_32K_P)
IO16/DVP_Y5: J3.12, U1.22 (XTAL_32K_N)
IO17/DVP_Y3: J3.13, U1.23 (GPIO17)
IO18/DVP_Y4: J3.14, U1.24 (GPIO18)
IO21/USER_LED: D3.-, J3.16, U1.27 (GPIO21)
IO38/DVP_VSYNC: J3.23, U1.43 (GPIO38)
IO47/DVP_HREF: J3.22, U1.37 (SPICLK_P)
IO48/DVP_Y9: J3.21, U1.36 (SPICLK_N)
MTCK/IO39/CAM_SCL: J3.24, TP5.T, U1.44 (MTCK)
MTDI/IO41/PDM_DATA: J3.26, TP3.T, U1.47 (MTDI)
MTDO/IO40/CAM_SDA: J3.25, TP4.T, U1.45 (MTDO)
MTMS/IO42/PDM_CLK: J3.27, TP2.T, U1.48 (MTMS)
unnamed: R5.1, U1.54 (XTAL_P)
unnamed: C7.1, R5.2, X1.3 (X2)
unnamed: C8.2, U1.53 (XTAL_N), X1.1 (X1)
unnamed: ANT1.D, C17.2, L2.1, L3.2
unnamed: R2.1, USB0.B5 (B5/CC2)
unnamed: C15.2, L1.2, U1.2 (VDD3P3@1), U1.3 (VDD3P3@2)
unnamed: R1.2, USB0.A5 (A5/CC1)
unnamed: C18.2, L2.2, U1.1 (LNA_IN)
unnamed: CHG0.-, U4.B2 (NCHG)
unnamed: R6.1, U1.49 (U0TXD)
unnamed: R10.2, U4.C1 (IREF)
unnamed: CHG0.+, R11.2
unnamed: D3.+, R15.1
unnamed: C20.2, L3.1
SPICLK: U1.33 (SPICLK), U5.6 (CLK)
SPICS0: U1.32 (SPICS0), U5.1 (/CS)
SPID: U1.35 (SPID), U5.5 (DIO)
SPIHD: U1.30 (SPIHD), U5.7 (/HOLD)
SPIQ: U1.34 (SPIQ), U5.2 (DO)
SPIWP: U1.31 (SPIWP), U5.3 (/WP)
USB_D+: R4.1, USB0.A6 (A6/DP1), USB0.B6 (B6/DP2)
USB_D-: R3.1, USB0.A7 (A7/DN1), USB0.B7 (B7/DN2)
VBAT: BAT0.1, C26.1, Q1.1 (D), U4.A1 (BAT)
VBUS: C10.1, C25.1, D2.+, J1.7, J1.19 (7), Q1.2 (G), R9.2, R11.1, U4.A2 (VIN), USB0.A4_B9 (A4/B9/VBUS), USB0.B4_A9 (B4/A9/VBUS)
VCC_3V3: C5.2, C6.2, C9.2, C11.2, C12.2, C13.2, C14.2, C16.2, C19.2, C23.1, C29.2, J1.5, J1.17 (5), J3.18, J3.19, L1.1, L4.2, R7.2, R8.2, R15.2, U1.20 (VDD3P3_RTC), U1.46 (VDD3P3_CPU), U1.55 (VDDA@1), U1.56 (VDDA@2), U3.A2 (VOS)
VDD_SPI: C22.2, U1.29 (VDD_SPI), U5.8 (VCC)
VIN: C3.1, C4.1, C30.2, D2.-, J3.15, J3.30, Q1.3 (S), U3.B1 (VIN), U3.C2 (EN)

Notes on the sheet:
IO40
IO39
Π Type Impedance Matching
2.Adjust C30 and C16 inward
D0/A0/Qt1
DVP_Y7
Li Battery
IO5
External Flash
Optimize the distance from the positioning hole of the shield to the pads on both sides
DVP_Y3
D10/A10/Qt9/MOSI
0.3A/Pin
2023/1/4
LC Filter
IO1
D1/A1/Qt2
CAM
IO12
ESP32-S3
USB D+
Layout note： Bottom
D9/A9/Qt8/MISO
IO42
S3 IO20/D+
PDM_CLK
LCD
XIAO Header
v1.1
IO47
IO48
IO4
Camera
DVP_Y6
Internal PSRAM
IO21
IO11
BOOT
CAM_SCL
IO10



Board: 2 copper layers, 17.8 x 21.1 mm, 72 parts (11 on the bottom side), 62 nets.

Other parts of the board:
U$7: LOGO-SEEED-NEW-0.94X8.4MM

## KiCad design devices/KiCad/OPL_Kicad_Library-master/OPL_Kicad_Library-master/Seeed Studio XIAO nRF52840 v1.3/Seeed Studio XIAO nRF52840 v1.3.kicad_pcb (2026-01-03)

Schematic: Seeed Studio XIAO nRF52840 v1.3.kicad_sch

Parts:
ANT1: ANTENNA-AN3216; ANT-SMD3P-3.2X1.6X1.04MM
BAT0: TEST-POINT'4080'; TP-80X40MIL
C1, C5, C8, C24, C34: 100nF; C0201
C2, C7: 10pF; C0201
C3, C4, C6, C9, C22, C25, C29, C30, C39, C41, C42: 2.2uF; C0201
C10: 1nF; C0402
C11: 1pF; C0201
C31: 820pF; C0201
C32, C33: 15pF; C0201
C35: 100pF; C0201
C36: 0.8pF; C0201
C37: 0.5pF; C0201
C38: 4.7nH; L0201
C40: DNP; C0201
CHG0: RED; LED-0402
D1: DIODE'0603'; SOD-523
GND0: GND; TP-80X40MIL
J1, J2: DNP; H7-HALF-HOLE-2.54
K1: BUTTON-4P; SW4-SMD-2.8-2.6X1.6X0.53MM
L3: 10uH; L0603
MIC1: MSM261D3526H1CPM; MIC6P-3.5X2.65X0.94MM
NFC1, NFC2: TEST-POINT'4080'; TP-80X40MIL
Q1: PMOS_1.00.60.35MM; PMOS_1.0_0.6_0.35MM
R1, R2: 5.1k; R0201
R3, R5, R7: 2.2k; R0201
R4, R13, R14, R15, R20: 10k; R0201
R9: 100k; R0201
R10, R11: 33R; R0201
R12, R18: 2.7k; R0201
R16: 1M_1%; R0201
R17: 510k_1%; R0201
RGB6: RGB; 4P1010
TP1, TP2, TP3, TP5: TEST-POINT'4545'; TP-D45MIL
U1: NRF52840_QF; AQFN50P700X700X85_HS-74N
U2: BQ25100; BQ25101_DSBGA_6_BQ25101
U3: LSM6DS3TR-C; LGA14-0.5-2.5X3X0.86MM
U6: 3.3V; X2SON-4
U7: DNP; USON2X3_8
USB1: USB2.0-TYPE-C
X1: 32.768KHz; X2-SMD-L1.6X1.0X0.5MM
X2: 32MHz; 4P1612

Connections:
3V3: C3.2, C6.2, C29.2, C39.1, C41.2, J1.5, J1.17 (5), R5.1, R13.1, RGB6.+, U1.A22 (VDD@A22), U1.AD14 (VDD@AD14), U1.AD23 (VDD@AD23), U1.B1 (VDD@B1), U1.W1 (VDD@W1), U1.Y2 (VDDH@Y2), U6.1 (OUT), U7.8 (VCC)
6D_INT1: U1.T2 (P0.11@T2), U3.4 (INT1)
6D_PWR: C1.2, R14.1, R15.1, U1.P2 (P1.08@P2), U3.5 (VDDIO), U3.8 (VDD), U3.12 (CS)
/CE: R20.1, U2.B1 (TS)
DEC4-6: C34.1, C42.1, L3.2, U1.B5 (DEC4@B5), U1.E24 (DEC6@E24)
GND: ANT1.2 (GND), C1.1, C2.1, C3.1, C4.2, C5.2, C6.1, C7.1, C8.1, C9.1, C10.2, C11.1, C22.1, C24.1, C25.1, C29.1, C30.2, C31.2, C32.2, C33.2, C34.2, C35.2, C36.1, C37.1, C39.2, C40.2, C41.1, C42.2, GND0.1, J1.6, J1.18 (6), K1.2 (B0), K1.4 (B1), MIC1.4 (GND@1), MIC1.5 (L/R), MIC1.6 (GND@2), R1.2, R2.1, R9.1, R18.2, R20.2, TP1.T, U1.B7 (VSS@B7), U1.F23 (VSS_PA@F23), U1.G74 (VSS_PAD), U2.C2 (VSS), U3.1 (SDO/DA0), U3.2 (SDX), U3.3 (SCX), U3.6 (GND@1), U3.7 (GND@2), U6.2 (GND), U6.T (GND), U7.4 (GND), U7.PAD (T), USB1.A1_B12 (A1/B12/GND), USB1.B1_A12 (B1/A12/GND), USB1.S1, USB1.S2, USB1.S3, USB1.S4, USB1.S5 (S1), USB1.S6 (S2), X2.2 (1), X2.4 (3)
INTERNAL_I2C_SCL: R14.2, U1.H2 (P0.27@H2), U3.13 (SCL)
INTERNAL_I2C_SDA: R15.2, U1.M2 (P0.07@M2), U3.14 (SDA)
unnamed: R1.1, USB1.A5 (A5/CC1)
unnamed: R2.2, USB1.B5 (B5/CC2)
unnamed: C2.2, U1.D2 (P0.00/XL1@D2), X1.2
unnamed: C7.2, U1.F2 (P0.01/XL2@F2), X1.1
unnamed: R7.1, RGB6.R-
unnamed: R4.1, RGB6.G-
unnamed: R10.2, U1.AD4 (D-@AD4)
unnamed: R11.2, U1.AD6 (D+@AD6)
unnamed: R3.1, RGB6.B-
unnamed: CHG0.+, R5.2
unnamed: ANT1.3, C10.1
unnamed: R12.1, R18.1, U2.B2 (ISET)
unnamed: C22.2, U1.AC5 (DECUSB@AC5)
unnamed: C24.2, U1.C1 (DEC1@C1)
unnamed: C31.1, U1.N24 (DEC5@N24)
unnamed: C33.1, U1.B24 (XC1@B24), X2.1 (2)
unnamed: C32.1, U1.A23 (XC2@A23), X2.3 (4)
unnamed: C35.1, U1.D23 (DEC3@D23)
unnamed: C36.2, C38.1, U1.H23 (ANT@H23)
unnamed: ANT1.1 (S), C37.2, C38.2
unnamed: C40.1, U1.A18 (DEC2@A18)
unnamed: L3.1, U1.B3 (DCC@B3)
P0.02_AIN0_LOW_A0_D0: J2.1, J2.13 (1), U1.A12 (P0.02/AIN0@A12)
P0.03_AIN1_LOW_A1_D1: J2.2, J2.14 (2), U1.B13 (P0.03/AIN1@B13)
P0.04_AIN2_A4_D4: J2.5, J2.17 (5), U1.J1 (P0.04/AIN2@J1)
P0.05_AIN3_A5_D5: J2.6, J2.18 (6), U1.K2 (P0.05/AIN3@K2)
P0.06_USER_BLUE: R3.2, U1.L1 (P0.06@L1)
P0.09/NFC1: NFC1.1, U1.L24 (P0.09/NFC1@L24)
P0.10/NFC2: NFC2.1, U1.J24 (P0.10/NFC2@J24)
P0.13_HICHG: R12.2, U1.AD8 (P0.13@AD8)
P0.14_~READ_BAT: R17.2, U1.AC9 (P0.14@AC9)
P0.16_PDM_DATA: MIC1.3 (DATA), U1.AC11 (P0.16@AC11)
P0.17_~CHG: CHG0.-, U1.AD12 (P0.17@AD12), U2.C1 (PRETERM)
P0.20_QSPI_SIO_0: U1.AD16 (P0.20@AD16), U7.5 (DI)
P0.21_QSPI_SCK: C11.2, U1.AC17 (P0.21@AC17), U7.6 (CLK)
P0.22_QSPI_SIO_2: U1.AD18 (P0.22@AD18), U7.3 (~WP)
P0.23_QSPI_SIO_3: U1.AC19 (P0.23@AC19), U7.7 (~HOLD)
P0.24_QSPI_SIO_1: U1.AD20 (P0.24@AD20), U7.2 (DO)
P0.25_QSPI_CSN: U1.AC21 (P0.25@AC21), U7.1 (~CS)
P0.26_USER_RED: R7.2, U1.G1 (P0.26@G1)
P0.28_AIN4_LOW_A2_D2: J2.3, J2.15 (3), U1.B11 (P0.28/AIN4@B11)
P0.29_AIN5_LOW_A3_D3: J2.4, J2.16 (4), U1.A10 (P0.29/AIN5@A10)
P0.30_USER_GREEN: R4.2, U1.B9 (P0.30/AIN6@B9)
P0.31_AIN7_BAT: R16.2, R17.1, U1.A8 (P0.31/AIN7@A8)
P1.00_PDM_CLK: MIC1.2 (CLK), U1.AD22 (P1.00@AD22)
P1.10_MIC_PWR: C8.2, MIC1.1 (VDD), U1.A20 (P1.10@A20)
P1.11_TX_D6: J2.7, J2.19 (7), U1.B19 (P1.11@B19)
P1.12_RX_D7: J1.1, J1.13 (1), U1.B17 (P1.12@B17)
P1.13_SCK_D8: J1.2, J1.14 (2), U1.A16 (P1.13@A16)
P1.14_MISO_D9: J1.3, J1.15 (3), U1.B15 (P1.14@B15)
P1.15_MOSI_D10: J1.4, J1.16 (4), U1.A14 (P1.15@A14)
PWR_LED: U1.R24 (P1.06@R24)
RESET: C5.1, K1.1 (A0), K1.3 (A1), R13.2, TP2.T, U1.AC13 (P0.18/RESET@AC13)
SWDCLK: TP3.T, U1.AA24 (SWDCLK@AA24)
SWDIO: TP5.T, U1.AC24 (SWDIO@AC24)
USB_D+: R11.1, USB1.A6 (A6/DP1), USB1.B6 (B6/DP2)
USB_D-: R10.1, USB1.A7 (A7/DN1), USB1.B7 (B7/DN2)
VBAT: BAT0.1, C30.1, Q1.1 (D), R16.1, U2.A1 (OUT)
VBUS: C9.2, C25.2, D1.+, J1.7, J1.19 (7), Q1.2 (G), R9.2, U1.AD2 (VBUS@AD2), U2.A2 (IN), USB1.A4_B9 (A4/B9/VBUS), USB1.B4_A9 (B4/A9/VBUS)
VIN: C4.1, D1.-, Q1.3 (S), U6.3 (EN), U6.4 (IN)

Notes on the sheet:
Linus.Liao
2.Change C32,C33 to 15pF
zhihuai.Zhou
Initail Version
the TS and VSS.
NTC:
2021.2.2
Set P0.14 to output Sink only to enable BAT voltage read;
v1.0
2.Add C11 to to resolve the issue of data corruption during Flash read operations.
1.Change 32M Crystal
Disable Temp sense function,
2025.6.20
1.Remove R8
use fixed 10k resistor between
2024.3.19



Board: 2 copper layers, 21.0 x 17.8 mm, 80 parts (9 on the bottom side), 67 nets.

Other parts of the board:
U$14: LOGO-SEEED-NEW-1_3X13MM
UNK_HOLE_0: dummyfp0
UNK_HOLE_1: dummyfp1
UNK_HOLE_2: dummyfp2
UNK_HOLE_3: dummyfp3
UNK_HOLE_4: dummyfp4
UNK_HOLE_5: dummyfp5
UNK_HOLE_6: dummyfp6
UNK_HOLE_7: dummyfp7

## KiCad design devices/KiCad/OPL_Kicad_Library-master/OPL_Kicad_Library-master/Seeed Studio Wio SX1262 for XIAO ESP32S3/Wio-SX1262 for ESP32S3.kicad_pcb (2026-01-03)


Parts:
C1: 100nF; C0402; Voltage Rating 16V,X7R; MPN CC0402KRX7R7BB104
D1: Green; LED-0603; MPN 19-217/G7C-AN1P2/3T
J1, J2: Header 1x7 2.54mm; H7-2.54; Part Type Header
J3: 30pin; BTB2X15-FEMALE-8.6X2.94X3.9MM; Rating DC0.3A; MPN BTB SCOKET P0.40
K1: TS-1185E; BUTTON2P_3_9X3X2MM; MPN TS-1185E
R1, R3: 10K; R0402; Power Rating 5%; MPN RC0402JR-0710KL
R2: 330R; R0402; Power Rating 1%; MPN RC0402FR-07330RL
R4, R5, R6, R7: 47R; R0402; Power Rating 1%; MPN RC0201FR-0745RL
TP1: Test Point; TP-D3_5c2_2mm; Part Type Test Point
U1: Wio-SX1262; MODULE12P-1.27-11X11.6MM; MPN Wio-SX1262

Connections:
+3V3: C1.1, J2.3, J3.23, J3.25, R1.2, R3.2, U1.8 (VCC)
GND: C1.2, J2.2, J3.2, J3.3, J3.5, J3.27, K1.1, R2.1, U1.7 (GND1), U1.10 (GND2)
GPIO14: J3.20
GPIO15: J3.22
GPIO16: J3.24
GPIO17: J3.26
GPIO18: J3.28
GPIO21: J3.29, K1.2, R3.1
GPIO47: J3.17
GPIO48: D1.1 (+), J3.19
LORA_BUSY: J1.2, J3.11, U1.11 (BUSY)
LORA_DIO1: J1.1, J3.13, U1.12 (DIO1)
LORA_RF_SW1: J1.5, J3.15, U1.1 (RF_SW1)
LORA_RST: J1.3, J3.7, R1.1, U1.5 (RST)
LORA_SPI_MISO: J2.5, J3.8, R4.1
LORA_SPI_MOSI: J2.4, J3.10, R5.1
LORA_SPI_NSS: J1.4, J3.9, R7.1
LORA_SPI_SCK: J2.6, J3.6, R6.1
unnamed: D1.2 (-), R2.2
unnamed: R4.2, U1.2 (MISO)
unnamed: R5.2, U1.3 (MOSI)
unnamed: R7.2, U1.6 (NSS)
unnamed: R6.2, U1.4 (SCK)
VIN: J2.1, J3.1, J3.30



Board: 2 copper layers, 17.8 x 21.4 mm, 15 parts (5 on the bottom side), 18 nets.

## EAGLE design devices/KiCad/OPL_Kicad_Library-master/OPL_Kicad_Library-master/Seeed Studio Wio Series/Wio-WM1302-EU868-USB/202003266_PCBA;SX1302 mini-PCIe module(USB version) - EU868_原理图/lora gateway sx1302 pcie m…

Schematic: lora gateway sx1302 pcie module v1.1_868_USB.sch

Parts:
ANT1: U.FL-R-SMT-1(10); U-FL3P-SMD-2.6X2.6X1.0MM
ANT2: DNP; U-FL3P-SMD-2.6X2.6X1.0MM
C1, C12, C15, C19, C23, C25, C26, C29, C32, C41, C43, C45, C65, C67, C80, C83, C86, C88: 100nF; C0402
C2, C75: 2.2pF; C0402
C3, C92: 10uF; C0603
C4, C8, C11, C16, C17, C18, C64: 56pF; C0402
C5, C6, C9, C10: 3.6pF; C0402
C7, C91: 5.6pF; C0402
C13, C20, C21, C24, C28, C35, C39, C40, C42, C44, C47, C48, C76, C87, C89: 1uF; C0402
C14, C38, C57, C66, C81, C84: 10pF; C0402
C22, C27, C33: 10uF; C0603@1
C30, C56, C74, C77, C78, C79: DNP; C0402
C31: DNP; C0603@1
C34, C46, C63: 470nF; C0402
C36: 47nF; C0402
C37: 47pF; C0402
C49: 4.7uF; C0603
C50, C62, C85: 10nF; C0402
C51: 1nF; C0402
C52, C55: 100pF; C0402
C53, C60, C61: 3.3pF; C0402
C54: 39pF; C0402
C58: 1.3pF; C0402
C59, C68, C73: 1.8pF; C0402
C69, C70, C71, C72: 10uF; C0805
C82: 2.7pF; C0402
C90: 2.2uF; C0603
D1, D4: Green; LED-0402
D2: Red; LED-0402
D3: Blue; LED-0402
D5: LXES15AAA1-153; ESD-0402
D6: DNP; ESD-0402
D7: BAT54XV2T1G; SOD-523
FB1: BLM15PD121SN1D; F0402
J1: DNP; PCIE52P-0.8-50.95X30MM
L1: LQP15MN1N2B02D; L0402
L2: LQW15AN6N8G00D; L0402
L4: 0R; F0603
L5: LQH44PN1R0NP0L; L4.4X3.0MM
L6, L14, L20: MLZ2012M150WT; L0805
L7, L15, L18, L21: DNP; L0402
L8: LQW15AN3N0B00; L0402
L9: LQW15AN47NJ00D; L0402
L10: LQW15AN2N5B00D; L0402
L11: LQW15AN4N7C00D; L0402
L12, L13: LQW15AN12NG00D; L0402
L16: LQW15AN7N5G00D; L0402
L17, L24: LQW15AN5N6C10D; L0402
L22: LQW15AN15NG00D; L0402
Q8: CJ2101; SOT-323
Q10: CJ2102; SOT-323
R1, R4, R33, R34, R38, R42, R57, R65, R71: 10k; R0402
R2, R7: 0R; R0603
R3, R8, R11, R12, R43, R44, R46, R49, R51, R55, R56, R59, R60, R61, R62, R63, R67, R70, R72, R73, R74, R75, R76, R81: DNP; R0402
R5, R10, R14, R15, R16, R39, R40, R41: 100R; R0402
R6, R9, R37: 220R; R0402
R13, R35, R52: DNP; R0603
R17, R18, R19, R20, R21, R22, R23, R24, R25, R26, R27, R28, R29, R36, R45, R48, R50, R53, R54, R69, R77: 0R; R0402
R30, R31, R32: 680R; R0402
R47, R79: 1k; R0402
R58, R68: 4.7k; R0402
R64, R66: 22R; R0402
R78, R82: 100k; R0402
R80: 10R; R0402
R83, R87: 200k_1%; R0402
S1, S2, S3, S4, S5, S6: 323030226; SHIELD_CLIP
TP1, TP2, TP3, TP4, TP5, TP6, TP7, TP8, TP9, TP10, TP14: TEST-POINT-35; TP_3535
TP15: TEST-POINT'4545'; TP-D45MIL
U1: SX1302IMLTRT; QFN68-0.35-7X7X0.75MM
U2, U8, U10: HDF866A3-S6; FILTER6P-1.1-3X3X1.3MM
U3, U4: DNP; SOT-23-5
U5, U7: SX1250IMLTRT; QFN24G-0.5-4X4MM
U6: MP2161GJ; TSOT23-8
U9: SKY66420-11; MODULE16P-0.5-3X3X0.75MM
U11: SX1262IMLTRT; QFN24G-0.5-4X4MM
U12: STM32L412K8U6; UFQFPN32-0.5-5X5MM
U13: STTS751; UDFN-6L
X1: DSB221SDN; X4-SMD-2.5X2.0X1.0MM
X3: 32.768kHz; X2-SMD-3.2X1.5X0.55MM

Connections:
32MHZ: R6.2, R9.2, R37.2, X1.3 (OUT)
1302_CS: R33.2, R43.1, U1.1 (HOST_CSN), U12.10 (PA4)
1302_RESET: C1.2, D7.-, R1.2, U1.7 (RESET), U12.8 (PA2)
1302_RESET_HOST: D7.+, R59.1
CONFIG_OK: R31.1, U1.66 (GPIO0)
DM: J1.36, R66.1
DP: J1.38, R64.1
FEM_CS: R14.2, R34.1, U1.10 (RADIO_CTRL0), U3.3 (CE)
FEM_PA_ON: R15.2, U1.16 (RADIO_CTRL4)
GND: ANT1.GND1, ANT1.GND2, ANT2.GND1, ANT2.GND2, C2.1, C3.1, C5.1, C7.1, C9.1, C12.1, C13.1, C15.1, C16.1, C17.1, C18.1, C19.1, C20.1, C21.1, C22.1, C23.1, C24.1, C25.1, C26.1, C27.1, C28.1, C29.1, C30.1, C31.1, C32.1, C33.1, C34.1, C35.1, C36.1, C37.1, C39.1, C40.1, C41.1, C42.1, C43.1, C44.1, C45.1, C46.1, C47.1, C48.1, C49.1, C50.1, C51.1, C52.1, C55.1, C56.1, C57.1, C58.1, C60.2, C61.2, C62.1, C63.2, C65.2, C67.2, C69.1, C70.1, C71.1, C72.1, C73.2, C74.2, C76.1, C77.2, C78.2, C80.1, C81.2, C82.2, C83.1, C84.2, C85.1, C86.1, C87.1, C88.1, C89.1, C90.1, C92.1, D1.-, D2.-, D3.-, D4.-, D5.1, D6.1, J1.4 (GND), J1.9 (GND), J1.15 (GND), J1.18 (GND), J1.21 (GND), J1.26 (GND), J1.27 (GND), J1.29 (GND), J1.34 (GND), J1.35 (GND), J1.37 (GND), J1.40 (GND), J1.43 (GND), J1.50 (GND), J1.S1 (GND), J1.S2 (GND), Q10.2 (S), R1.1, R4.1, R11.1, R12.1, R17.2, R53.1, R53.2, R54.1, R54.2, R55.1, R55.2, R57.2, R73.1, R74.1, R74.2, R87.1, S1.S1, S1.S2, S1.S3, S1.S4, S1.S5, S2.S1, S2.S2, S2.S3, S2.S4, S2.S5, S3.S1, S3.S2, S3.S3, S3.S4, S3.S5, S4.S1, S4.S2, S4.S3, S4.S4, S4.S5, S5.S1, S5.S2, S5.S3, S5.S4, S5.S5, S6.S1, S6.S2, S6.S3, S6.S4, S6.S5, TP3.T, U1.6 (GND), U1.9 (GND), U1.15 (GND), U1.24 (GND), U1.25 (GND), U1.39 (GND), U1.46 (GND), U1.55 (GND), U1.62 (GND), U1.69 (GND), U2.1 (GND), U2.3 (GND), U2.4 (GND), U2.6 (GND), U3.2 (VSS), U4.2 (VSS), U5.7 (GND), U5.20 (GND), U5.PAD, U6.4 (PGND), U6.6 (AGND), U7.7 (GND), U7.20 (GND), U7.PAD, U8.1 (GND), U8.3 (GND), U8.4 (GND), U8.6 (GND), U9.10 (GND), U9.12 (GND), U9.17 (EPAD), U10.1 (GND), U10.3 (GND), U10.4 (GND), U10.6 (GND), U11.2 (GND), U11.5 (GND), U11.8 (GND), U11.20 (GND), U11.PAD, U12.16 (VSS), U12.32 (VSS), U12.PAD, U13.4 (ADDR/!THERM), U13.5 (GND), X1.2 (GND)
HOST_CS0: J1.51, R43.2
HOST_CS1: J1.25, R51.2
HOST_IO1: J1.33, R61.2
HOST_IO2: J1.31, R63.2
HOST_IO3: J1.23
HOST_IO4: J1.8, R67.2
HOST_IO5: J1.10, R60.2
HOST_IO6: J1.12
HOST_MISO: R39.1, R44.2
HOST_MOSI: J1.49, R46.2
HOST_RST: J1.22, R59.2, R77.2
HOST_SCK: J1.45, R49.2
I2C_SCL: R68.2, R76.1, R81.1, U12.29 (PB6), U13.1 (SCL)
I2C_SDA: R58.2, R70.1, R75.1, U12.30 (PB7), U13.6 (SDA)
MCU_RESET: C85.2, R71.2, R77.1, TP5.T, U12.4 (NRST)
MISO: R44.1, R45.1, U1.2 (HOST_MISO), U11.16 (MISO)
MISO_A: U1.42 (RADIO_A_MISO), U5.16 (MISO)
MISO_B: U1.33 (RADIO_B_MISO), U7.16 (MISO)
MOSI: R5.2, R40.2, R46.1, R48.1
MOSI_A: U1.67 (RADIO_A_MOSI), U5.17 (MOSI)
MOSI_B: U1.19 (RADIO_B_MOSI), U7.17 (MOSI)
unnamed: C11.2, U9.2 (RX)
unnamed: TP15.T, U6.1 (PG)
unnamed: C8.1, R11.2, R52.2, U8.5 (OUT)
unnamed: C2.2, L11.2, R52.1, U8.2 (IN)
unnamed: C11.1, R13.2, U2.2 (IN)
unnamed: C4.2, U9.1 (TX)
unnamed: C68.1, C74.1, C75.2
unnamed: C65.1, L18.2, R36.2, U11.1 (VDD_IN)
unnamed: C66.2, R37.1
unnamed: L5.1, U6.3 (SW)
unnamed: R83.1, R87.2, U6.7 (FB)
unnamed: R3.1, R4.2, X1.1 (ENABLE)
unnamed: C14.1, U5.3 (XTA)
unnamed: C62.2, L4.1, R3.2, X1.4 (VDD)
unnamed: R5.1, U1.3 (HOST_MOSI)
unnamed: D4.+, R47.2
unnamed: R10.1, U1.4 (HOST_SCK)
unnamed: R82.2, U6.8 (EN)
unnamed: R8.1, U4.3 (CE)
unnamed: C14.2, R6.1
unnamed: L6.2, U5.8 (DCC_SW)
unnamed: C34.2, L6.1, L7.2, U5.6 (VREG)
unnamed: C64.1, C82.1, L24.2
unnamed: R19.1, U1.34 (RADIO_B_CLK_I)
unnamed: C16.2, R14.1, U9.4 (CSD)
unnamed: C38.1, U7.3 (XTA)
unnamed: C36.2, C37.2, L9.2, U5.1 (VR_PA)
unnamed: C38.2, R9.1
unnamed: L14.2, U7.8 (DCC_SW)
unnamed: C46.2, L14.1, L15.2, U7.6 (VREG)
unnamed: C54.2, L11.1
unnamed: C7.2, C53.2, C54.1, L10.2
unnamed: C4.1, C8.2, R12.2
unnamed: C17.2, R15.1, U9.5 (CPS)
unnamed: C18.2, R16.1, U9.6 (CTX)
unnamed: R17.1, U1.20 (SP_VALID)
unnamed: R18.1, U1.32 (RADIO_B_IQ3)
unnamed: R20.1, U1.35 (RADIO_B_IQ0)
unnamed: R24.1, U1.41 (RADIO_A_IQ3)
unnamed: R21.1, U1.36 (RADIO_B_IQ1)
unnamed: R22.1, U1.37 (RADIO_B_IQ4)
unnamed: R23.1, U1.38 (RADIO_B_IQ2)
unnamed: R25.1, U1.43 (RADIO_A_CLK_I)
unnamed: R26.1, U1.44 (RADIO_A_IQ0)
unnamed: R27.1, U1.45 (RADIO_A_IQ1)
unnamed: R28.1, U1.48 (RADIO_A_IQ4)
unnamed: R29.1, U1.49 (RADIO_A_IQ2)
unnamed: D3.+, R32.2
unnamed: D2.+, R31.2
unnamed: D1.+, R30.2
unnamed: Q8.1 (G), Q10.3 (D), R78.2
unnamed: C1.1, R80.1
unnamed: L1.1, U9.16 (VCC1)
unnamed: L2.1, L8.1, U9.13 (PA_OUT)
unnamed: C56.2, C57.2, L8.2, L16.1
unnamed: C58.2, L16.2, U9.11 (TX_IN)
unnamed: C59.2, C60.1, L17.1, U9.9 (ANT)
unnamed: C61.1, C91.1, L17.2, L24.1
unnamed: C66.1, U11.3 (XTA)
unnamed: ANT1.D, C64.2, D5.2
unnamed: R35.2, R62.1, R69.2, U10.2 (IN)
unnamed: C63.1, L18.1, L20.1, U11.7 (VREG)
unnamed: R35.1, U9.7 (LNA_IN), U10.5 (OUT)
unnamed: L20.2, U11.9 (DCC_SW)
unnamed: J1.47, R39.2
unnamed: R40.1, U11.17 (MOSI)
unnamed: R41.1, U11.18 (SCK)
unnamed: C6.1, C10.1, C75.1, R13.1, U2.5 (OUT)
unnamed: R69.1, U9.8 (RX_FLT)
unnamed: C78.1, C79.1, L21.2
unnamed: ANT2.D, C79.2, D6.2
unnamed: C59.1, C91.2
unnamed: C77.1, L21.1, R62.2
unnamed: R65.2, U13.2 (!EVENT)
unnamed: C52.2, FB1.1, L1.2, U9.15 (VCC0)
unnamed: R64.2, U12.22 (PA12)
unnamed: R66.2, U12.21 (PA11)
unnamed: C92.2, Q10.1 (G), R79.2
unnamed: R56.2, R57.1, U12.31 (BOOT0)
unnamed: R72.2, R73.2, U12.6 (PA0-CLK_IN)
unnamed: C81.1, U12.2 (PC14-OSC32_IN), X3.2
unnamed: C84.1, U12.3 (PC15-OSC32_OUT), X3.1
unnamed: J1.14, R76.2
unnamed: J1.16, R70.2
unnamed: J1.30, R81.2
unnamed: J1.32, R75.2
PPS: J1.19, TP2.T, U1.8 (PPS), U12.27 (PB4)
RADIO_A_CLK_32M: R25.2, R72.1, U5.14 (BUSY)
RADIO_A_CLK_O: R28.2, U5.11 (DIO5)
RADIO_A_CSN: U1.68 (RADIO_A_CSN), U5.19 (NSS)
RADIO_A_IQ_0: R26.2, U5.13 (DIO1)
RADIO_A_IQ_1: R27.2, U5.12 (DIO2)
RADIO_A_IQ_2: R29.2, U5.5 (DIO3)
RADIO_A_IQ_3: R24.2, U5.21 (DIO4)
RADIO_A_RESET: U1.13 (RADIO_CTRL3), U5.15 (NRESET)
RADIO_A_RFIN: C6.2, L12.2, U5.23 (RFI_N)
RADIO_A_RFIP: C5.2, L12.1, U5.22 (RFI_P)
RADIO_B_CLK_32M: R19.2, U7.14 (BUSY)
RADIO_B_CLK_O: R22.2, U7.11 (DIO5)
RADIO_B_CSN: U1.18 (RADIO_B_CSN), U7.19 (NSS)
RADIO_B_IQ0: R20.2, U7.13 (DIO1)
RADIO_B_IQ_1: R21.2, U7.12 (DIO2)
RADIO_B_IQ_2: R23.2, U7.5 (DIO3)
RADIO_B_IQ_3: R18.2, U7.21 (DIO4)
RADIO_B_RESET: U1.28 (RADIO_CTRL9), U7.15 (NRESET)
RADIO_B_RFIN: C10.2, L13.2, U7.23 (RFI_N)
RADIO_B_RFIP: C9.2, L13.1, U7.22 (RFI_P)
RFO: C53.1, L9.1, L10.1, U5.24 (RFO)
RX_ON: R32.1, U1.59 (GPIO4)
SCK: R10.2, R41.2, R49.1, R50.1
SCK_A: U1.65 (RADIO_A_SCK), U5.18 (SCK)
SCK_B: U1.21 (RADIO_B_SCK), U7.18 (SCK)
STM32_MISO: R45.2, U12.12 (PA6)
STM32_MOSI: R48.2, U12.13 (PA7)
STM32_SCK: R50.2, U12.11 (PA5)
SWCLK: TP7.T, U12.24 (PA14)
SWDIO: TP8.T, U12.23 (PA13)
SX1261_BUSY: R67.1, U11.14 (BUSY), U12.9 (PA3)
SX1261_CS: R42.1, R51.1, U11.19 (NSS), U12.14 (PB0)
SX1261_IO1: R61.1, U1.54 (GPIO7), U11.13 (DIO1), U12.15 (PB1)
SX1261_IO2: R63.1, U11.12 (DIO2)
SX1261_IO3: TP9.T, U11.6 (DIO3)
SX1261_RFIN: C68.2, L22.2, U11.22 (RFI_N)
SX1261_RFIP: C73.1, L22.1, U11.21 (RFI_P)
SX1261_RST: R38.1, R60.1, U11.15 (NRESET), U12.18 (PA8)
SX1302_GPIO8: U1.53 (GPIO8), U12.26 (PB3)
TX_ON: R30.1, U1.63 (GPIO2)
TX_RX_SW: R16.2, U1.12 (RADIO_CTRL2)
VCCIO: C3.2, C19.2, C20.2, C25.2, C28.2, C41.2, C42.2, C45.2, C47.2, C76.2, C80.2, C83.2, C86.2, C87.2, C88.2, C89.2, C90.2, Q8.3 (D), R33.1, R34.2, R56.1, R58.1, R65.1, R68.1, R71.1, R80.2, TP1.T, U1.14 (VCC_IO), U1.30 (VCC_IO), U1.47 (VCC_IO), U1.61 (VCC_IO), U12.1 (VDD), U12.5 (VDDA), U12.17 (VDD), U13.3 (VDD)
VCC_1V2: C12.2, C13.2, C23.2, C24.2, C29.2, C40.2, C43.2, C44.2, C71.2, C72.2, L5.2, R79.1, R83.2, TP14.T, U1.5 (VCC_CORE), U1.23 (VCC_CORE), U1.40 (VCC_CORE), U1.56 (VCC_CORE), U6.5 (OUT)
VCC_FEM: C26.2, C27.2, C49.2, C50.2, C51.2, C55.2, FB1.2, L2.2, R2.2, TP6.T, U3.5 (VOUT)
VCC_RADIO: C21.2, C32.2, C33.2, C35.2, C39.2, C48.2, C67.1, L4.2, L7.1, L15.1, R7.2, R36.1, R38.2, R42.2, TP10.T, U4.5 (VOUT), U5.2 (VDD_IN), U5.9 (VBAT_RF), U5.10 (VBAT_DIO), U7.2 (VDD_IN), U7.9 (VBAT_RF), U7.10 (VBAT_DIO), U11.10 (VBAT), U11.11 (VBAT_IO)
VIN: C15.2, C22.2, C30.2, C31.2, C69.2, C70.2, J1.2 (3V3), J1.24 (3V3), J1.39 (3V3), J1.41 (3V3), J1.52 (3V3), Q8.2 (S), R2.1, R7.1, R8.2, R47.1, R78.1, R82.1, TP4.T, U3.1 (VIN), U4.1 (VIN), U6.2 (VIN)

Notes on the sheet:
V1.0
Initial Release
2020/01/02
Vincent
50ohm Impedence
3.3V
300mA
1.2V
500mA
100mA
USB
868
915
SPI
For Power-up delay
V1.1
Add power up delay circuit at VCCIO
Add power up reset circuit for SX1302
Change pins refer to Semtech V3 Schematic
2021/02/18



Board: 4 copper layers, 30.0 x 51.0 mm, 244 parts (68 on the bottom side), 162 nets.

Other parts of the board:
U$45: SEEED-SILK-TNAME-280*268MIL

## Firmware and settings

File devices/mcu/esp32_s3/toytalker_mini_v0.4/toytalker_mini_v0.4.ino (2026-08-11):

// toytalker_mini_v0.4
// v0.3ベース、再生ジッタバッファ追加（不安定回線でのぷつぷつ音切れ対策）
// 受信(producer)とI2S再生(consumer)をFreeRTOSタスクで分離し、PSRAMリングバッファで吸収
// LED制御はすべてdigitalWrite

#include <WiFi.h>
#include <WiFiClientSecure.h>
#include <HTTPClient.h>
#include <WebSocketsClient.h>
#include <ArduinoJson.h>
#include <driver/i2s.h>
#include <esp_wifi.h>
#include <esp_mac.h>  // esp_read_mac (BLEアドバタイズ名用)
#include <BLEDevice.h>
#include <BLEServer.h>
#include <BLEUtils.h>
#include <BLE2902.h>
#include <Preferences.h>

// ==== デバッグ設定 ====
#define DEBUG_MEMORY 0

// ==== WiFi（NVSから読み込み） ====
String wifiSSID = "";
String wifiPassword = "";
String pendingSSID = "";
String pendingPassword = "";
Preferences preferences;

// ==== BLE UUIDs（アプリ側toy.tsxと一致） ====
#define SERVICE_UUID           "12345678-1234-1234-1234-123456789abc"
#define CHAR_SSID_UUID         "12345678-1234-1234-1234-123456789ab1"
#define CHAR_PASSWORD_UUID     "12345678-1234-1234-1234-123456789ab2"
#define CHAR_COMMAND_UUID      "12345678-1234-1234-1234-123456789ab3"
#define CHAR_STATUS_UUID       "12345678-1234-1234-1234-123456789ab4"
#define CHAR_MAC_UUID          "12345678-1234-1234-1234-123456789ab5"

// ==== デバイスモード ====
enum DeviceMode {
  MODE_NORMAL,
  MODE_BLE_PROV,
  MODE_CONNECTING
};
DeviceMode currentMode = MODE_CONNECTING;

// ==== BLE ====
BLEServer* pServer = NULL;
BLECharacteristic* pStatusChar = NULL;
bool bleDeviceConnected = false;
bool oldBleDeviceConnected = false;
String deviceMacAddress = "";

// ==== Lambda (TTS) - Binary Streaming ====
const char* LAMBDA_HOST = "koufofwm3w4tidbe52crbyhpyq0cshss.lambda-url.ap-northeast-1.on.aws";
const char* LAMBDA_PATH = "/";

// ==== Lambda (Backchannel) ====
const char* BACKCHANNEL_HOST = "birb7yjw4nkldidcza4xfiyn5e0taluh.lambda-url.ap-northeast-1.on.aws";
const char* BACKCHANNEL_PATH = "/";

// ==== Lambda (Soniox Key) ====
const char* SONIOX_LAMBDA_URL = "https://ug5fcnjsxa22vtnrzlwpfgshd40nngbo.lambda-url.ap-northeast-1.on.aws/";

// ==== Soniox ====
const char* SONIOX_WS_URL = "stt-rt.soniox.com";
const int SONIOX_WS_PORT = 443;
String sonioxKey;
String sonioxModel = "stt-rt-v4";

// ==== I2S PIN ====
#define PIN_WS     3
#define PIN_BCLK   4
#define PIN_DATA   9
#define PIN_DOUT   5
#define PIN_AMP_SD 6
#define SAMPLE_RATE_STT 16000
#define SAMPLE_RATE_TTS 24000

// ==== LED & Button ====
#define PIN_LED    8
#define PIN_BUTTON 7

// LED状態（PWMなし、digitalWriteのみ）
enum LEDMode {
  LED_OFF,
  LED_ON,          // 点灯 = 録音中（話してOK）
  LED_BLINKING,    // 600ms周期 = 再生中
  LED_BLINK_SLOW,  // 1.2s周期 = 準備中（起動〜録音準備完了）
  LED_BLINK_FAST   // 300ms周期 = BLE設定モード
};

volatile LEDMode currentLEDMode = LED_OFF;
volatile bool blinkState = false;
hw_timer_t* ledTimer = NULL;
bool ampOn = false;
volatile bool bargeInRequested = false;
volatile bool sonioxPreconnectPending = false;  // 再生中の先行WS接続が進行中か

void IRAM_ATTR onBargeInButton() {
  bargeInRequested = true;
}

// ボタン状態
int lastButtonReading = HIGH;
int buttonState = HIGH;
int lastButtonState = HIGH;
unsigned long lastDebounceTime = 0;
const unsigned long debounceDelay = 50;

unsigned long buttonPressStart = 0;
bool buttonLongPressTriggered = false;
const unsigned long LONG_PRESS_MS = 1500;

// ==== WiFi接続状態（イベントベース） ====
volatile bool wifiConnected = false;
volatile bool wifiGotIP = false;

// ==== Soniox STT 状態 ====
WebSocketsClient ws;
String partialText = "";
String sonioxFinalBuf = "";
String lastFinalText = "";
unsigned long lastPartialMs = 0;
const unsigned long END_SILENCE_MS = 800;
bool armed = false;
bool isRecording = false;
bool endpointDetected = false;
bool i2sRecordReady = false;
unsigned long sttRestartMs = 0;  // STT再開計測用

// ==== TTS 受信状態 ====
int curSegmentId = -1;
String responseText = "";
uint8_t* currentPcmBuffer = NULL;
size_t currentPcmSize = 0;

// ==== 相槌（Backchannel）状態 ====
bool backchannelEnabled = true;
const int BACKCHANNEL_TRIGGER_CHARS = 7;

int utf8Len(const String& s) {
  int count = 0;
  for (int i = 0; i < s.length(); ) {
    uint8_t c = (uint8_t)s.charAt(i);
    if (c < 0x80) i += 1;
    else if (c < 0xE0) i += 2;
    else if (c < 0xF0) i += 3;
    else i += 4;
    count++;
  }
  return count;
}
volatile bool backchannelFetching = false;
volatile bool backchannelReady = false;
volatile bool backchannelFired = false;
volatile bool backchannelAbort = false;
uint8_t* backchannelPcm = NULL;
size_t backchannelPcmSize = 0;
String backchannelText = "";
TaskHandle_t backchannelTaskHandle = NULL;

const int MAX_PAST_BACKCHANNELS = 10;
String pastBackchannels[MAX_PAST_BACKCHANNELS];
int pastBackchannelCount = 0;

void addPastBackchannel(const String& text) {
  if (pastBackchannelCount >= MAX_PAST_BACKCHANNELS) {
    for (int i = 0; i < pastBackchannelCount - 1; i++) {
      pastBackchannels[i] = pastBackchannels[i + 1];
    }
    pastBackchannelCount--;
  }
  pastBackchannels[pastBackchannelCount] = text;
  pastBackchannelCount++;
}

// ==== セッションID ====
String sessionId = "";

// ==== 会話履歴 ====
const int MAX_HISTORY = 5;
struct Message {
  String role;
  String content;
};
Message conversationHistory[MAX_HISTORY * 2];
int historyCount = 0;

// ==== 音量調整 ====
const float VOLUME = 1.5;  // デジタルゲイン（クリップ保護あり）。2.0はノイズ増の割に音量差わずかで、1.5がスイートスポット

// ==== TTS設定 ====
const char* TTS_PROVIDER = "ElevenLabs";
const char* TTS_CHARACTER = "default";

// ==== WiFiイベントハンドラ ====
void WiFiEvent(WiFiEvent_t event, WiFiEventInfo_t info) {
  switch (event) {
    case ARDUINO_EVENT_WIFI_STA_START:
      Serial.println("🔷 WiFi: STA started");
      break;
    case ARDUINO_EVENT_WIFI_STA_STOP:
      Serial.println("🔷 WiFi: STA stopped");
      wifiConnected = false;
      wifiGotIP = false;
      break;
    case ARDUINO_EVENT_WIFI_STA_CONNECTED:
      Serial.println("🔷 WiFi: Connected to AP!");
      wifiConnected = true;
      break;
    case ARDUINO_EVENT_WIFI_STA_DISCONNECTED:
      Serial.printf("🔷 WiFi: Disconnected, reason: %d\n", info.wifi_sta_disconnected.reason);
      wifiConnected = false;
      wifiGotIP = false;
      switch (info.wifi_sta_disconnected.reason) {
        case 2:  Serial.println("   -> AUTH_EXPIRE"); break;
        case 15: Serial.println("   -> 4WAY_HANDSHAKE_TIMEOUT (wrong password?)"); break;
        case 201: Serial.println("   -> NO_AP_FOUND"); break;
        case 202: Serial.println("   -> AUTH_FAIL"); break;
        default: break;
      }
      break;
    case ARDUINO_EVENT_WIFI_STA_GOT_IP:
      Serial.printf("🔷 WiFi: Got IP: %s\n", WiFi.localIP().toString().c_str());
      wifiGotIP = true;
      break;
    case ARDUINO_EVENT_WIFI_STA_LOST_IP:
      Serial.println("🔷 WiFi: Lost IP");
      wifiGotIP = false;
      break;
    default:
      break;
  }
}

// ==== NVS操作 ====
void saveWiFiCredentials(const String& ssid, const String& password) {
  preferences.begin("wifi", false);
  preferences.putString("ssid", ssid);
  preferences.putString("password", password);
  preferences.end();
  Serial.println("💾 WiFi credentials saved to NVS");
}

void saveDeviceMac(const String& mac) {
  preferences.begin("device", false);
  preferences.putString("mac", mac);
  preferences.end();
  Serial.printf("💾 Device MAC saved to NVS: %s\n", mac.c_str());
}

String loadDeviceMac() {
  preferences.begin("device", true);
  String mac = preferences.getString("mac", "");
  preferences.end();
  return mac;
}

bool loadWiFiCredentials() {
  preferences.begin("wifi", true);
  wifiSSID = preferences.getString("ssid", "");
  wifiPassword = preferences.getString("password", "");
  preferences.end();
  if (wifiSSID.length() > 0) {
    Serial.printf("📂 Loaded WiFi: %s\n", wifiSSID.c_str());
    return true;
  }
  Serial.println("📂 No WiFi credentials in NVS");
  return false;
}

// ==== BLEステータス送信 ====
void sendBLEStatus(const char* status) {
  if (pStatusChar && bleDeviceConnected) {
    pStatusChar->setValue(status);
    pStatusChar->notify();
    Serial.printf("📤 BLE Status: %s\n", status);
  }
}

// ==== 前方宣言 ====
void tryConnectWiFiFromBLE(const String& ssid, const String& password);
void startNormalOperation();

// ==== BLEコールバック ====
class ServerCallbacks : public BLEServerCallbacks {
  void onConnect(BLEServer* pServer) {
    bleDeviceConnected = true;
    Serial.println("📱 BLE Client connected");
  }
  void onDisconnect(BLEServer* pServer) {
    bleDeviceConnected = false;
    Serial.println("📱 BLE Client disconnected");
    if (currentMode == MODE_BLE_PROV) {
      pServer->startAdvertising();
    }
  }
};

class SSIDCallbacks : public BLECharacteristicCallbacks {
  void onWrite(BLECharacteristic* pCharacteristic) {
    pendingSSID = pCharacteristic->getValue().c_str();
    Serial.printf("📝 Received SSID: %s\n", pendingSSID.c_str());
  }
};

class PasswordCallbacks : public BLECharacteristicCallbacks {
  void onWrite(BLECharacteristic* pCharacteristic) {
    pendingPassword = pCharacteristic->getValue().c_str();
    Serial.printf("📝 Received Password length: %d\n", pendingPassword.length());
  }
};

class CommandCallbacks : public BLECharacteristicCallbacks {
  void onWrite(BLECharacteristic* pCharacteristic) {
    String value = pCharacteristic->getValue().c_str();
    Serial.printf("📝 Received Command: %s\n", value.c_str());
    if (value == "CONNECT") {
      if (pendingSSID.length() > 0) {
        tryConnectWiFiFromBLE(pendingSSID, pendingPassword);
      } else {
        sendBLEStatus("ERROR:NO_SSID");
      }
    }
  }
};

// ==== BLE開始 ====
void startBLE() {
  Serial.println("🔵 Starting BLE...");
  // アドバタイズ名にMAC下4桁を含める（アプリのスキャン一覧で個体を識別できるように）
  uint8_t btMac[6];
  esp_read_mac(btMac, ESP_MAC_BT);
  char bleName[20];
  snprintf(bleName, sizeof(bleName), "ToyTalker-%02X%02X", btMac[4], btMac[5]);
  BLEDevice::init(bleName);
  pServer = BLEDevice::createServer();
  pServer->setCallbacks(new ServerCallbacks());

  BLEService* pService = pServer->createService(SERVICE_UUID);

  BLECharacteristic* pSSIDChar = pService->createCharacteristic(CHAR_SSID_UUID, BLECharacteristic::PROPERTY_WRITE);
  pSSIDChar->setCallbacks(new SSIDCallbacks());

  BLECharacteristic* pPasswordChar = pService->createCharacteristic(CHAR_PASSWORD_UUID, BLECharacteristic::PROPERTY_WRITE);
  pPasswordChar->setCallbacks(new PasswordCallbacks());

  BLECharacteristic* pCommandChar = pService->createCharacteristic(CHAR_COMMAND_UUID, BLECharacteristic::PROPERTY_WRITE);
  pCommandChar->setCallbacks(new CommandCallbacks());

  pStatusChar = pService->createCharacteristic(
    CHAR_STATUS_UUID,
    BLECharacteristic::PROPERTY_READ | BLECharacteristic::PROPERTY_NOTIFY
  );
  pStatusChar->addDescriptor(new BLE2902());
  pStatusChar->setValue("READY");

  BLECharacteristic* pMacChar = pService->createCharacteristic(CHAR_MAC_UUID, BLECharacteristic::PROPERTY_READ);
  deviceMacAddress = BLEDevice::getAddress().toString().c_str();
  pMacChar->setValue(deviceMacAddress.c_str());

  pService->start();

  BLEAdvertising* pAdvertising = BLEDevice::getAdvertising();
  pAdvertising->addServiceUUID(SERVICE_UUID);
  pAdvertising->setScanResponse(true);
  pAdvertising->setMinPreferred(0x06);
  pAdvertising->setMinPreferred(0x12);
  BLEDevice::startAdvertising();

  Serial.println("🔵 BLE advertising started - Device name: ToyTalk-Setup");
  currentMode = MODE_BLE_PROV;
  // 録音中はLEDタイマーが停止しているため再開（長押しでBLEに入った場合の点滅不具合対策）
  if (ledTimer) timerAlarm(ledTimer, 30000, true, 0);
  setLEDMode(LED_BLINK_FAST);
}

// ==== BLE停止 ====
void stopBLE() {
  Serial.println("🔵 Stopping BLE...");
  BLEDevice::deinit(true);
  pServer = NULL;
  pStatusChar = NULL;
  bleDeviceConnected = false;
}

// ==== LED タイマー割り込み（30ms周期）====
void IRAM_ATTR onLEDTimer() {
  LEDMode mode = currentLEDMode;
  if (mode == LED_BLINKING || mode == LED_BLINK_SLOW || mode == LED_BLINK_FAST) {
    static uint8_t blinkCounter = 0;
    // 30msティック数: FAST=5(150ms毎), BLINKING=10(300ms毎), SLOW=20(600ms毎)
    uint8_t ticks = (mode == LED_BLINK_FAST) ? 5 : (mode == LED_BLINK_SLOW) ? 20 : 10;
    blinkCounter++;
    if (blinkCounter >= ticks) {
      blinkCounter = 0;
      blinkState = !blinkState;
      digitalWrite(PIN_LED, blinkState ? HIGH : LOW);
    }
  }
}

// ==== LED制御関数（digitalWriteのみ）====
void setLEDMode(LEDMode mode) {
  if (currentLEDMode == mode) return;
  currentLEDMode = mode;
  blinkState = false;

  switch (mode) {
    case LED_OFF:
      digitalWrite(PIN_LED, LOW);
      break;
    case LED_ON:
      digitalWrite(PIN_LED, HIGH);
      break;
    case LED_BLINKING:
    case LED_BLINK_SLOW:
    case LED_BLINK_FAST:
      blinkState = true;
      digitalWrite(PIN_LED, HIGH);
      break;
  }
}

// ==== 会話履歴に追加 ====
void addToHistory(const String& role, const String& content) {
  if (historyCount >= MAX_HISTORY * 2) {
    for (int i = 0; i < historyCount - 2; i++) {
      conversationHistory[i] = conversationHistory[i + 2];
    }
    historyCount -= 2;
  }
  conversationHistory[historyCount].role = role;
  conversationHistory[historyCount].content = content;
  historyCount++;
  Serial.printf("💾 Added to history [%s]: %s\n", role.c_str(), content.c_str());
}

// ==== mono → stereo 変換 ====
void monoToStereo(int16_t* mono, int16_t* stereo, size_t samples) {
  for (size_t i = 0; i < samples; i++) {
    // クリップ保護: int16範囲を超えたら飽和させる（オーバーフローによる波形破壊を防ぐ）
    int32_t v = (int32_t)(mono[i] * VOLUME);
    if (v > 32767) v = 32767;
    else if (v < -32768) v = -32768;
    int16_t sample = (int16_t)v;
    stereo[2*i]     = sample;
    stereo[2*i + 1] = sample;
  }
}

// ==== I2S 録音設定 (STT) ====
void setupI2SRecord() {
  i2s_config_t cfg = {
    .mode = (i2s_mode_t)(I2S_MODE_MASTER | I2S_MODE_RX),
    .sample_rate = SAMPLE_RATE_STT,
    .bits_per_sample = I2S_BITS_PER_SAMPLE_32BIT,
    .channel_format = I2S_CHANNEL_FMT_ONLY_LEFT,
    .communication_format = (i2s_comm_format_t)(I2S_COMM_FORMAT_I2S | I2S_COMM_FORMAT_I2S_MSB),
    .intr_alloc_flags = 0,
    .dma_buf_count = 8,
    .dma_buf_len = 512,
    .use_apll = true,
    .tx_desc_auto_clear = false,
    .fixed_mclk = 0
  };

  i2s_pin_config_t pins = {
    .bck_io_num = PIN_BCLK,
    .ws_io_num = PIN_WS,
    .data_out_num = I2S_PIN_NO_CHANGE,
    .data_in_num = PIN_DATA
  };

  i2s_driver_install(I2S_NUM_0, &cfg, 0, NULL);
  i2s_set_pin(I2S_NUM_0, &pins);
  i2s_start(I2S_NUM_0);
}

// ==== I2S 再生設定 (TTS) ====
void setupI2SPlay() {
  pinMode(PIN_AMP_SD, OUTPUT);
  digitalWrite(PIN_AMP_SD, LOW);
  delay(10);

  i2s_config_t cfg = {
    .mode = (i2s_mode_t)(I2S_MODE_MASTER | I2S_MODE_TX),
    .sample_rate = SAMPLE_RATE_TTS,
    .bits_per_sample = I2S_BITS_PER_SAMPLE_16BIT,
    .channel_format = I2S_CHANNEL_FMT_RIGHT_LEFT,
    .communication_format = (i2s_comm_format_t)(I2S_COMM_FORMAT_I2S | I2S_COMM_FORMAT_I2S_MSB),
    .intr_alloc_flags = 0,
    .dma_buf_count = 8,
    .dma_buf_len = 1024,
    .use_apll = true,
    .tx_desc_auto_clear = true,
    .fixed_mclk = 0
  };

  i2s_pin_config_t pins = {
    .bck_io_num = PIN_BCLK,
    .ws_io_num = PIN_WS,
    .data_out_num = PIN_DOUT,
    .data_in_num = I2S_PIN_NO_CHANGE
  };

  i2s_driver_install(I2S_NUM_1, &cfg, 0, NULL);
  i2s_set_pin(I2S_NUM_1, &pins);
  i2s_set_clk(I2S_NUM_1, SAMPLE_RATE_TTS, I2S_BITS_PER_SAMPLE_16BIT, I2S_CHANNEL_STEREO);
}

// ==== チャンク管理用グローバル変数 ====
static int g_currentChunkSize = -1;
static int g_bytesReadFromChunk = 0;

// ==== HTTPチャンクサイズ読み取り ====
int readChunkSize(WiFiClientSecure& client) {
  const int MAX_RETRIES = 3;
  for (int retry = 0; retry < MAX_RETRIES; retry++) {
    String line = "";
    unsigned long startTime = millis();
    while (client.connected() && (millis() - startTime < 5000)) {
      if (client.available()) {
        char c = client.read();
        if (c == '\n') break;
        else if (c != '\r') line += c;
      } else {
        delay(1);
      }
    }
    if (line.length() == 0) {
      if (retry < MAX_RETRIES - 1) { delay(100); continue; }
      return -1;
    }
    int chunkSize = 0;
    bool validHex = false;
    for (int i = 0; i < line.length(); i++) {
      char c = line.charAt(i);
      if (c >= '0' && c <= '9') { chunkSize = chunkSize * 16 + (c - '0'); validHex = true; }
      else if (c >= 'a' && c <= 'f') { chunkSize = chunkSize * 16 + (c - 'a' + 10); validHex = true; }
      else if (c >= 'A' && c <= 'F') { chunkSize = chunkSize * 16 + (c - 'A' + 10); validHex = true; }
      else break;
    }
    if (!validHex) {
      if (retry < MAX_RETRIES - 1) { delay(100); continue; }
      return -1;
    }
    return chunkSize;
  }
  return -1;
}

// ==== チャンク境界を超えてデータを読む ====
size_t readBytesAcrossChunks(WiFiClientSecure& client, uint8_t* buffer, size_t length) {
  size_t totalRead = 0;
  unsigned long startTime = millis();
  const unsigned long TIMEOUT_MS = 10000;

  while (totalRead < length) {
    if (millis() - startTime > TIMEOUT_MS) return totalRead;

    if (g_currentChunkSize == -1 || g_bytesReadFromChunk >= g_currentChunkSize) {
      if (g_currentChunkSize > 0) {
        while (!client.available() && client.connected() && (millis() - startTime < TIMEOUT_MS)) delay(1);
        client.read();
        client.read();
      }
      g_currentChunkSize = readChunkSize(client);
      g_bytesReadFromChunk = 0;
      if (g_currentChunkSize == 0) return totalRead;
      else if (g_currentChunkSize < 0) return totalRead;
    }

    int remainingInChunk = g_currentChunkSize - g_bytesReadFromChunk;
    int toRead = min((int)(length - totalRead), remainingInChunk);

    while (!client.available() && client.connected() && (millis() - startTime < TIMEOUT_MS)) delay(1);
    if (!client.connected() && !client.available()) return totalRead;

    int available = client.available();
    if (available > 0) {
      int actualRead = min(toRead, available);
      size_t read = client.readBytes(buffer + totalRead, actualRead);
      totalRead += read;
      g_bytesReadFromChunk += read;
    }
  }
  return totalRead;
}

// ==== メタデータ処理 (type=0x01) ====
void processMetadata(WiFiClientSecure& client, uint32_t length) {
  if (length == 0 || length > 4096) return;

  char* jsonBuf = (char*)malloc(length + 1);
  if (!jsonBuf) return;

  size_t bytesRead = readBytesAcrossChunks(client, (uint8_t*)jsonBuf, length);
  jsonBuf[bytesRead] = '\0';

  if (bytesRead != length) {
    Serial.printf("[META] Read mismatch: expected=%d, got=%d\n", length, bytesRead);
    free(jsonBuf);
    return;
  }

  String json = String(jsonBuf);
  Serial.printf("[META] %s\n", jsonBuf);

  if (json.indexOf("\"event\":\"segment\"") >= 0) {
    int p = json.indexOf("\"text\":\"");
    if (p >= 0) {
      p += 8;
      int e = json.indexOf("\"", p);
      if (e >= 0) {
        String segmentText = json.substring(p, e);
        responseText += segmentText;
        Serial.printf("[SEGMENT] Text: %s\n", segmentText.c_str());
      }
    }
    int idPos = json.indexOf("\"id\":");
    if (idPos >= 0) {
      idPos += 5;
      curSegmentId = json.substring(idPos, json.indexOf(",", idPos)).toInt();
    }
  }

  if (json.indexOf("\"event\":\"tts_start\"") >= 0) {
    int sizePos = json.indexOf("\"size\":");
    if (sizePos >= 0) {
      sizePos += 7;
      currentPcmSize = json.substring(sizePos, json.indexOf("}", sizePos)).toInt();
      Serial.printf("[TTS_START] id=%d, size=%d\n", curSegmentId, currentPcmSize);
    }
  }

  free(jsonBuf);
}

// ==== 再生ジッタバッファ（PSRAMリングバッファ + 再生専用タスク） ====
// 不安定な回線でのぷつぷつ音切れ対策:
// 受信(メインループ=producer)とI2S再生(playbackTask=consumer)を分離し、
// リングバッファでネットワークジッタを吸収する。
#define PLAY_RING_SIZE   (512 * 1024)  // 512KB ≈ 5.4秒分 (24kHz/16bit/stereo)
#define PLAY_PREBUFFER   (32 * 1024)   // 再生開始/再開前に溜める量 ≈ 0.34秒
#define PLAY_WRITE_CHUNK 4096          // I2Sへの1回の書き込み量
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
void loop() {
  if (currentMode == MODE_BLE_PROV) {
    handleButtonLongPress();
    if (!bleDeviceConnected && oldBleDeviceConnected) {
      delay(500);
      if (pServer) pServer->startAdvertising();
    }
    oldBleDeviceConnected = bleDeviceConnected;
    delay(10);
    return;
  }

  ws.loop();
  handleButtonLongPress();

  // ボタンデバウンス
  int reading = digitalRead(PIN_BUTTON);
  if (reading != lastButtonReading) lastDebounceTime = millis();
  if ((millis() - lastDebounceTime) > debounceDelay) {
    if (reading != buttonState) {
      buttonState = reading;
    }
  }
  lastButtonReading = reading;

  // 録音データ送信
  if (isRecording && wifiGotIP && ws.isConnected()) {
    static uint32_t lastSend = 0;
    static uint32_t sendOk = 0, sendFail = 0;
    static uint32_t lastStats = 0;
    if (millis() - lastSend > 5) {
      int32_t raw[512];
      int16_t pcm[512];
      size_t n = 0;
      i2s_read(I2S_NUM_0, (void*)raw, sizeof(raw), &n, portMAX_DELAY);
      int samples = n / sizeof(int32_t);
      for (int i = 0; i < samples; i++) {
        pcm[i] = (int16_t)(raw[i] >> 14);
      }
      bool ok = ws.sendBIN((uint8_t*)pcm, samples * sizeof(int16_t));
      if (ok) {
        sendOk++;
        if (sendOk == 1 && sttRestartMs > 0) {
          Serial.printf("⏱️ STT [%lums] First audio packet sent\n", millis() - sttRestartMs);
          sttRestartMs = 0;
        }
      } else {
        sendFail++;
      }
      lastSend = millis();
    }
    if (millis() - lastStats > 5000) {
      statsRecordRssi();  // 録音中(待機側)のRSSIも記録
      Serial.printf("[STT] send ok=%d fail=%d RSSI=%d heap=%d\n", sendOk, sendFail, WiFi.RSSI(), ESP.getFreeHeap());
      sendOk = 0; sendFail = 0;
      lastStats = millis();
    }
  }

  // Sonioxエンドポイント検出
  if (endpointDetected && partialText.length() > 0) {
    if (partialText != lastFinalText) {
      lastFinalText = partialText;
      sendToLambdaAndPlay(partialText);
    }
    endpointDetected = false;
    armed = false;
    partialText = "";
    sonioxFinalBuf = "";
  }
  // 無音検出フォールバック
  else if (armed && partialText.length() > 0 && (millis() - lastPartialMs) >= END_SILENCE_MS) {
    if (partialText != lastFinalText) {
      lastFinalText = partialText;
      sendToLambdaAndPlay(partialText);
    }
    armed = false;
    partialText = "";
    sonioxFinalBuf = "";
  }
}

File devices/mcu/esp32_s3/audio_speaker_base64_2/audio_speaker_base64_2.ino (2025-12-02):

#include <driver/i2s.h>
#include "mbedtls/base64.h"

#define PIN_BCLK   4
#define PIN_LRC    3
#define PIN_DIN    5
#define PIN_AMP_SD 6
#define SAMPLE_RATE 52000  // OpenAI PCM16 は 24kHz 固定

// ---- テスト用PCM Base64（短めでOK）----
const char* BASE64_DATA =
"HQAxABwAJwAhACUALAAYACoAFwAoAB8AIAAqAB8ALwATAC0AGAAoAB8AHgAlAB0AKAAXACkAGgAhAB0AHgAcABoAGQAaABUAEAATAA4AEQADABIAAAAWAPz/BwD9/wAAAwDr/wYA5v/9/+T/7f/r/+P/8v/c/+v/1v/i/9f/1//a/9b/2//N/87/yv/O/8X/yv/L/8L/yf+8/8v/u//F/8H/u//E/7b/xv+z/7z/vv+7/8D/s/++/7j/v/+9/7v/wP+4/8H/vv/F/7//w//A/7//yv+9/9D/u//R/8f/0//Z/8v/6//L//L/2v/w//L/6f8JAOz/CQD7/wcADQAFAAwABAAMAA4ACAATAAoADQAXAAkAGQAJABUADQAFAA8A+v8KAPj//f/2/+//7P/h/+H/2//U/9X/0P/K/9L/w//J/8T/wf/B/7b/uv+x/63/sv+j/6//nv+n/6H/nv+k/5j/pf+X/6b/n/+l/63/pv+x/6//uP+t/7f/uP+2/7L/rv+3/6r/tf+v/6r/rP+p/7H/r/+5/7f/v//B/8P/zv/O/9X/2f/e/97/6P/p/+n/6f/t//D/8P/3/+///P/2//////8DABAABwAaAA8AGAAYABcAJQASACUAFQAWABcABAAVAP7/DgD6/wAA+v/n//j/5//y/9r/4P/b/9j/2P/W/9H/yP/H/77/uP+y/6b/n/+S/4P/fP9q/2n/Vf9R/0P/Nv82/yH/J/8U/xD/DP/7/gD/6/71/un+4P7j/s3+2v68/sj+wf7A/sD+s/7C/rj+yP7E/tH+3P7e/vL+8v4K/wb/If8n/zT/S/9K/2f/Xv+B/3//kP+n/6X/wv+2/9b/3//u/wAABgAiABwANgA9AE0AXABmAHUAeQCGAIsAjgCbAKYAqwCxALgAwQDGANcA3gDoAPUA9gAMAQkBIAEkAS0BRAE3AWIBSQFqAWMBZwGAAWcBjgFrAYwBfwGAAZQBdwGgAXwBlwGUAYoBowGJAaABkQGSAZoBggGVAYEBggGAAW8BfQFnAXEBZwFbAWEBTAFMAUYBOgE4ASkBIwETAQUB/wDiANsAwAC1AJ8AhgB/AFcARgAoAA0A8P/M/8D/lv+C/1v/Qf8Z//L+1P6l/oH+Uf4n/vr90/2k/Wz9Qv0T/eH8r/yM/Fb8OPwN/O771vuz+7H7lfua+5L7ivuj+5n7wPvE++b7/fsc/FL8bfzE/PL8Tf2J/e79O/6j/gX/bv/x/z8A8gAsAdIBNAKiAi0DXgP9AyIEiQTZBP0EbwV0Bc0F8gUbBlAGUwaOBocGqQaoBqkGrQafBqkGeAZxBjcGDwbbBX0FVwXdBKgERgTmA6oDOQMGA54CUAL7AY0BOwHCAFQA2/9y//n+cf73/XP98fxd/L/7GvuA+ur5Svmy+CD4lvcY96P2I/a/9T311/Rd9Pfzm/Mv8wrzsPKZ8nnySvJ08jjyhPJz8qzyDvMd89Tz+fO09CL1p/Vx9tX2ufcz+P/4yPln+l77+Pv//Lr9pf6J/zwASAHTAeMCfwM5BBIFiAWNBuYGwgdaCM4IlAnlCYQK8ApfC+QLRwyjDDUNXg3mDSwOQA6xDnwOzw6mDpoOoA5IDj0O7A2UDUwNxwxQDN8LMgvSCjEKuglcCbcIdgjsB4QHFweYBjQG0AVPBR0FqARzBC0E6gPZA4gDiANNA04DPAM3AzcDRQNFA1EDTwNFA0UDLgMeA/sC5gKxApYCWQIqAuYBogFZAQIBpQBBANf/aP/k/mr+2v1K/bT8B/x3+8X6NvqQ+fv4i/jk94H38/aG9hT2nPUx9bf0TfTp84DzMPPd8nzyUfLn8cDxb/FD8TjxCvFN8UvxtfHy8WXy4vJN8+TzP/Td9Fv1//Wt9nH3NPgd+e358vrH+7T8y/2Y/uD/owDzAesC4gMiBd0F6QawB1QICwmACdoJXgpoCv0KFgtDC8ILigsODOsLBwxCDBoMTAw5DDMMPwwhDAAM3wuNC1ELAQuHClcK5AmPCYYJFwlOCSIJCAk/CdYIIAnVCL0I4QhvCJIIQgj4B+UHTgcXB50GHgboBUIF7wRtBOMDpgMHA74CSwLLAYUB9QCVABEAkP8v/6r+Uf7X/V399Pxn/On7Yvuy+hz6dPnR+EX4qvcx96f2N/bQ9Vf1/vR/9BH0m/MG86ryKvK78U3x0PCB8Bnw2O987xPv2e6C7k/uN+4L7hruKu5M7truLO8A8MjwoPHV8rXzCfUQ9lP3sPjc+WD7nfze/R7/OABcAXMCWANxBDcFIgYgB6cHlQgLCZ4JTwqmClQLugv6C2YMbwySDLEMYQxsDJELdgveCkYKAwpECRsJiAhgCHAIQQhnCE4IKAg+CO8HFQjgB+wHKwhMCNQIAglLCVUJjwmOCYMJZwkhCfUI1Qi+CMUIygjsCPII0gjRCFEI/gdaB6YGNwZkBfYEOASKA+oC4wEfAfb/1v6f/V38Vfsj+ij5PfhG93H2mvXC9P/zFPMx8k3xh/C/7wnvh+7I7W/t7uxq7PnrZevY6kDqyel16UHpIOl76cXpZuoR68XrwOyG7Z3uqe+v8BjyFfNp9MD12vaY+Lf5aPvU/Az+qv+uACUCPAMnBEMFCgYQBxQIvQiqCTYK9QqNC8YLOAwVDCoMOgwfDCMMEgwFDO4L5AvSC8ELqwt6C2ELLwv2CtcKrArDCqIK1woECy8LrgvaCyoMYwxxDK4MlgzJDOQM3Aw4DUUNqA3ODbgNvg1pDSsNwgw7DLEL/ApjCs0JEgmHCLIHCAcrBkkFfwRIAz0CCgH3/wf/+f0V/RX8MftJ+jT5Sfgy9wL2/fTk8+7yB/IK8T7wYe967qztwOzd6/bq/emF6dnofuiO6H/o4ugr6bzpburW6n/rDeyI7EzttO2j7mzvNfCS8bfyRfSC9eT2gfiz+c/6y/vJ/ND93P4XAIsBpALgA7kElgUwBjwGxAbGBvkGOAdJB9IHCAiRCDMJhgn0CfkJ+An1CbAJnQm8CbsJTgqKCvgKzwuhCzoM9wvoCy0MnAsMDBEMsQyCDf0NAw95D8QPSBBKEFoQWBDbD+UPwg/fDxMQ4g/SD7sPTQ+sDqwNIQwQC2YJEwgSB9UF/wTlA2kDeQL5ALv/6f2W/CD7lvkG+Yf38fZs9rH1QfVR83jy9fBS7+btGuyR6x3qaekx6VPoR+jZ5/vnh+gk6F7o5OiH6XfqvOqz68XsGO0w7lDvjvDG8WbzJfVQ9l/37Pcv+aX6IPuO/Hz+tP8kASYCLANHBI0EwgU/BnYFrQW3BRcGwQa7BmoHxwdfCPYIRwlPCYIInQglCB8IhQhACLcImglLClILmgt7Cm0K5wmzCfsJ6QmhCicLNQx9DScOJg9CD2cPUBCbDzYPkw98D5kQrxBJEUkSGxKXEtYR/hCuD44N8QuVChoJEQgtB/MFYgX0A0wDWwJmAEL/2P3Y/PH7Tvvw+jn7jPq5+ev4ivWi83fxh+/07V7q/Oe85eLkKORg46PjuuKp4mbjFOU55T/m2ea05izp2ee66efrPO6d8g32jvqT+ln7c/ti/S7/YwAAArkBCQM5AxQHcgkyCJ0H4wWoBDMDGAH5/gj+BP1H/loAv/+s/e/75PsR+6P6TPk8+CX5s/ro/UoBgwN1BBEGfwfjBxkIFQhGCaALGA7YEPwTvhWdF/4YqRk3GYIXyRZVFoAX3RisGeoaohvDGwkc2hrBF6cUcBFtDwsOigwQC7AJagiYBlsE5AGc/o/7qfk/+OD3cPfB90j5jfrC+zP7bfmz96n1GPXi9K70TvO08Pfu0uwV7FjqlOcF5FHhxuBD4nzlFeiT7GLtbO8q7p3r0uoL6uvvPPTN+5f9wf8kBDoH3wwHC5IK3gNkBCcGOAa5CkIHXghRCIsIwgbKAZb8SPco9WP1g/WX9N32efbj+M35CvcM9pnzjvRy9r/5Jvxx/kwC4AUVC8cNwQ3rC3ULYQyrD7wT8hX6F5kYMBojGtwa1BnrF2IX5BRqFBAT7hL4E8AVSRdZFvIU/xCtDvQMCwyNDDML5wkYCB0HlwaxBeMEagKi/zH9X/oJ+pD7Dv0oARwDegNWAy8BvwDWANsAiwDg/sT73vdG9NXxS+2O6hjlKeDD3C7Z/Ns031zoLes/7cHrruQI5vrli+sA7231HPnxAGkJpQoSDjYLTQsQCiMKEgcBBW8FDwabC3QLQwnkAz39A/kL8+/wje4C7Tnwy/AF8xb0pfQH9Sj20PYN9Vv24PaM+hQA5QYADZkQTBIVD60N/gtgDcMQdBO7FWAU4BNIE+YTRxR1E90PBwztCWkHJQnEC2oOTBF+EjgSdxBVEHYPgBDMEdIQMRDmDYsNTg1QDVkMkQjHBKH/0/x/++761PwH/mcAgAGjAdYAmv+KAJAA8QF6AKL8CvgC9DzypO3M6Snh29ia1cbWDtrZ4NrmouhD7cnsXedX4W/g/+XD8m0ApgYPBy0JtQtoEUkWkRNGDdkGowTHA4oH6QciCfoJSgbTAJP3WfC06Unq9uvI7OXuYO6j7wbzfvZx+Lv3jvbN9AH2RPqU/ykHPg3MEgsUlxHzDr8NcA7QEU0TsBMSE0wT4BSRFXQVTxIGDhAIDATCAhMEgweXC5gNJA4TDnQN1A3MDuoOtQ+PD7gPTRAzEBEQmA5UDEgI1gM6AK78Mvk3+tr66P1bAekBWwGUANMAhwCWAusA9vv9+O/z8O/O68HlUt8c1yzWG9Ex0iHXZ90u6KbwHfJy6OTggNon4P/tlPojBfMIVgpvDJYRsROvFKAQIwq5A/IAewAaAkkG8wf4Bj4Czvhg76rnnuS45nvrkO828vLz/PKt9GH3W/lU+9P68/nv+i0A7gdgD5cVdhdDFoETExC+DigPhRFXFAUXGhfqFNkS6BCSDsELPQiFAzMBCQAEAycHsQtkD8UQTBGqEOYQKhB/EKsRBBORE8cSXBGYDUoJoQXtAFj9FfoZ+NH3GPmF/Ob+KAInA1YDGQKmADX+ofps9wPyYu7q6PTkGd8H27jYu9i23VHiYek/7qzvVeqT43baAdq/5Wn1twYgEMwSdhBOEjAVeBchFWoNNweOAgIDywOzBR0GzATfALP39O2C5Y3huuRX6Qzux/HU8xr0j/U++d35fPzQ/Rn+x/4bAkMHKA0dFOUWgxa6EnIPGg5ND3QS2xQOFp4VQBWLEhUQ6gvcB/0DZQH7/zH/lgHdBI8JWw5tEXATTBSBFMYT7BOWEpkQLg9pDqQNzQviCE4Dr/62+bn3NveP+JL7av1LAWkCmQM5BFAEVQKK/j75WvIY7fjo3uXV49Hg39yu2sHeuuQe60fuz+aS3LbVNddi4TjzDwOVC6ISDRZuGnMcLht9E7cMmAhvBfoF0AMOAzED9QK5//f4r/Ar54bi+eH35Ovp0+6i8nL2+vrk+8H8VPyZ++387P/3A8IIHg4qEnwU9BVqFmMUfxICECIPPRCuET0TmxKtEXIN0AdfARH8cvof+6z+0AHsBWUJHA0JE8UX9Bp5GkIXRxPbEL4PTQ6JDcQLiQpuCE0F1gBH/A/6EPnm+Yr6sfro+kH8vf2u/l/+cfpW9pfw3O2A61Hp1edl5sblkeWg5k7kNuQ95HniZN+t2lXaLd837koCvBQOJBcm3h5HFJoKEwfZC6QO3AvfBwYACvwI/D4ARv0h9Y7qVd2L28DfgeeB7mn0gvjR/GL/hf5w/q39MgFDBCEIYgtZDU4QURRiGHsZMRjtE5IPQA/YEDUT8xRMFMAQ6goFA9T7tvcP92/6BP7IAowG0As5EUsWYxo1Ge8W2RHCDoINUw3cDoYPrBD+DtILdwblAdX9mPoy+Ez2svZh9hf4afpa/BX+gf3U+rD2Y/OO8Lnt6+rO6Zjon+eL54vl+eWy5B3jnd4I2ZvXPdid5kn81xVQKEcs2SCqES4KrAi8DBMNaQrOATr/s/7I/n3/Ifv085PrC+bc4AvijeTv6l3z2fmx/nv/rAASAF4C8APVBDUGtwc6DOUQ5hVvGFYaORplGL8VKRLgD/MO/Q4IDSQKlgZWAoD/J/6l/YH+9/8qAlsG1wveEU4VRBavFFcScxAiDkUNRAzDDBMN1w3bDccLkggCBHb/X/o092Tz2vGm8ln01fdo+wr9tfpA94vyOO5g7AvqwOaC5ovm3+YR5wTnseOp39XZwtPh1EPgHfUZDW4jSypFJroZ1gp+BtkJ7g2eDRoJtAIgAAQCRwJM/QD16OmN4cTeSuAM5NLqmPCY97z9agDHAUYBUwGMACADogX2CSAQsxMyF/0YRBnhGHgX3BRdEggR3A61DQkMSwkVBgkDygBQAIoBwQFVAmwEZgeXDJ8QcRIEEqMPcw31C50LtgteDF0MKgy6DEsMJAk2BR3+iPjo9H3zafSG9Q34g/np+gH6/vag89zvWu3L7Err8+rO6APmleOz4uPhyd9J2t/T89Nw3lb2TA8MJJcn5h6uE6EKIAvEDdcOxAyLCHYEDwJDAIr+z/rp9KXrKuMo4FfgIeYI7cvymfh7/Fn+CP9F/yMBzwJzBYwIvQpmDg8RFxWnGKUbzRthGH0Thg8XDukNMg4wDFcKFwjzBUoENgJ5ARQBlwLaBZIJmQ2pDxUQXg95DpsN5wzkC/0LDw3zDYwOVQzvCL0EWQGZ/Tv78fiG9uL23/bx9wD4ifdW9R/zn/En71HsUOmc5mPlL+eS577mh+A61xHNtsso1y7t5AixG38eiBUgDvYJxQ1eEpsQ
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

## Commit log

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2025-11-15 ok 70% ok speaker_oepnAI_base64_pcm_sound but 30% noise exists
    [audio_speaker_test_base64_openai_pcm.ino]
2025-12-02 Fix ESP32 audio playback with chunk-based base64 decoding and PSRAM
    - Modified audio_speaker_tts_3.ino to concatenate base64 chunks before decoding
    - Added I2S setup and mono-to-stereo conversion
    - Switched from malloc to ps_malloc to use PSRAM for large audio buffers
    - Resolves memory allocation failures when decoding streaming TTS audio
    [audio_speaker_base64_2.ino, audio_speaker_base64_3.ino, audio_speaker_test_base64_openai_pcm.ino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]
2025-12-06 Fix ESP32 audio distortion by reducing digital volume to 30%
    - Add VOLUME constant (0.3) to monoToStereo function
    - Reduce PCM amplitude before sending to I2S/MAX98357A
    - Workaround for floating GAIN pin causing unstable amplifier gain
    - Eliminates audio distortion and clipping issues
    Technical details:
    - MAX98357A GAIN pin is currently unconnected (floating)
    - This causes unpredictable high gain leading to signal clipping
    - Digital volume reduction prevents input signal from saturating amp
    - Future improvement: Connect GAIN pin to GND for hardware fix
    [audio_speaker_tts_3.ino]
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2025-12-07 Implement pipeline audio decode with FreeRTOS for ESP32 (#5)
    * Implement pipeline audio decode with FreeRTOS for improved latency
    - Add FreeRTOS decode task running on Core 0
    - Implement dual-queue system (encode queue → decode task → play queue)
    - Decode and playback now run in parallel with SSE reception
    - First audio chunk plays immediately after decode (no waiting for all chunks)
    - Fix String copy issue in FreeRTOS queue by using char* pointers
    - Remove blocking timeout after SSE complete
    Performance improvement:
    - Audio playback starts immediately when first chunk is ready
    - Significantly reduced latency from speech recognition to audio output
    - Eliminated 5-second timeout wait af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
    [toytalk_demo_v1.ino]
2025-12-07 Reorganize KiCad files and add MAX98357A GAIN pin support (#6)
    * Fix MAX98357A GAIN pin initialization for volume adjustment
    Modified setupI2SPlay() to properly initialize the amplifier when GAIN pin is connected to GND (15dB gain):
    - Set SD pin LOW initially to shutdown amplifier
    - Wait 10ms for amplifier to read GAIN configuration
    - Configure I2S driver
    - Set SD pin HIGH after I2S setup to enable amplifier
    This ensures the MAX98357A reads the GAIN pin state during its initialization sequence before audio playback begins.
    * Reorganize KiCad files and add MAX98357A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
    [test.kicad_pcb, test.kicad_sch, toytalk_demo_v1.kicad_pcb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]
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2026-01-03 Fix playback noise and audio cutoff with immediate chunk-by-chunk playback (#8)
    * Implement immediate chunk-by-chunk playback
    Replace queue-based audio pipeline with immediate playback:
    - processPCM() now immediately converts and plays PCM chunks
    - Simplified sendToLambdaAndPlay() loop (135 lines → 34 lines)
    - Removed AudioChunk struct, queues, and decodeTask (~200 lines)
    - Added responseText reset for clean conversation tracking
    This eliminates playback noise from parallel processing and enables
    continuous multi-segment playback. Audio starts faster and plays
    smoother than the app.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
    [toytalk_demo_v1.1.ino]
2026-01-04 Add toytalk_demo_v1.2 with LED and button control (#9)
    - Add WS2812 LED support on GPIO8 with state indication:
    * Blue: Standby (waiting for recording)
    * Red: Recording (after STT connection)
    * Yellow: Processing (sending to Lambda)
    * Green: Playing (TTS playback)
    * White blinking: Error
    - Add button support on GPIO7 with debounce handling
    - Optimize LED updates to minimize strip.show() calls:
    * Only update on state transitions
    * Skip redundant updates when state unchanged
    * Prevents WiFi/WebSocket interference from interrupt disabling
    - Set LED brightness to 3 for comfortable viewing
    - Use Adafruit_NeoPixel library with optimized update strategy
    - Requires PSRAM enabled for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
    [toytalk_demo_v1.2.ino]
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2026-01-18 Add experimental SE (sound effect) feature for input end
    - Add se_input_end.h with PCM sound effect data
    - Implement async SE playback using FreeRTOS task on Core 0
    - Pre-allocate stereo buffer at startup to avoid runtime malloc
    - SE plays when user input is confirmed (before Lambda request)
    Note: This is experimental. SE playback may cause slight delay in response time.
    Keeping as separate experimental version for future improvement.
    [toytalk_demo_v1.3_se_experimental.ino]
2026-01-20 Add BLE WiFi provisioning for ESP32
    - Add BLE test sketch for WiFi provisioning via smartphone app
    - ESP32 acts as BLE GATT server with SSID/Password/Command/Status characteristics
    - Store WiFi credentials in NVS for persistence across reboots
    - Add retry logic with Country=JP setting for iPhone hotspot compatibility
    - Add BLE settings UI in app's toy tab with react-native-ble-plx
    - Add required Bluetooth permissions for iOS and Android
    [ble_wifi_provisioning_test.ino]
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2026-03-05 KiCADの回路図とPCB図を修正して再発注
    [AP2112K-3.3TRG1.step, BQ24074RGTR.step, ESP32-S3-WROOM-1-N8R8.step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]
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2026-03-06 Bump version to 0.6.0 and update release notes
    - version: 0.5.5 → 0.6.0, buildNumber: 14 → 15
    - Add ver0.6.0 release note in settings.tsx
    - Fix ver0.5.6 date (20260210 → 20260120)
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2026-03-07 Add DynamoDB voice config lookup and FishAudio TTS to ESP32 Lambda
    - ESP32 Lambda: resolve voice from DynamoDB via device_id
    - GET toytalker-devices for voice_id, GET toytalker-voices for provider/vendor_id
    - Fallback to default if device_id missing or not registered
    - Add FishAudio TTS support (PCM, 24000Hz)
    - Add FishAudio to MODEL_TABLE and normalizeModelKey
    - Fix deploy.sh: use --external for AWS SDK (ESM, 253KB vs 1.3MB)
    - ESP32 firmware: send device_id in Lambda payload
    - Save BLE MAC to NVS on WiFi setup success
    - Load BLE MAC from NVS on boot
    - Update .gitignore: exclude bundle.mjs, bundle.js
    [toytalk_demo_v2.0.ino]
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2026-03-07 Increase TTS buffer flush delay from 1s to 2s to fix audio cutoff
    [toytalk_demo_v2.0.ino]
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2026-03-07 Fix WiFi setup UX and adjust TTS buffer delay
    - Auto-navigate home on BLE disconnect (onDisconnected)
    - Ignore BLE disconnect errors in sendWiFiConfig (expected after CONNECT command)
    - Keep device registration success message on home screen
    - Reduce TTS buffer flush delay from 2000ms to 1500ms
    [toytalk_demo_v2.0.ino]
2026-03-07 Fix BLE stop hang by using ESP.restart() after WiFi setup
    - Replace stopBLE()/startNormalOperation() with ESP.restart()
    - WiFi credentials and BLE MAC are saved to NVS before restart
    - Device auto-connects to WiFi on reboot and starts normal operation
    [toytalk_demo_v2.0.ino]
2026-03-09 Add character system with personality prompts
    - toytalker-device-setting-lambda: add GET/POST/DELETE /characters endpoints, update PUT /devices to use character_id
    - toytalk-api-stream-for-esp32-lambda: resolve device→character→voice chain, inject personality_prompt into system prompt
    - toy.tsx: rename voice→character, character selection screen
    - settings.tsx: character management screen with list/create/delete and personality templates
    - DynamoDB toytalker-characters seeded with 5 system characters (default/pirate/ninja/scientist/wizard)
2026-03-09 Add character edit UI with voice selection and fix DynamoDB reserved words
    - settings.tsx: add edit screen for custom characters, voice selection modal, delete button with confirmation
    - settings.tsx: system characters are view-only, custom characters tap to edit
    - toytalker-device-setting-lambda: add PUT /characters/{id} endpoint
    - Fix: escape DynamoDB reserved words (name, description) with ExpressionAttributeNames
2026-03-09 Refactor settings screen: STT and character management as nav rows
    - Replace STT dropdown with dedicated selection screen with descriptions
    - Remove label prefixes, use nav row style buttons for both STT and character management
    - Update Soniox description text
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2026-03-09 Add scroll-to-bottom button, keyboard avoidance, and UX improvements to chat/settings
    - Add floating ↓ scroll button in chat that appears when scrolled up
    - Fix keyboard covering input area with KeyboardAvoidingView in chat
    - Fix ↓ button position relative to keyboard using height:0 View wrapper
    - Add KeyboardAvoidingView to settings character edit screen
    - Add keyboardShouldPersistTaps="handled" so 保存する button works while keyboard is open
2026-03-09 Add slide transition animations to settings screens
    Replace instant screen switches with right-to-left slide animations
    using Animated + translateX. All screens (stt-select, character-list,
    character-edit, voice-select, version) slide in from the right on
    forward navigation and from the left on back. Also converts voice
    selection from a bottom Modal to a full slide screen.
2026-03-09 Fix back navigation to use slide animation on all settings screens
    Add Animated.View to main screen so back navigation slides in from
    the left. Also fix STT option selection to slide back instead of
    instantly switching.
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2026-03-09 Fix audio not playing after interrupting playback with STT
    When startSTT is called during playback, playingRef stayed true
    causing enqueueAudio to skip playLoop for the next response.
    Fix by stopping and releasing the current Sound, clearing the queue,
    and resetting playingRef when startSTT is called during playback.
2026-03-09 Fix character not applied in voice input after switching
    send() captured selectedCharacter from stale closure when called
    from Soniox ws.onclose or STT callbacks. Added selectedCharacterRef
    that always holds the latest character, updated on select/restore,
    and used in send() payload instead of state variable.
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2026-03-12 Add toytalker_v0.1 PCB firmware with LED brightness reduction and amp fix
    Based on toytalk_demo_v2.0 code with:
    - LED brightness reduced to ~6% (value=16) to tame white LED
    - Breathing animation range adjusted (3-16) keeping same speed/feel
    - Remove setupI2SPlay() from startNormalOperation() to prevent amp
    being ON during recording mode
    - Amp soft-start via PWM ramp in processPCM() to reduce inrush current
    (investigating power dropout issue on PCB)
    [toytalker_v0.1.ino]
2026-03-22 Add toytalk_demo_v4 PCB: fix BQ24074 power issue (EN2→VBUS, ILIM 750Ω)
    - Change EN2 from GND to VBUS (AC adapter mode) to remove 500mA input current limit
    - Add R10 (750Ω) on ILIM pin for ~1.2A input current limit
    - Increase capacitors: C2/C3/C9 to 22uF, C8 to 10uF
    - Clean up toytalker_v0.1 firmware comments
    [AP2112K-3.3TRG1.step, BQ24074RGTR.step, ESP32-S3-WROOM-1-N8R8.step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]
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2026-03-23 Replace hardcoded user_123 with UUID-based owner_id for user isolation
    Generate persistent UUID per app install, use it across chat and device screens.
    ESP32 Lambda resolves owner_id from devices table to ensure logs are tied to the
    app user who registered the device, not the device itself.
2026-03-24 Add barge-in: interrupt TTS playback with button press using ISR
    Use a hardware interrupt (FALLING edge on PIN_BUTTON) to set a
    bargeInRequested flag so the button press is never missed, even
    during blocking i2s_write. processPCM() checks the flag each
    chunk iteration and aborts immediately. Conversation history is
    preserved so the session continues naturally.
2026-03-24 Replace fixed delay with silence flush to prevent audio cutoff
    Instead of delay(1500) after playback, write silence data to fill
    the I2S DMA buffer. This pushes all remaining audio through the
    speaker before stopping, preventing the last segment from being
    cut off. Also faster than the fixed delay in most cases.
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2026-04-19 Replace back button text with ← icon and improve tap area
    Remove Japanese text for i18n readiness, add hitSlop to all back buttons
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2026-04-26 Add usage detail page and cost breakdown bar chart
    - Add GET /usage/detail endpoint with per-conversation cost breakdown
    - Add usage detail screen with stacked bar chart (pure RN Views)
    - Reorder usage page: device breakdown above API type breakdown
    - Remove react-native-svg dependency (incompatible with Expo Go runtime)
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2026-04-26 Add usage tracking and cost logging to ESP32 stream Lambda
    - Add pricing cache, cost calculation, and usage table writes
    - Save computed costs (cost_stt/cost_llm/cost_tts/cost_total) to chat-log
    - Include character_id from device settings in chat-log and resolveCharacterFromDynamo
    - Style tweak: daily bar chart cost color to blue with yen unit
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2026-04-26 Fix usage write loss by awaiting all DynamoDB operations
    - Add await to addUsage calls (LLM/TTS/STT) to prevent Lambda exit before writes complete
    - Add await to saveLog to ensure chat-log with costs is persisted
    - Root cause: 4 of 35 records (11%) were lost due to fire-and-forget writes
    - Applied to both app and ESP32 stream Lambdas
2026-04-26 Show device names instead of device IDs in usage and detail pages
    - Resolve device_name from toytalker-devices table in GET /usage and GET /usage/detail
    - Display device name in usage page device section and detail page conversation cards
    - Fall back to device_id if device_name is not set
2026-04-26 Fix STT truncation and conversation history for accurate LLM context
    - Accumulate Soniox is_final tokens to prevent long speech text from being truncated
    - Add user messages to conversation history (previously only assistant was stored)
    - Move history push to after response (matching ESP32 pattern) to avoid orphan entries on failure
2026-04-26 Fix STT truncation on ESP32 by accumulating Soniox is_final tokens
    Mirrors the app-side fix: is_final tokens are stored in sonioxFinalBuf
    and combined with partial tokens for the full transcription text.
    [toytalker_mini_v0.1.ino]
2026-04-29 Add backchannel (相槌) feature for instant voice feedback
    New Lambda generates short backchannel responses (e.g. うんうん, へぇー)
    using Gemini 2.5 Flash during STT, with TTS audio cached and played
    instantly when the user finishes speaking (~1s latency). Disables
    Gemini thinking to prevent THOUGHTS text leaking into responses.
2026-04-29 Improve backchannel variety with past-backchannel avoidance and relaxed prompt
    Let LLM generate backchannels freely instead of picking from fixed examples.
    Track past backchannels per session and send them to Lambda to avoid repeats.
    Add time-aware greeting hint for first turn. Relax character speech style
    to prioritize naturalness over strict persona adherence.
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2026-04-29 Add ESP32 backchannel support with background fetch and playback
    - New Lambda: toytalker-backchannel-for-esp32-lambda (BUFFERED mode, raw PCM via isBase64Encoded)
    - ESP32 stream Lambda: add backchannel_fired flag to suppress duplicate backchannel in response
    - ESP32 sketch: FreeRTOS task for concurrent backchannel HTTP fetch during STT,
    PSRAM-cached PCM playback on STT end, UTF-8 char counting for trigger threshold,
    heap guard, abort mechanism, and proper I2S recovery on connection failure
    [toytalker_mini_v0.2.ino]
2026-04-29 Send history and past_backchannels to ESP32 backchannel Lambda
    Matches app behavior: sends last 6 conversation turns for context-aware
    backchannels and tracks up to 10 past backchannels per session to avoid
    repetition.
    [toytalker_mini_v0.2.ino]
2026-05-01 Send main Lambda request before backchannel playback for lower latency
    Reorder sendToLambdaAndPlay: connect and send request to main Lambda
    first, then play backchannel while Lambda processes. Skip backchannel
    if main Lambda data already arrived. Removes ~0.8s from total latency
    when Lambda is slower than backchannel playback.
    [toytalker_mini_v0.2.ino]
2026-05-02 Use hardware timer interrupt for LED animation to decouple from main loop
    WiFi SSL processing in ws.loop() was blocking the main loop and causing
    LED breathing speed to fluctuate with signal strength. Moving LED updates
    to a 30ms hardware timer ensures consistent animation regardless of
    network conditions. Also reduces i2s_read timeout from portMAX_DELAY to
    10ms to prevent unnecessary blocking.
    [toytalker_mini_v0.2.ino]
2026-05-02 Defer WebSocket disconnect until after I2S switch for faster transition
    Move ws.disconnect() after I2S mode switch and add timing log to measure
    disconnect latency. Setting isRecording=false first prevents i2s_read
    blocking in the main loop during the transition.
    [toytalker_mini_v0.2.ino]
2026-05-02 Reduce playback DMA buffers from 32 to 8 and revert i2s_read timeout
    DMA buffer reduction (32→8) cuts post-playback flush from 1.36s to
    ~340ms and reduces backchannel playback latency. Revert i2s_read
    timeout back to portMAX_DELAY since LED animation now uses hardware
    timer and no longer depends on loop() frequency.
    [toytalker_mini_v0.2.ino]
2026-05-02 Send Lambda request from background task to avoid backchannel delay
    Previously Lambda request was sent after backchannel playback finished,
    delaying server processing by ~1s. Now the background task on Core 0
    handles both SSL connection and request sending, so Lambda starts
    processing at ~370ms regardless of backchannel playback duration.
    Also move backchannel fetch task to Core 1 to reduce WiFi contention
    with Soniox STT stream on Core 0.
    [toytalker_mini_v0.2.ino]
2026-05-04 Fix backchannel voice matching and filter Gemini thinking text
    - Backchannel Lambda: resolve character via device_id instead of
    character_id so ESP gets the correct voice for its assigned character
    - ESP stream Lambda: disable Gemini thinking mode (thinkingBudget: 0)
    and filter out thought parts to prevent thinking text from being spoken
    - ESP: raise backchannel trigger threshold from 5 to 10 chars to reduce
    WiFi contention with STT stream
    [toytalker_mini_v0.2.ino]
2026-05-04 Add per-device backchannel ON/OFF toggle
    - App: add Switch in device settings (toy.tsx) to toggle backchannel,
    writes backchannel_enabled to DynamoDB via PUT /devices/{id}
    - Device-setting Lambda: accept backchannel_enabled in PUT /devices
    - Soniox Lambda: return backchannel_enabled from device table alongside
    temp key (fetched in parallel, no added latency)
    - ESP: read backchannel_enabled at boot and skip fetch entirely when off
    - Backchannel Lambda: remove empty-response mode that caused 15s hang
    [toytalker_mini_v0.2.ino]
2026-05-04 Centralize Soniox STT model config and add RSSI/send diagnostics
    - Soniox Lambda: return stt_model in response (env var SONIOX_MODEL)
    - ESP/App: read stt_model from Lambda instead of hardcoding
    - ESP: add send ok/fail counter and RSSI logging every 5s
    - ESP: stop LED timer interrupt during recording to avoid I2S contention
    - Add mic_test_mini diagnostic sketch for isolated STT quality testing
    [mic_test_mini.ino, toytalker_mini_v0.2.ino]
2026-05-04 Add toytalker_mini_v0.3: fix STT quality by removing LED PWM
    LED PWM (ledcAttach) was interfering with I2S recording, causing
    degraded STT transcription quality. Replaced all PWM-based LED
    control with digitalWrite and timer-based software duty cycling
    (10% brightness). All v0.2 features preserved.
    [toytalker_mini_v0.3.ino]
2026-05-04 Revert LED timer to 30ms period to reduce ISR overhead
    3ms timer was too aggressive for software PWM dimming.
    LED brightness will be controlled via hardware resistor instead.
    [toytalker_mini_v0.3.ino]
2026-05-04 Reduce WiFi retry count from 5 to 2 to avoid long waits
    [toytalker_mini_v0.3.ino]
2026-05-04 Speed up boot sequence: parallelize I2S setup with WiFi connect
    - Remove unnecessary disconnect+delay on initial boot
    - Poll WiFi status every 100ms instead of 1000ms
    - Setup I2S recording during WiFi connection wait
    - Skip redundant I2S setup in startSTTRecording after boot
    [toytalker_mini_v0.3.ino]
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2026-05-04 Improve backchannel and main Lambda prompt to reduce duplication
    - Remove hiragana-preference instruction from main Lambda base prompt (no longer needed with Sakura TTS)
    - Add backchannelHint to prevent echo/greeting duplication when backchannel has fired
    - Backchannel prompt: remove character speech pattern, prioritize natural aizuchi
    - Increase backchannel max length from 10 to 15 chars
    - Unify backchannel trigger threshold to 7 chars (app: 5→7, ESP: 10→7)
    - Add deploy.sh for app backchannel Lambda
    - Add Lambda deployment rule to CLAUDE.md
    [toytalker_mini_v0.3.ino]
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2026-05-05 Suppress redundant preamble after tool call results
    - Add instruction to skip "調べてきた" etc. after receiving search results
    - LLM now goes straight to content after tool execution
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2026-05-16 Remove old ESP32 Lambda and add system architecture to CLAUDE.md
    - Delete toytalk-stream-handler-for-esp32-lambda (replaced by toytalk-api-stream-for-esp32-lambda)
    - AWS Lambda function also deleted
    - Add system architecture overview, Lambda/DynamoDB table references to CLAUDE.md
    - Update ZakiCorp TTS section to reflect auto-startup via Task Scheduler
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2026-05-16 Add .vscode settings to enforce UTF-8 (fix mojibake)
    files.encoding=utf8 + autoGuessEncoding=false でUTF-8固定。
    統合ターミナル(PowerShell)の出力もUTF-8化。日本語環境での文字化け再発防止。
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2026-07-06 Add ESP32 firmware v0.4 with playback jitter buffer
    - Add 512KB PSRAM ring buffer + dedicated playback task (Core 0),
    raising network jitter tolerance from ~0.34s (DMA only) to ~5.4s
    - Prebuffer ~0.34s before playback start / rebuffer on underrun
    - Fix BLE mode LED stuck solid when entered via long-press
    (LED timer was stopped during recording and never restarted)
    - Add LED states: slow blink=preparing, solid=ready to talk,
    blink=playing, fast blink=BLE provisioning
    - Remove pointless 5s preconnect wait at cold boot
    - Retry Soniox key fetch 3x (device died silently after
    BLE Wi-Fi switching when the first fetch failed)
    [toytalker_mini_v0.4.ino]
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2026-07-06 Boost playback volume 1.5x with clip protection, shorten BLE long-press to 1.5s
    - Add saturation clamp in monoToStereo to prevent int16 wraparound
    distortion when digital gain pushes samples past full scale
    - VOLUME 1.0 -> 1.5 (measured ~70dB vs 60dB reference keychain toy)
    - LONG_PRESS_MS 3000 -> 1500 for quicker BLE provisioning access
    [toytalker_mini_v0.4.ino]
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2026-08-11 Add per-turn WiFi/playback quality stats to ESP32 firmware
    Log a [STATS] summary (real underrun count, RSSI avg/min/samples) after
    each playback turn to quantify the v0.1 board grounding issue and verify
    the v0.2 ground fix. Underruns are confirmed on playback restart so the
    end-of-stream drain race is not miscounted. RSSI is sampled every 500ms
    during playback and every 5s while recording.
    [toytalker_mini_v0.4.ino]
2026-08-11 Refine underrun stats: session carry-over fix and backchannel label
    Clear the pending-underrun flag on playerStart so the end-of-stream race
    from a previous session (e.g. backchannel) is not counted against the
    next one, and add a bc= field to [STATS] since backchannel turns start
    playback from a server-side burst and legitimately show one benign
    rebuffer when bandwidth is marginal.
    Baseline captured on the v0.1 board (same spot, RSSI ~-76): choppy mode
    shows underruns=6, pressing the module drops it to 1 with identical
    RSSI - confirming the ground-plane issue degrades link quality, not
    signal strength.
    [toytalker_mini_v0.4.ino]
